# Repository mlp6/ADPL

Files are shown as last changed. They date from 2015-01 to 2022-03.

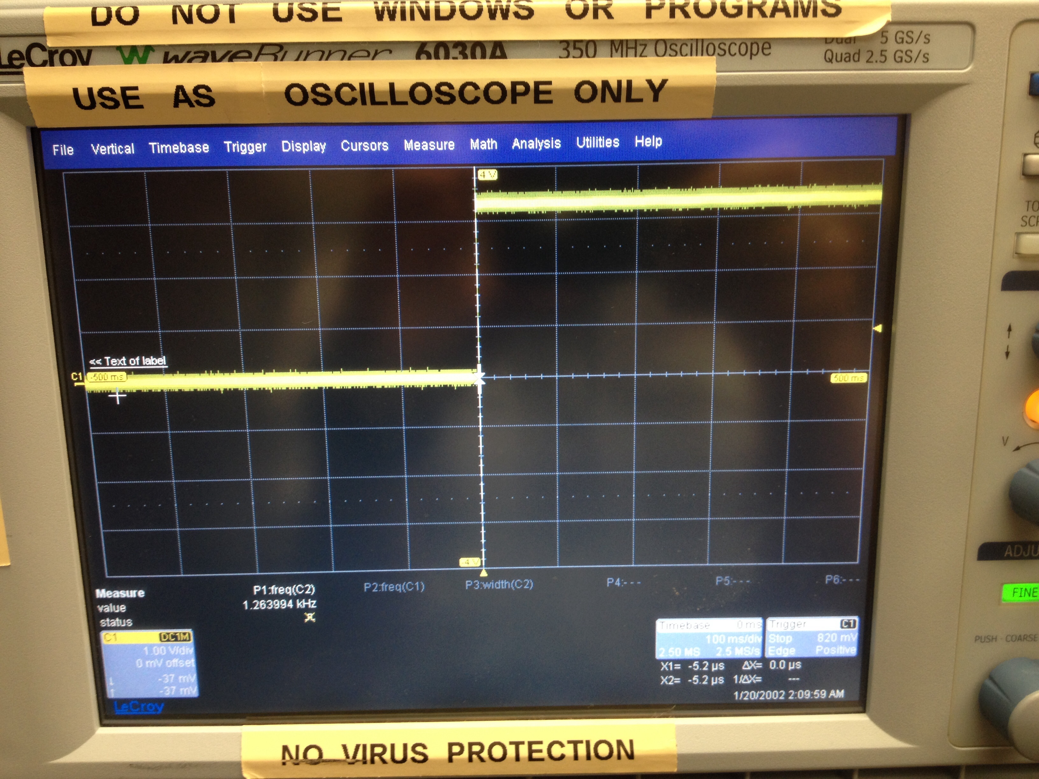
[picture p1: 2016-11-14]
hardware/picture_aids/one-shot-test/oscopeoutput1.jpeg

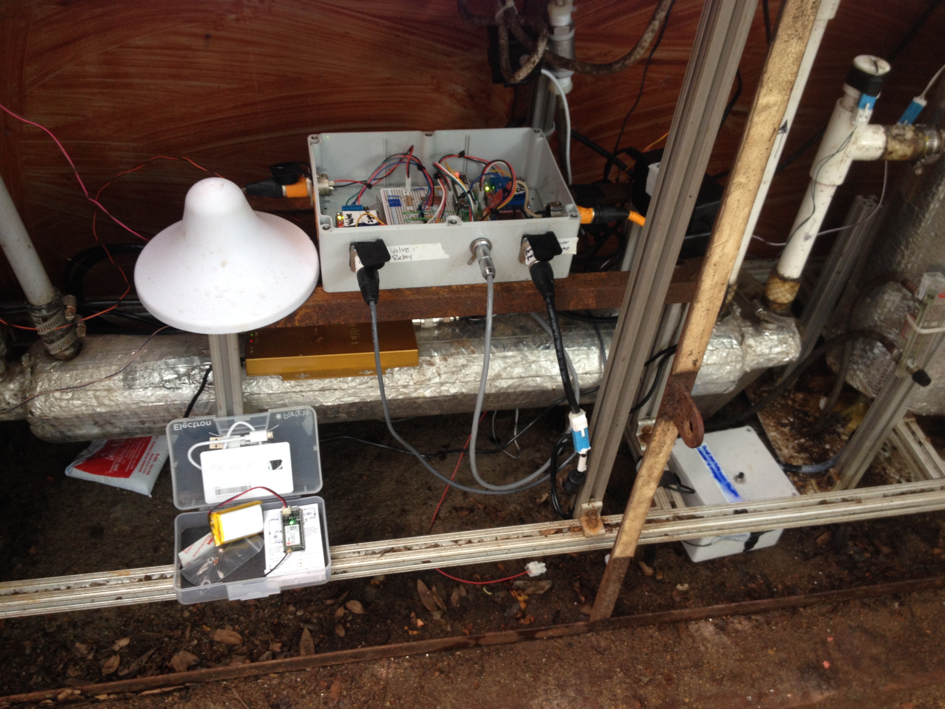
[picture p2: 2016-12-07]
hardware/picture_aids/FieldPics/IMG_8696.JPG

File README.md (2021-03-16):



# Anaerobic Digestion and Pasteurization Latrine (ADPL) 

Project Overview: http://sanitation.pratt.duke.edu/onsite-treatment

**This project is dormant, and the web server has been taken offline.**

## Particle Electron (MCU)
The active MCU software is in `software/ADPL_electron` using the `v6.2.0` Electron firmware.

## Web Server
~~Live data streaming is available to view at http://adpl.palmeri.io.~~

The web application is responsible for listening to real-time streaming data from different ADPL stations, saving that data to a database, and making those data available for inspection and analysis via a RESTful API and dashboard-like front end. The web server performs several additional functions like integrating with Twilio to allow for text-based alerts and interaction (with many features yet to be implemented). 

### Backend (NodeJS) Docker Setup
The server can be run using `docker-compose` with the following steps: 
1. `cd software/cloud-dashboard/`
2. `DB_DATA=/scratch/adpl/data docker-compose up`

### Frontend (ReactJS) Configuration
The frontend is manually built, and its assets captured by the Docker backend.  After changes are made to the frontend, you need to:
1. `cd react-client/`
2. `npm install`
3. `npm run build`
4. Repeat the Docker setup above, adding the `--build` option to `docker-compose up --build` to rebuild the image.

## Data Download
As simple as: http://adpl.palmeri.io/api/data/temp/1

## Contributors
- Aaron Forbis Stokes (a.forbis.stokes@gmail.com)
- Daniel Hull
- Suyash Kumar (suyash.kumar@duke.edu)
- Graham Miller
- Cal Nightingale
- Jawad Hoballah
- Mark Palmeri (mlp6@duke.edu)

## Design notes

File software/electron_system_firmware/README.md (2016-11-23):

How to Flash Electron Firmware OTA
==================================

* Download parts of desired firmware release from: https://github.com/spark/firmware/releases  There are usually 2-3 parts of ``*.bin`` firmware that need to be downloaded.

* With a functional and logged-in particle CLI client, you can then flash the device over the air with the syntax: ``particle flash $DEVICE_ID $FIREMWARE_PART#.bin``, where ``$DEVICE_ID`` is the electron (by name or numeric ID).  You need to execute this command sequentially for each "part" of the binary firmware.

* The device should automatically reboot after each incremental flash.

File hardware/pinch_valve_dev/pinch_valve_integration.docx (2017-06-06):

Designed and Implemented by Graham Miller, Aaron Stokes, and Daniel Hull

Guided by Dr. Palmeri

Pinch Valve Integration

This document has been written to produce a written documentation of the integration of the pinch valve into the anaerobic digestion pasteurization latrine. With hope, this document will help streamline the groups thoughts and ensure robust development of a motor that will produce the desired outputs.

The problem statement can be most aptly understood from a plot. Please observe the green HTR line. The temperature probe is monitoring the inside of the pasteurization system. As the current system is designed, the microcontroller works to hold temperatures between 68 and 72 degrees to effectively eliminate bacterium from the processed effluent. The sudden drop in temperature is a resultant of an influx of fluids into the pasteurization system. This occurs from a large onset of individuals using the bathroom at consistent patterns daily, notably for instance the hours of 6-10 A.M. Without controlled flow, an influx of waste fluids at room temperature can cause the pasteurization system to destabilize. Several problems occur from this, the waste has not been adequately digested, and the pasteurization does not work efficiently. A controlled valve system could solve this problem.

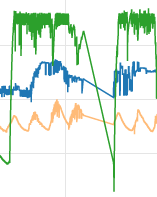
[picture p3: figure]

The controlled valve system has been designed to use a linear stepper motor. (Seen here http://www.omc-stepperonline.com/nema-23-noncaptive-linear-stepper-motor-56mm-body-150mm-lead-screw-t11-x-2-p-150.html) This bipolar stepper has the following specs (2.0 A rated, a recommended voltage of 24-36 V) An adjustment of the stepper motor step wise can move up and down a screw that pushes down or opens flow through a master flexing tube. This tube through lab testing has the following flow properties.

There appears to be a clear exponential rate in flow rate as a function of the stepper motor from the closed position. The vision is to control of the stepper motor from an Easy Driver(ED) board. (https://learn.sparkfun.com/tutorials/easy-driver-hook-up-guide) Notable specifications of the Easy Driver include a maximum of 750mA per phase or 1.5 A for the bipolar arrangement. The ED board contains options for microstepping, which we will not use. It will have a power input of 6V to 30V. A 12V power supply should suffice. The power supply should be able to supply a spec of 2A. It can supply a maximum load voltage of 30V. The ED board responds to input digital logic of 0-5V on two pins (DIR and STEP) which set the direction and step amount respectively. The maximum step frequency is 500KHz. A microcontroller board will control the digital outputs to the ED with three pins utilized, one for each of the DIR, STEP, and SLEEP pins.

The system should be responsive to these sudden changes in the amount of liquid waste as to adequately allow for flow to enter throughout the day. The system will feedback from a number of bucket tips per a unit time. The length of time will determine the sensitivity by which the step motor will adjust flow rate. As this new flow is over the course of tens of minutes to hours, the time will need to be over the course of minutes. Responsive code will be implemented in a C++ class and implemented in the .ino file.

Key system failures introduced by this valve would be a full closure as to prevent backup in the digester. Monitoring where the current position is in software or a lack of bucket tips are potential software approaches to ensure failure of this nature doesn’t happen. It’s important to note control boards and stepper motors of the ED nature must be isolated from dust. One important consideration is that the ED generates a lot of heat if used constantly. This will need some circulation as to prevent the operating conditions to exceed its designed standard. Sleep functionality implemented in the prototype also seemed to reduce the heating of the ED board. The board did not get even close to warm when this functionality was implemented. The pins of the linear step motor from the ED board must be in precise orientation. Any variation results in improper control of the linear step motor. If the linear step controller were to get off, and move all to the top I have gotten the pin stuck in that position before. Resetting the position and monitoring the position will be important.

A link to a pdf that I found issue for common stepper motor failures is the following. (http://www.anaheimautomation.com/manuals/forms/Common%20Causes%20for%20Step%20Motor-Driver%20Problems.pdf)

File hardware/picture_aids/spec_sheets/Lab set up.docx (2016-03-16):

Arduino Lab Setup

Arduino Board Pins

- Pin 2 – Valve
- Pin 4 – Pump
- Pin 7 – Ignitor
- Pin 8 – Level sensor low
- Pin 10 – SD card
- Pin 13 – Level sensor high
- Analog 0-4 – Thermistors 1-5
- Analog 5 – Level sensor 4-20 mA
- 3.3V – Red line goes to power line on breadboard
- Ground – Black line goes to ground line on breadboard
- AREF – Red to positive line on breadboard (analog positive line)

Breadboard Connections

Thermistors

- One end of each goes to ground line (here connected to black wire)
- Other end goes in series of red wire – resistor – analog input wire
- Other end of resistor goes to power line
- Thermistor 1: Red C5, Resistor B5-Power 2, Analog A5-A0
- Thermistor 2: Red E8, Resistor C8-Power 7, Analog A8-A1
- Thermistor 3: Red C11, Resistor B11-Power 10, Analog A11-A2
- Thermistor 4: Red E14, Resistor C14-Power 12, Analog A14-A3
- Thermistor 5: Red C17, Resistor B17-Power 15, Analog A17-A4

Pump

- Pump relay signal – Pin 4
- Pump relay ground – Ground 6
- Pump relay power – Power 1

Level Sensor – Sends signal when below low and above high/analog 4-20 mA output

- Depth positive (red) – To power supply
- Depth negative (black) – To power supply
- Depth relay common (brown) – 0+13
- Depth relay high (purple) – Pin 8
- Depth relay low (yellow) – Pin 13
  - Or
- Negative line from sensor to B23, 100 Ω resistor C23 to D21, Negative power E21
  - Analog wire A21-A5

Ignitor/Value

- Ignitor Signal – Pin 7
  - Facing issue with small current flowing through Pin 7, temporary set up
  - Pin 7 to A26 – Resistor C26 to C29 – Signal E26 to Board – Wire E29 to Ground 30
- Valve Signal – Pin 2
- Positive – Power 25
- Ground – Ground 23

Arduino commands

- Valve – output
- Ignitor – output
- Pump – output
- MinDepth & MaxDepth – input

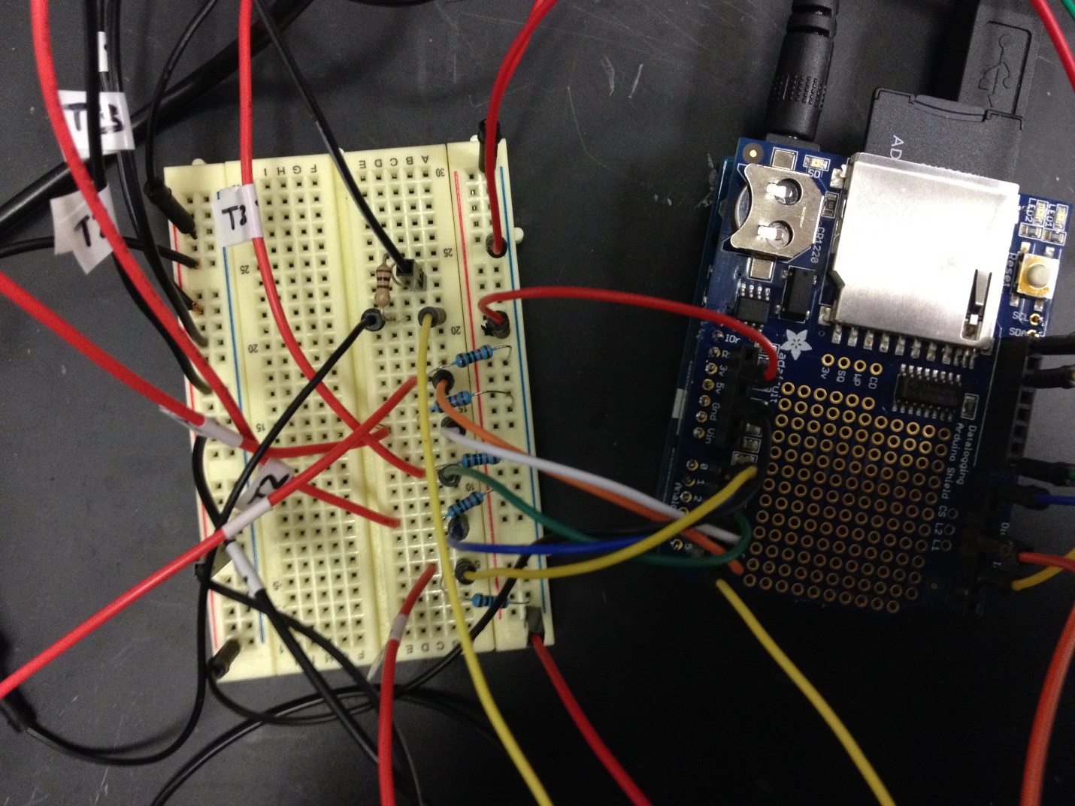
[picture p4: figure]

5 thermistors, Red to 10K resistor

5 thermistors, Black to ground

Ground

AREF

Level power

Level sensor

3.3V

Material Specs

Arduino Uno

- Input: 7-12VDC
- Operating voltage: 5VDC
- DC Current per I/O Pin: 40mA
- DC Current for 3.3V Pin: 50mA

Relay

- 2 Channel 5V Relay Shield (http://www.amazon.com/SunFounder-Channel-Shield-Arduino-Raspberry/dp/B00E0NTPP4) module for Arduino

Gas valve – CWX-15Q, CR-02

- (Size?) NPT threads, Max pressure 1 MPa, Max temp 100 °C
- Input: DC 12V, Max 167 mA (Max 2W)
- Available from: Alibaba (http://www.alibaba.com/product-detail/CWX-15Q-series-3-4-SS304_1809778717.html)
- $15
- Three wire: Red-power, Blue-ground, Yellow-signal

Ignitor – Grill Pro Universal Electronic Ignitor Kit (20620), Model SD-E5

- Input: DC 1.5V, 280-320 mA (0.42-0.48 W)
- Output: 10 kV
- Available from: Grillpro.com or Amazon (http://www.amazon.com/GrillPro-20620-Electric-Button-Igniter/dp/B000FJVKNM)
- $25

Level Sensor

- Input: DC 24V (or 12V), 2 mA (0.5 W consumption); 400Ω max loop resistance
- The 4-20 mA output can be used to provide the proportional level of liquid in any tank or vessel. The 4 relays can be used to control multiple combinations of pumps, valves and/or alarms. The signal can be connected to any device that accepts a loop powered 4-20 mA signal or relay output, such as a PLC, SCADA, DCS, display, controller, etc
- Output: 4-20 mA (when loop powered)
- Range: 5-125 cm (2-49”)
- Accuracy: 3 mm
- Temp range -7-60 °C (31-140 °F), Max pressure 30 psi
- 1” NPT thread
- The red and black wires can be extended up to 1,000 feet using a 22 gauge or larger wire, however do not extend the green and white wires
- Available from:
- $$

Pump – SeaLand TW-Series (T12) Macerator Pump

- Input: DC 12V, 6 A (48 W)
- Flow: 1136 L/hr
- Lift: 3 m (10 ft)
- Fittings: 1 – 1 ½”, not threaded, use rubber reducing bush to adapt to PVC
- Available from: Amazon (http://www.amazon.com/SeaLand-Sanipump-Discharge-Macerator-Whisper/dp/B000XBH2D4)
- $300

Valve wiring diagram:

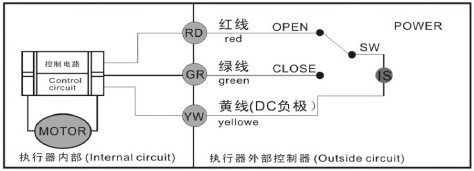
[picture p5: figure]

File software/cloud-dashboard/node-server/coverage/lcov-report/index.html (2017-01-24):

# All files

34.44% Statements 31/90

0% Branches 0/14

9.09% Functions 2/22

36.9% Lines 31/84

File | | Statements | | Branches | | Functions | | Lines
node-server | | 50% | 10/20 | 100% | 0/0 | 33.33% | 2/6 | 50% | 10/20
node-server/api | | 10% | 2/20 | 0% | 0/8 | 0% | 0/8 | 12.5% | 2/16
node-server/config | | 16.67% | 1/6 | 0% | 0/2 | 0% | 0/1 | 16.67% | 1/6
node-server/handle-device | | 18.75% | 6/32 | 0% | 0/4 | 0% | 0/7 | 20% | 6/30
node-server/models | | 100% | 8/8 | 100% | 0/0 | 100% | 0/0 | 100% | 8/8
node-server/tests/handle-device | | 100% | 4/4 | 100% | 0/0 | 100% | 0/0 | 100% | 4/4

Code coverage generated by istanbul (http://istanbul-js.org/) at Wed Jan 18 2017 23:22:50 GMT-0800 (PST)

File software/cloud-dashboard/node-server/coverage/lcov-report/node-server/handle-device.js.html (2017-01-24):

# All files / node-server handle-device.js

50% Statements 10/20

100% Branches 0/0

33.33% Functions 2/6

50% Lines 10/20

1
2
3
4
5
6
7
8
9
10
11
12
13
14
15
16
17
18
19
20
21
22
23
24
25
26
27
28
29
30
31
32
33
34
35
36
37
38
39
40
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

1x
1x
1x

1x
1x
1x

1x
1x
1x

1x

/*
* handle-device.js
* This module handles listening to the particle device stream and saving received data
* in real time to the database (LogEvent models). It also has capability to send push
* notifications to clients using socketio when new packages arrive.
* @author: Suyash Kumar <suyashkumar2003@gmail.com>
*/
var EventSource = require('eventsource'); // Pull in event source
var TempUtil = require('./handle-device/temp-util');
var BucketUtil = require('./handle-device/bucket-util');

function handleTemperatureMessage(message, io) {
try {
const parsedData = TempUtil.parseMessage(message);
TempUtil.addRecord(parsedData, io);
} catch (err) {
console.log("ERROR: Parsing Temps Message", message, err);
}
}

function handleBucketMessage(message, io) {
try {
const parsedData = BucketUtil.parseMessage(message);
BucketUtil.addRecord(parsedData, io);
} catch (err) {
console.log("ERROR: Parsing BUCKET Message", message, err);
}

}

function handleStream(deviceUrl, io){
var es = new EventSource(deviceUrl); // Listen to the stream

// Add temperature event listener
es.addEventListener("TEMPS", (message) => {
handleTemperatureMessage(message, io);
});

// Add bucket tip listener
es.addEventListener("BUCKET", (message) => {
handleBucketMessage(message, io);
});

es.onerror = function (err) {
console.log("ERROR (Likely Event Source)");
console.log(err);
};
}

module.exports = {
handleStream, // Export handleDevice function
handleTemperatureMessage,
handleBucketMessage
}

Code coverage generated by istanbul (http://istanbul-js.org/) at Wed Jan 18 2017 23:22:50 GMT-0800 (PST)

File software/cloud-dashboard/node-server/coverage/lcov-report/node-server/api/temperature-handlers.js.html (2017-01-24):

# All files / node-server/api temperature-handlers.js

10% Statements 2/20

0% Branches 0/8

0% Functions 0/8

12.5% Lines 2/16

1
2
3
4
5
6
7
8
9
10
11
12
13
14
15
16
17
18
19
20
21
22
23
24
25
26
27
28
29
30
31
32
33
34
35
36
37
38
39
40
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

1x

1x

/*
* temperature-handlers.js
* Module to hold all API functions dealing with temperature
* events
* @author: Suyash Kumar <suyashkumar2003@gmail.com>
*/
var TemperatureEvent = require('../models/temperature-event');

module.exports = {

list: function(req, res){
TemperatureEvent.find({}, function(err, records){
if(err) res.send(err);
res.json(records);
});
},
listLocAll: function(req, res){
TemperatureEvent.find({loc: req.params.loc}, function(err, records){
if(err) res.send(err);
res.json(records);
});
},
listLoc: function(req, res){
TemperatureEvent.find({loc: req.params.loc})
.sort({time:-1})
.limit(9000)
.exec(function(err, records){
if(err) res.send(err);
res.json(records);
});
},
listLastNDays: function(req, res) {
const currentDate = new Date();
//TODO: add validation on req.params.days
currentDate.setDate(currentDate.getDate() - parseInt(req.params.days));
TemperatureEvent.find({loc: req.params.loc, time: {'$gte': currentDate}})
.sort({time: -1})
.exec((err, records) => {
if(err) res.send(err);
res.json(records);
});
}

}

Code coverage generated by istanbul (http://istanbul-js.org/) at Wed Jan 18 2017 23:22:50 GMT-0800 (PST)

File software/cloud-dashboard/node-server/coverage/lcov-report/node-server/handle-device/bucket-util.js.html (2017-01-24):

# All files / node-server/handle-device bucket-util.js

23.08% Statements 3/13

0% Branches 0/2

0% Functions 0/3

25% Lines 3/12

1
2
3
4
5
6
7
8
9
10
11
12
13
14
15
16
17
18
19
20
21
22
23
24
25
26
27
28
29
30
31
32
33
34
35
36
37
38
39
40
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

1x
1x

1x

/*
* handle-device/bucket-util.js
* A set of utility functions used to parse and save
* bucket events published from ADPL systems.
* @author: Suyash Kumar <suyashkumar2003@gmail.com>
*/

var BucketEvent = require('../models/bucket-event');
var locMap = require('../config/device-map.js').locMap;

/*
* addRecord
* Responsible for adding a bucket-event record
* to the database
*
* @param {object} parsedData: Output from parseMessage below
* @param {object} io: socketio object
*/
function addRecord(parsedData, io) {
var newBucketEvent = {
coreid: parsedData.coreid,
time: new Date(parsedData.published_at),
loc: locMap[parsedData.coreid],
data: parsedData.data,
}

console.log(newBucketEvent);
var newRecord = new BucketEvent(newBucketEvent);
newRecord.save(function(err, event) {
if (err) console.log("error saving bucket event to database", err);
});
io.emit("BUCKET", newRecord);

}

/*
* parseMessage
* Parses bucket event published data from
* ADPL devices.
*
* @param {object} Particle publish message
* @return {object} Parsed data
*/
function parseMessage(message) {
deviceData = JSON.parse(message.data);
deviceData.data = parseInt(deviceData.data);
return deviceData;
}

module.exports = {
parseMessage,
addRecord,
}

Code coverage generated by istanbul (http://istanbul-js.org/) at Wed Jan 18 2017 23:22:50 GMT-0800 (PST)

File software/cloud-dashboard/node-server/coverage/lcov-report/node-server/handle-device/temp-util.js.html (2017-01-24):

# All files / node-server/handle-device temp-util.js

15.79% Statements 3/19

0% Branches 0/2

0% Functions 0/4

16.67% Lines 3/18

1
2
3
4
5
6
7
8
9
10
11
12
13
14
15
16
17
18
19
20
21
22
23
24
25
26
27
28
29
30
31
32
33
34
35
36
37
38
39
40
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

1x
1x

1x

/*
* handle-device/temp-util.js
* A set of utility functions used to parse and save
* temperature events published from ADPL systems.
* @author: Suyash Kumar <suyashkumar2003@gmail.com>
*/
var TemperatureEvent = require('../models/temperature-event');
var locMap = require('../config/device-map.js').locMap;

/*
* addRecord
* Responsible for adding a temperature-event record to
* the database.
*
* @param {object} parsedData: See output from parseMessage function below
* @param {oject} io: socketio object
*/
function addRecord(parsedData, io){
var newTemperatureEvent= {
coreid: parsedData.coreid,
time: new Date(parsedData.published_at),
loc: locMap[parsedData.coreid],
temps: {
HXCI: parsedData.HXCI,
HXCO: parsedData.HXCO,
HTR: parsedData.HTR,
HXHI: parsedData.HXHI,
HXHO: parsedData.HXHO
},
valveStatus: parsedData.V // Null if doesn't exist
}

console.log(newTemperatureEvent);
var newRecord = new TemperatureEvent(newTemperatureEvent);
newRecord.save(function(err, event){
if(err) console.log("error in saving to database"+err);
})
io.emit(newTemperatureEvent.probeid, newRecord);
}

/**
* parseMessage
* Responsible for parsing a Particle Temperature Publish
* message from the ADPL platform. A sample message
* looks like:
* {
* "data": {
* "data":"HXCI:18.9,HXCO:21.8,HTR:80.6,HXHI:22.7,HXHO:19.0",
* ""ttl":"60",
* "published_at":"2016-12-02T06:18:25.026Z",
* "coreid":"4b0031000d51353432393339"
* }
* }
* This function returns a map of all the transducer fields to
* corresponding values along with published_at and coreid
* (e.g. {HXHO: 100, ... , coreid: "", published_at: ""})
* @param {object} message
* @return {object} a map of data fields to their values (including transducers)
*/
function parseMessage(message) {
deviceData = JSON.parse(message.data);
const splitData = deviceData.data.split(",");

// Parse Transducer data
const parsedData = splitData.reduce((result, current) => {
const currentSplit = current.split(":");
result[currentSplit[0]] = currentSplit[1];
return result;
}, {});

// Add metadata
parsedData['published_at'] = deviceData['published_at'];
parsedData['coreid'] = deviceData['coreid'];

return parsedData;
}

module.exports = {
parseMessage,
addRecord
}

Code coverage generated by istanbul (http://istanbul-js.org/) at Wed Jan 18 2017 23:22:50 GMT-0800 (PST)

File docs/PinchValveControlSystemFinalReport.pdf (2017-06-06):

PinchValve Control System Final Report By Daniel Hull
With Notes for Graham, Dr. Forbis-Stokes, Suyash and Dr. Palmeri and additional relevant personnel

Final Deliverables
- Robust pinch valve software control system
- Attach Interrupt Structure for resetting system, moving up, and moving down using push-buttons
- PinchValve class with adjustable motor speed, resolution (amount in mm up or down), position monitoring and logical bounds, and cloud monitoring of the position variable, and easy to adjust parameters for further optimization
- Clog clearing control development to monitor when that may occur, adjusting net position as well if system is not clearing clog effectively.
- Bucket tip response based on differential in the previous two bucket times with four different cases
- Intense flow much greater than 10-15 L/hr, happens during clog clearing scenario, causes rapid closing adjustment
- Flow is within bounds, nothing happens
- Flow in L/hr is less than bounds, small adjustment open
- Flow in L/hr is greater than bounds but not extreme case, small adjustment closed
- Verbose naming performed throughout and hopefully good C++ practice
- Hardware Development and progress toward a completed PCB
- Investigation into whether the EasyDriver is the right board for us, notes made for optimal usage
- Schematic best practices observed and fixed for a readable professional job
- Selection of new voltage regulator in accordance with Greg Mimack’s recommendation
- Protection of the relay system with diodes also in accordance with Greg Mimmack’s recommendation w/ additional thoughts
- Beginning’s of selection of desirable PCB components both as SMTs and Through Holes
- Presentation for the Gates Foundation
- Initial Testing
- Educational Resources, notably this report as to provide an opportunity for everyone to understand the MCU and the system
- Further Development

I. Robust pinch valve software control system
A. Attach Interrupt Structure for resetting system, moving up, and moving down using push-buttons

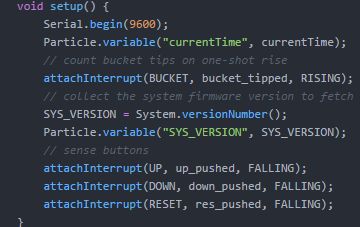
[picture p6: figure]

Setup Loop All on pinchValve_enhancement

Everything begins with the setup loop in the microcontroller code. It runs this first once the cellular connection has been enabled. Notable for us are the two bottom attach interrupt functions. Essentially it will always listen for these pins to fall while in the ‘loop’ section of the code (MCUs are always in either the setup at the beginning and then otherwise always in the loop function)

Particle Syntax for attachInterrupt

This is their syntax (the way to use them). UP and DOWN are constants set in pinmapping.h, they will execute up_pushed function and down_pushed function when their pin, usually held to 3.3V, falls to 0V. Reset’s attach interrupt will work similarly. These are the pins hooked up to push buttons. They only will happen when the push buttons are pressed. It’s how it’s all setup in the hardware.

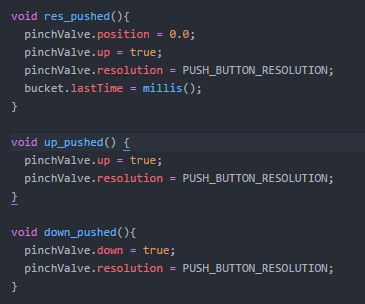
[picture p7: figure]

attachInterrupt function implementation

Here are those corresponding functions. There’s this ‘object’ known as pinchValve that you can think of like a box in the microcontroller code. There are functions (also known as methods) and variables you can access inside the box using the dot notation here. If up is pushed it sets to true and the resolution variable is set to push button resolution which is a constant. This is relevant in the loop as we will see in just a second. These functions (down_pushed, etc.) should never be activated long (a general rule of thumb), so I set the variables to do something that will cause a change when the MCU goes back into the ‘loop’. One last note, when reset is pushed the bucket.lastTime resets so the next tip time adjustment will be based around the when the reset was pushed.

The idea for the technician in the field is he/she could move the motor to the fully closed state and press the reset and it’d move to a state that will allow flow and allow the tip time control system to do its work. Given the lack of experience of many of the technicians in the field of these low-income nations, this should be a pretty simple reset.

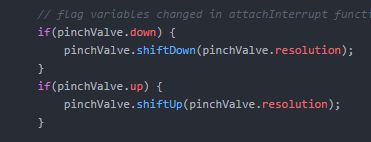
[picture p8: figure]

So here it is. We are back in the loop and if ever the pinchValve.down is true or the pinchValve.up is true (up and down are the variables inside this ‘object’ (we are calling a box)) the function inside the box will happen at the resolution that was set in the previous function! This is very dynamic because a whole range of responses could cause this such as a bucket tip or a push button pressed and it will cause the valve to move up and down by whatever is set as the resolution (mm).

B. PinchValve class with adjustable motor speed, resolution (amount in mm up or down), position monitoring and logical bounds, and cloud monitoring of the position variable, and easy to adjust parameters for further optimization

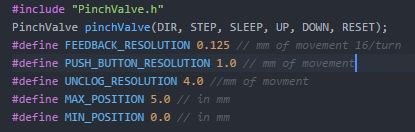
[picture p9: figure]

Here is the creation of the object (box analogy) pinchValve and the constants that were discussed earlier. In C++ #define is one way to set a variable. Right now we have mm of movement being our constants. I’m keeping it as mm of movement vs. other possible metrics because that will be constant between motors, the number of steps for the stepper motor will be variable depending on microstepping, so that is not a good metric to tell the motor to move by.

Feedback resolution, push button resolution, and unclog resolution were all variables set in correspondence with Graham who did a lot of initial testing of how flow varies as a function of of these movements about where the system is reset. The methods will translate these mm of movement into the number of turns it needs to do to get there.

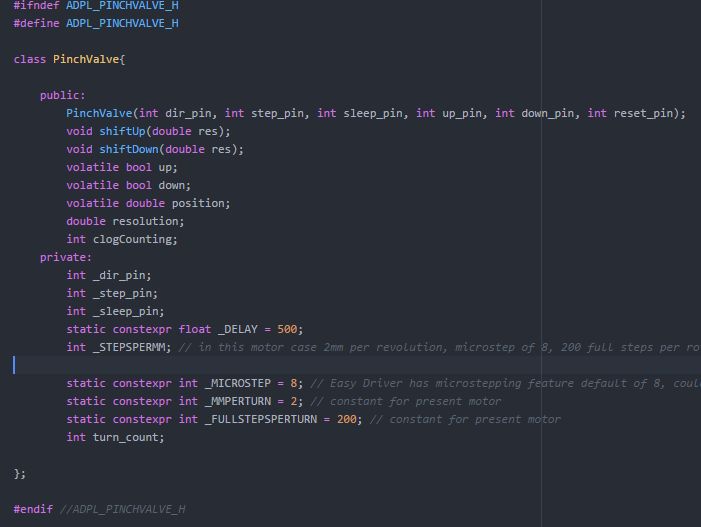
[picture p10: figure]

The header in C++ helps us define the variables for the class and the functions that can be used. The object can be accessed where the object is created. So in our case this is in the ADPL_electron.ino file for the MCU (this was defined in the figure above this). There are two public functions these are shiftUp and shiftDown. The position, up, and down are necessary in the if statements to ensure the motor works when it’s called. A true variable activates it, a false closes it. The position variable monitors the position. The resolution is set externally in the .ino file to be passed into the function which tells the motor how far to turn. The clog counter will be explained more in a minute.

Several private variables are created. The pins are only accessed in the class so they don’t need to be public. ‘_’ leads all private variables. A few are static. _Delay is in microseconds, changing this will speed up the motor. _Microstep, _MMPERTURN, and _FULLSTEPPERTURN are all used to calculate the private variable _STEPSPERMM. This all is structured to understand where the number of steps per mm comes from for whoever comes after me. This could be adjusted to a new structure if we want to change the system’s microstepping (not sure why this would be useful) or if we choose a new driver, or a new motor. It’s important to remember the three are constants under the current motor choice and driver selection and they would need to be changed if the selections changed.

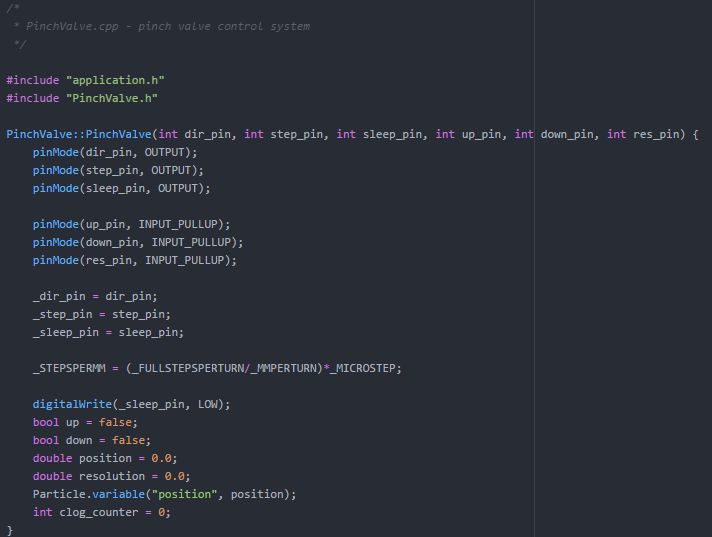
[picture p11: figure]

Constructor

PinchValve has a .cpp file in pair with its header to specify the functionality of the class more clearly. Verbose naming is used throughout. The pins are initiated at the beginning as outputs. This means digital pulses will be sent from these pins. For anyone who is unfamiliar the beginning function is the constructor. This initiated when the object is created. The pins are defined as output pins and the other three which are all the attach interrupt pins, (up, down, and reset) are set as input_pullup in agreement with Particle documentation. Up and down, components of this object, are set to false initially to make sure the motor doesn’t start trying to move up and down constantly. Again, false means resting, true means move. The steps per mm calculation is made here to show where this variable comes from. The other three pins, dir, step, and sleep are set private to this class and initialized here. The position starts at 0 when the system totally resets. This should be fixed in future iterations when the watchdog becomes available. Monitoring of this position should be available over the particle cloud. For one not familiar with the hardware, the following pins do the following

_dir_pin - sets the direction (set in pinmapping.h) (HIGH means move a direction, LOW the other) _step_pin - tells the chip to initiate steps if a cycle of LOW-HIGH-LOW happens that is at least a few microseconds (see the Easy Driver Chip Selection Datasheet)
_sleep_pin - ESSENTIAL, this turns on and off the driver to only work when a step pattern needs to be initiated.

Motors and drivers can really overheat. It’s essential these are plugged in correctly and the firmware is coded properly. Pin outputs must stay constant whether in Kenya or the Phillipines to make sure we do not have accidents.

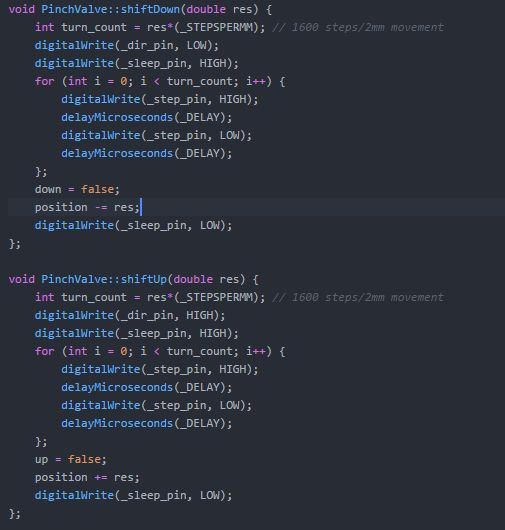
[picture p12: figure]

As seen earlier shiftDown and Up will occur when the up/down variables are set to true. The chip on the stepper driver (the EasyDriver board) responds to a series of digital pulses on its step pin. A for loop causes these pulses to be sent in a series length corresponding to how far the valve needs to move. For this instance, we should see an 800 steps per MM calculation so if the resolution is 1 MM we will see 800 cycles of the for loop telling the motor to move.

Sleep functionality makes sure the driver doesn’t overwork itself and only works when it needs to. It’s usually set low and only set high when it needs to be turned on.

Up and Down are set to false to turn off the movement once a cycle of the method is complete.

C. Clog clearing control development to monitor when that may occur, adjusting net position as well if system is not clearing clog ef ectively.

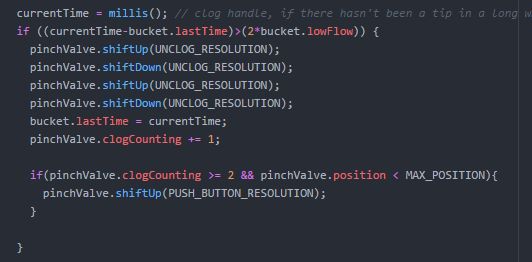
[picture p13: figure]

If a large amount of time has passed, maybe twice the lowest flow bound there is likely a clog in the system. The motor should fully open and fully close two times. This was an idea from Graham to help try to clear the clog. It will make sure to only do this once using the bucket.lastTime variable.

It will also count up one every time this process is repeated without a tip. If two have passed without a tip occurring, we will see a movement of 1 MM. Right now this is a sizeable movement. It will not move too high.

D. Bucket tip response based on dif erential in the previous two bucket times with four dif erent cases

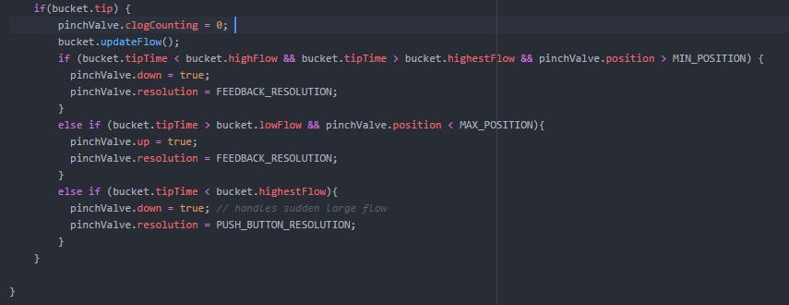
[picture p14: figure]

pinchValve isn’t the only box. An old structure of prior development is the tip variable. Like the reset, up, down pushed functions there is an Attach Interrupt for bucket. If you take a look up top in the setup function you’ll see it. It’s set to true to initiate the following action. Bucket has an updateFlow function that is then activated this calculates the differential of time between the current tip and the last tip. This is compared to desired values. More on this later.

Basically, if the tip time differential is really low i.e. high flow and the valve can still go lower (position is constantly monitoring) The down variable will be set to true and the resolution set to our 1/16th of a turn idea. (for Graham) This will close it down a little bit. If the opposite extreme happens it will open up. If the tip time is super high, potentially caused by a clog being released the resolution is set to the push button resolution and it will move down half a turn so it is very responsive to these sudden high flow events. Bounds you can see are set to make sure the system doesn’t move too high (reducing sensitivity to sudden declog events) also preventing the motor from having to work to hard by continuously trying to close a system when it’s already fully closed (all done with the position variable and the bounds, easily adjustable)

This completely summarizes the control system:
- Intense flow much greater than 10-15 L/hr, happens during clog clearing scenario, causes rapid closing adjustment
- Flow is within bounds, nothing happens
- Flow in L/hr is less than bounds, small adjustment open
- Flow in L/hr is greater than bounds but not extreme case, small adjustment closed

The development here of course depends on the updateFlow function that was created in the bucket class. Let’s cover that here.

This is the creation of the bucket object in the ADPL_electron.ino code. It depends on two constants to calculate all the desired control bounds, volume of the bucket and optimal flow. Consistent bucket size would help all of us. However, this has not been consistent to date. Front end software development could be made from the web address to have this information be pulled down every time the system is reset. This would allow customization as optimal_flow will vary area to area as a function of the number of users.

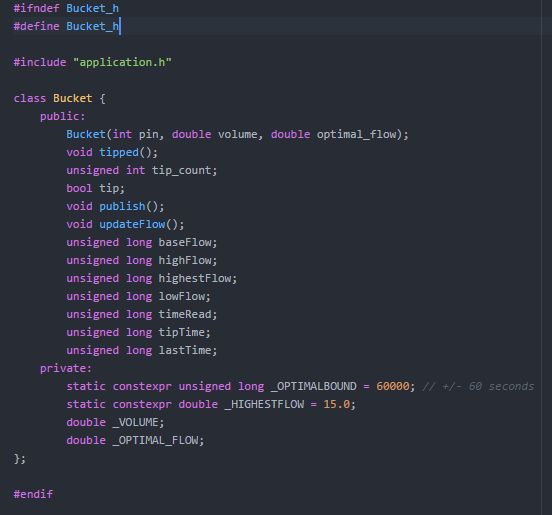
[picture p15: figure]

Here is the bucket header. There are three functions, tipped, publish, and updateFlow. updateFlow is the only new method. The rest of the variables will become obvious here in a second.

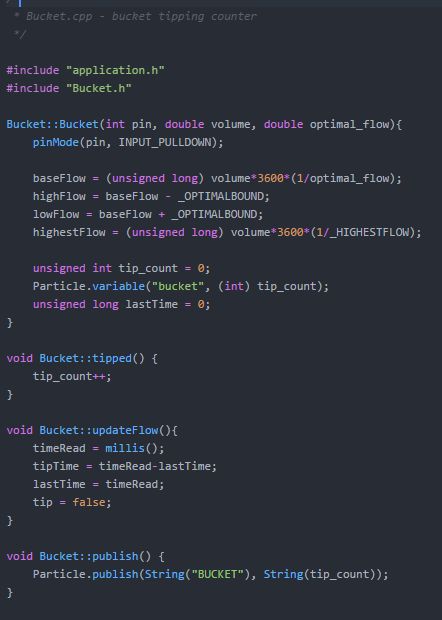
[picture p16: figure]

This is the bucket class. It’d take some dimensional analysis, but you’ll have to trust me that the calculation above will calculate a number of milliseconds that is the optimal base flow. The high and low flow are bounds set by a private variable that will have to be optimized in testing. Highest flow is the same calculation but with a different flow variable. It will be a much lower value in ms.

updateFlow is activated whenever a tip has occurred. This calculates a differential from the last tip which is then compared to the flow rates seen in the control logic here again.

clogCounting is set back to zero every time a tip has occurred.

II. Hardware Development and progress toward a completed PCB
A. Investigation into whether the EasyDriver is the right board for us, notes made for optimal usage
| The Easy Driver Board has significant advantages. It provides our desired torque at low current output. It only requires one chip, few resistors, and a single voltage regulator for the board. It does not contain any additional unnecessary components. Furthermore it provides sleep functionality and microstepping if needed but does not require those lines to be connected. This means a minimum of four lines from the microcontroller need to be made. As many boards require SPI this would require a lot more lines and coding overhead to implement. (although I do have experience should we need to)
| A simple potentiometer will need to be adjusted to provide our desired current before shipping off to any site. This seems to work without any adjustment though as the team did not know of its existence until recently.
B. Schematic best practices observed and fixed for a readable professional job

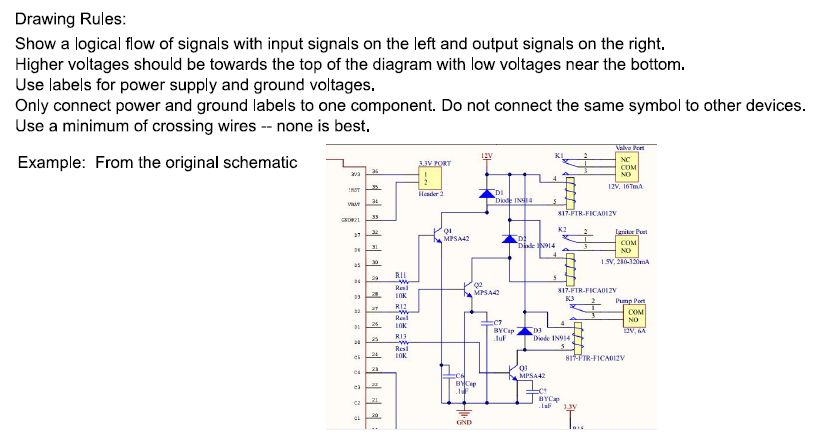
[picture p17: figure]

Greg Mimmack’s suggestions

The present schematic now obeys these drawing rules.

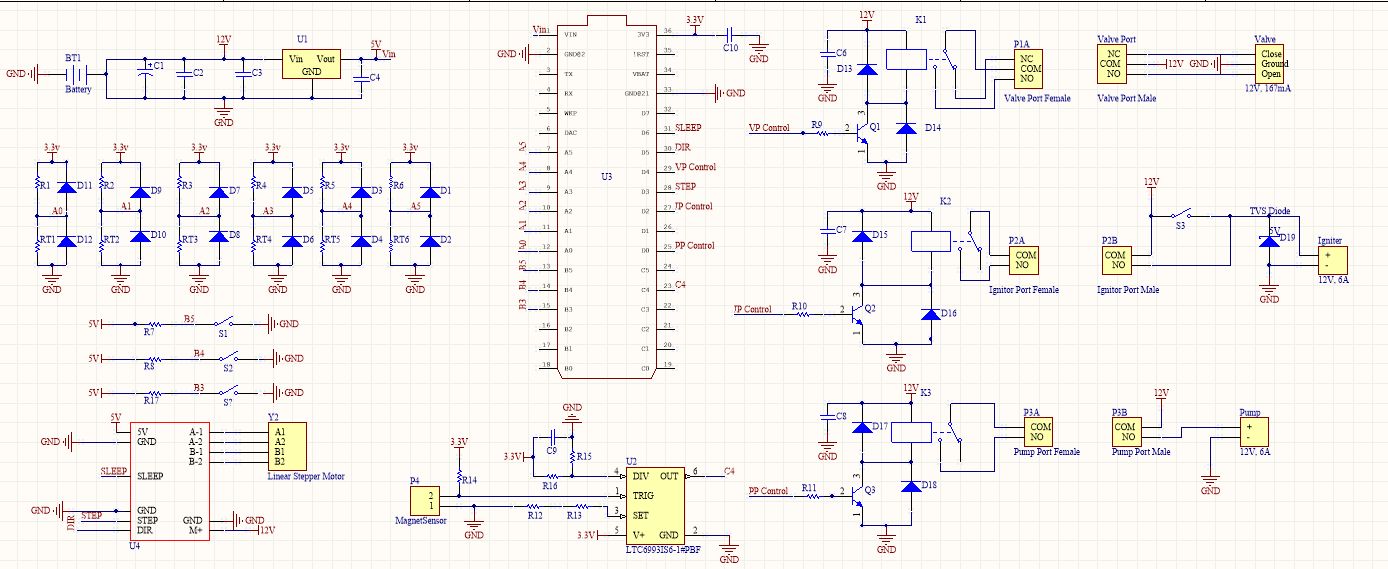
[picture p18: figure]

The use of Altium’s nets feature prevents the cross-wiring and also allows isolation of components from the microcontroller while providing a clean representation of where the microcontroller plugs into the various lines.

Of note, all new hardware components, the stepper motor, the push button switches and the driver have been added to the schematic.

All compile errors of which there were many are now fixed.

C. Selection of new voltage regulator in accordance with Greg Mimmack’s recommendation

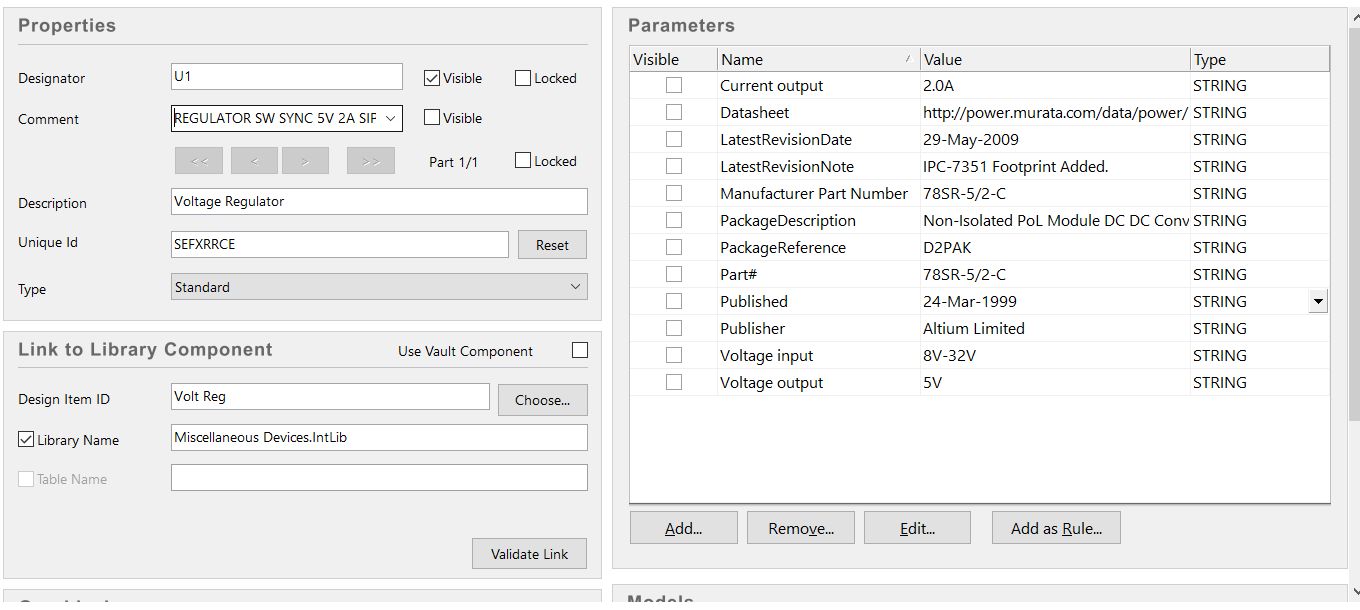
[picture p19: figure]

A View of the new selected Murata system with all useful fields populated (Datasheet, etc.)

According to Mr. Mimmack, our system regulator raised two problems, both confirmed. Our regulator was not supplying the recommended amount of current necessary for 2G operation of the particle system. The input voltage for the regulator does not match its lower limit as well.

Both of these issues are fixed under the new L78S09.

D. Protection of the relay system with diodes also in accordance with Greg Mimmack’s recommendation w/ additional thoughts

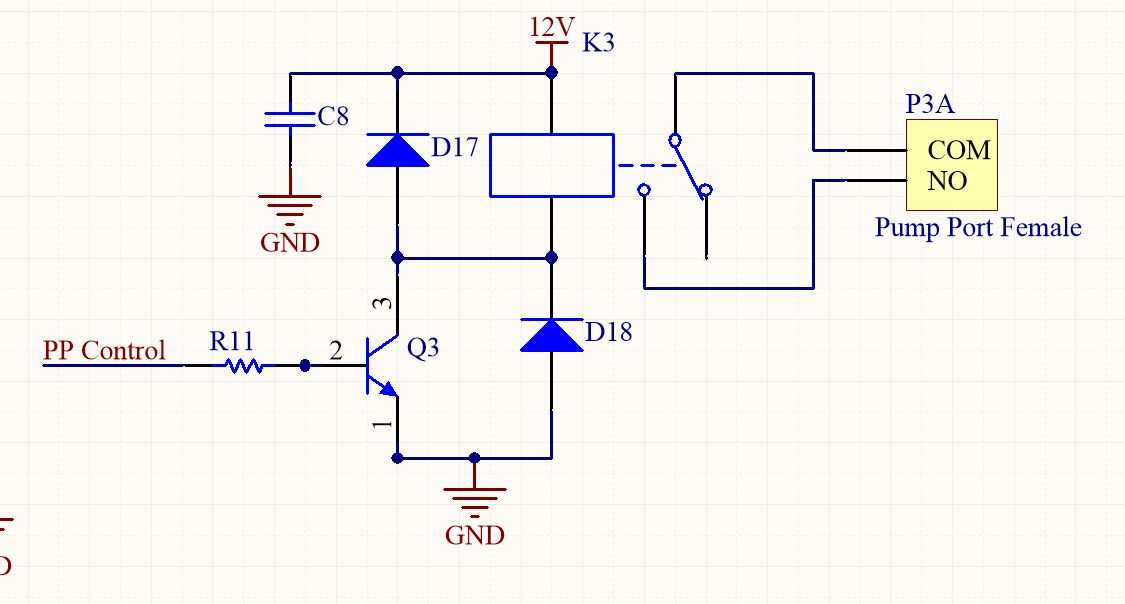
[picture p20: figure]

As inductors resist changes in current, they can often cause voltage spikes when the current is dropped when the transistor closes. Mr. Mimmack recommended that diodes be placed such that any voltage spike be shorted to the 12V/GND. Initially, he only put a diode represented here by D17. I have added D18 to prevent a negative voltage spike, resulting in a shortage to ground. This was also recommended by the reference Practical Electronics.

E. Beginning’s of selection of desirable PCB components both as SMTs and Through Holes

Potentially among the most valuable contributions, all components have their initial schematic information so that a PCB can begin. This will require building libraries of the components with their matching footprints. The PCB can then be constructed. I have experience with this and have built several functioning boards including one for an industry application.

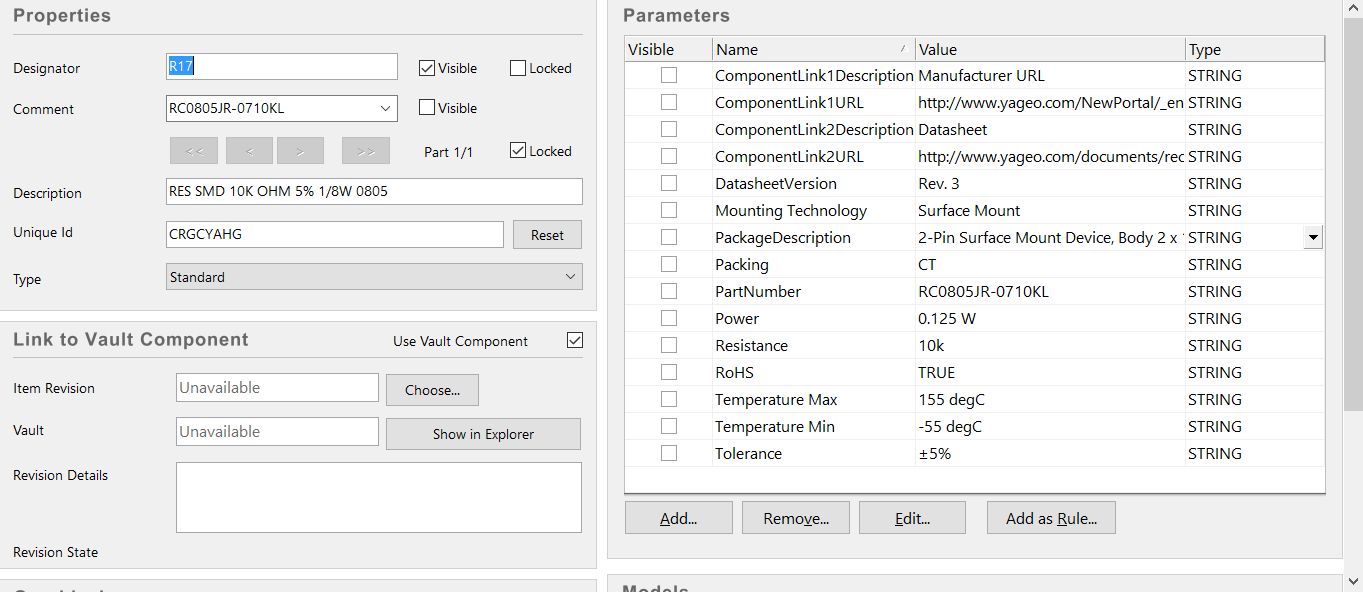
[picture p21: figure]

All fields populated, footprint model matched as well according to IPC standards

III. | Presentation for the Gates Foundation See Dropbox GatesPresentation (for Graham to send off to Lab to edit and compile what I’d done)
IV. | Initial Testing Compiling this week
V. Educational Resources, notably this report as to provide an opportunity for everyone to understand
| the MCU and the system This report!

VI. Further Development
A. Driver Combination w/ Motor
| More research should go into the following to build an ideal stepper motor driver combination. I have found these recommendations from a number of engineering sources. I Supply is >> I Load Driver I Rat. is > 1.4X maximal I Rat. of the motor* P Rat. is > 2*V Rat. * I Rat V Rat. of Motor < V of Power Supply
| A diagram should go into this to make sure our driver and motor combination is good. Unfortunately at present our motor has vague electrical specifications from the source we acquired it from. In the future, all motors should be bought from manufacturers with DigiKey, Mouser, or a big motor supplier. These have undergone more thorough review and must be categorized according to our desired parameters in a design process.
| Additionally, a PID controller could take the place of this motor system. It was not introduced until the final weeks as a potential concept.
B. PCB Design and Manufacturing
| As stated above, this should be the next direction in the hardware.

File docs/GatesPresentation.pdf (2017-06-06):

# Pinch Valve Update

# Update Summary

Hardware Features

- Inserted buttons
- manually adjusts valve position (i.e. opens/closes)
- Motor components
- chopper driver and stepper motor
- Control system
- responds to button tips

Software Features

- Control System
- Flow rate estimate: time differential from last tip
- Moves toward optimal position
- Responds with regularity
- Initial testing confirms it works well
- Target tip times from two constants
- optimal flow rate (L/hr) and bucket volume
- Reset feature
- Position will not move below fully closed and fully open (0-5 mm)

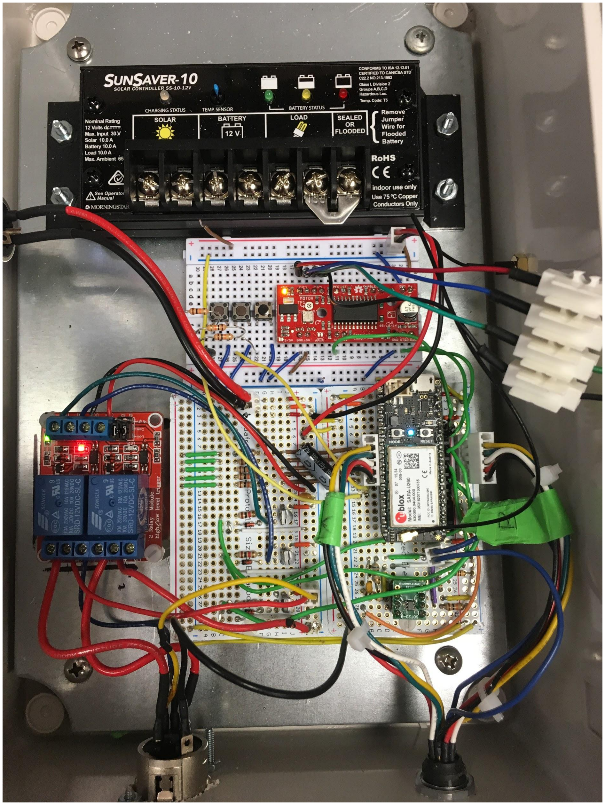
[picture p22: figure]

# Hardware

Components

- Easy Driver Stepper Board
- Linear Step Motor
- Three push buttons

Sleep function enabled a significant reduction of heat

Confirms it meets the following for proper safety of motors

- I Supply is >> I Load
- Driver I Rat. is > 1.4X maximal I Rat. of the motor*
- V Rat. of Motor < V of Power Supply

# PCB Development

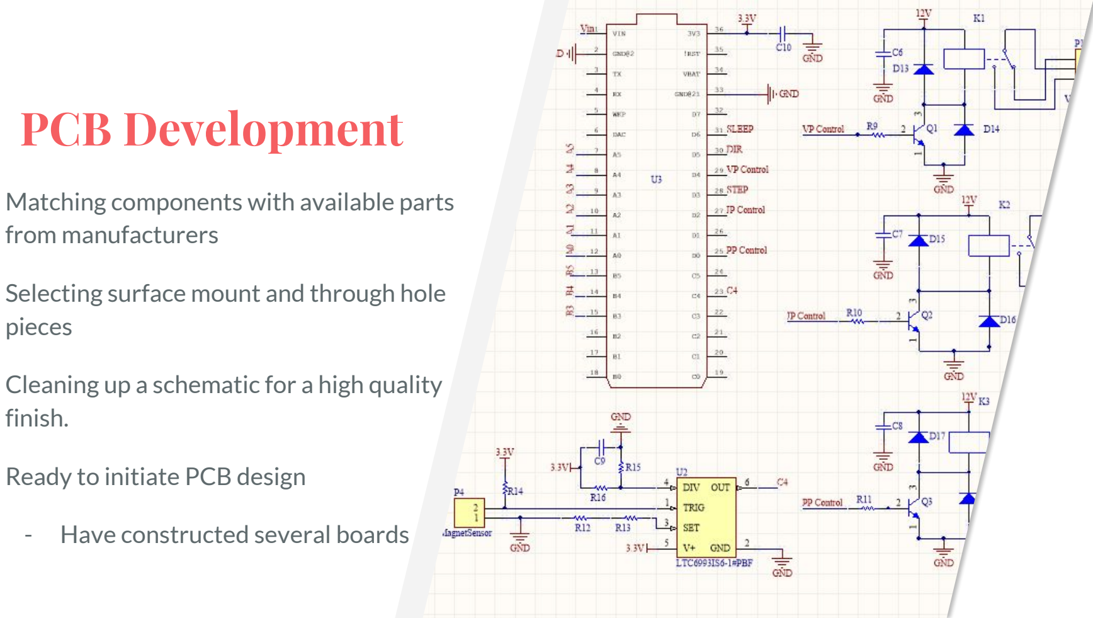
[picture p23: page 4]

Matching components with available parts from manufacturers

Selecting surface mount and through hole pieces

Cleaning up a schematic for a high quality finish.

Ready to initiate PCB design

- Have constructed several boards

# Software

Pinch Valve Class and Bucket Class Development

- Several methods, shift up, shift down, update Flow
- Constructor with pins (direction, step, sleep, up, down, reset)
- Attach interrupt scheme to sense buttons, bucket tips
- Position variable to monitor where the position is, ensures the motor doesn’t go too high in case of a clog.
- Programmable to do different size turns (e.g. ½ turn, etc.)

Envision adding prevention of clog functionality, adjustment for extremely high rates of flow that happen suddenly (~10 sec)

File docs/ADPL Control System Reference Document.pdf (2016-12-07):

Prepared by: Aaron Forbis-Stokes | December 1, 2016

ADPL Control System Overview Document

Project Overview
The Anaerobic Digestion Pasteurization Latrine (ADPL) is a concept developed by the Professor Marc Deshusses research group in the Department of Civil & Environmental Engineering. The ADPL provides sanitation by treating human waste in an anaerobic digester, followed by pasteurization of the treated effluent in a heater/heat recovery system powered by biogas produced by the anaerobic digester. The system operates by capturing the energy inherent to fecal sludge and using that energy to power its own sterilization. A schematic of the process is shown below. This project has been implemented with local partners in Eldoret, Kenya; Chennai, India; and Toledo, Philippines (pictured below in order left to right).

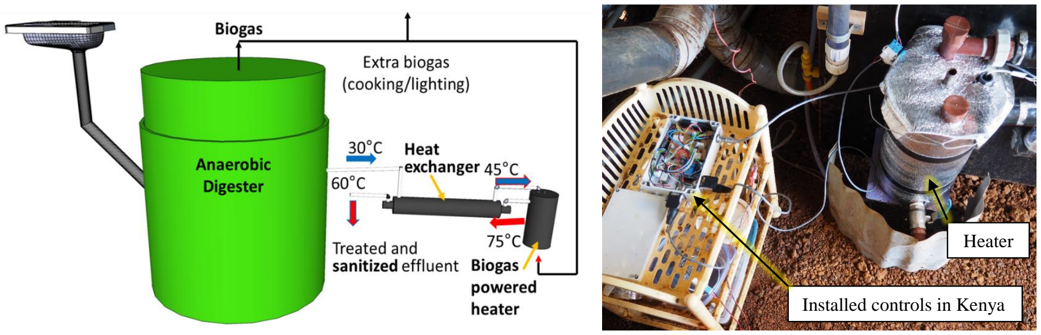
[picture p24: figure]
Installed controls in Kenya; Heater
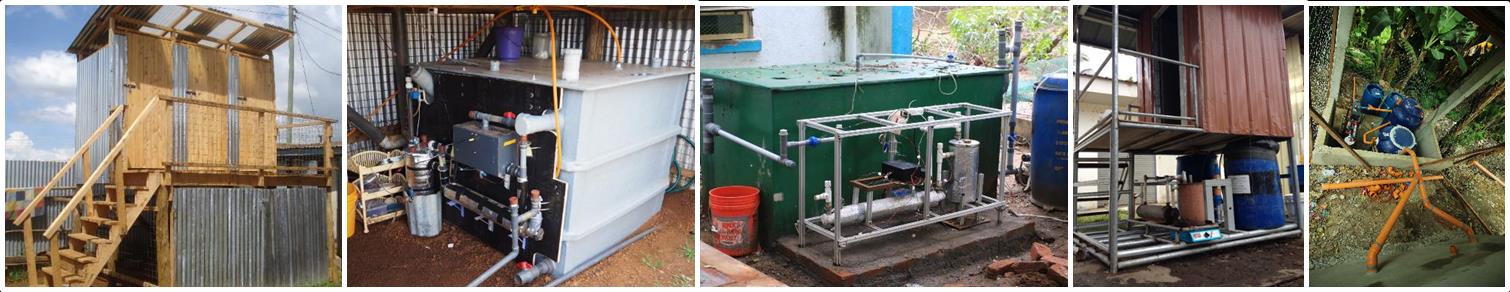
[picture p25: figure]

Controls Overview
The motivation of the controls system is to provide continuous, remote data collection and to improve the efficiency of heater operation. The Particle Electron (https://docs.particle.io/datasheets/electron-datasheet/) is used to record temperatures in the heating system and liquid flow leaving the anaerobic digester. This data is transmitted to an online server (http://dash.dukeadpl.com/). The temperature probe inside the heater is used to control the operation of a gas valve and igniter to ensure the liquid in the heater remains in the target range of 65-75 °C. The system is powered by a 20W solar panel which charges a motorcycle battery (~30Ah). Preliminary tests show that average power consumption is 1.42W throughout the day.

Hardware
Temperatures are measured using liquid immersion NTC thermistors (10kΩ resistance at 25 °C). Thermistors are placed at the inlet of cold chamber of heat exchanger (HXCI), outlet of cold chamber of heat exchanger (HXCO), inside heater (HTR), inlet of hot chamber of heat exchanger (HXHI), and outlet of hot chamber of heat exchanger (HXHO). The Dwyer I2-1B062 is used in HTR. The remaining locations use Vishay NTCAIMME3C90373 thermistors.

Liquid flow is measured using a tipping bucket flow meter where each tip of the bucket corresponds to ~300-350 mL of digester effluent. A magnet is place on the upper arm of the cantilever, and each tip is measured using a magneto-sensor. The sensor has a variable resistance that is ≥500kΩ in the resting state and ≤10kΩ when the magnet passes the sensor. The maximum count frequency is 20 Hz. A one-shot monostable pulse generator (Linear Technology TimerBlox, LTC6993-1) is used to lengthen the pulse width. The pulse duration leaving the TimerBlox is 2 seconds.

The Particle reads temperature in the heater every 2.5 minutes. If heating temperature is <68 °C, the motorized ball valve (CWX-15Q, CR-02, 3-wire; 12VDC, 167mA) is opened and igniter is turned on for 1 second. If temperature is >72 °C, the valve is closed, and the igniter timer sequence is stopped. If the temperature is 68-72 °C, the valve remains in its current state. If the valve is opened, the igniter runs on the 15 minute timer.

The igniter is an off-the-shelf electronic igniter replacement kit (Brinkman). An igniter module is powered by a 1.5VDC (AA) battery (280-320mA) and sends out 10kVDC to three igniter leads using a high voltage transformer.

The system in India is an atypical implementation that uses a 12V, 6A pump to transport fecal sludge into the digester. The pump is included in the wiring diagram and software, but it will not be replicated in future implementations.

The microcontroller, circuit board, and relays are all housed in a Hammond watertight ABS enclosure (1554HGY) and mounted on a galvanized steel panel. External hardware is connected to the enclosure using Neutrik XLR connectors, and Molex connectors are used to connect wires.

The wiring schematic is prepared in a separate document. See “ADPL Controls System Wiring Schematic.”

Constraints & Priorities
This control system is part of an onsite fecal sludge treatment system targeting low-income communities. The final treatment system must be completely off-grid and available at a cost of less than $0.05 per user per day (including capital and operational expenses). Thus, the control system must be inexpensive, use minimal power, and have a robust design that can be reliably implemented in rugged outdoor environments with no local electrical expertise.

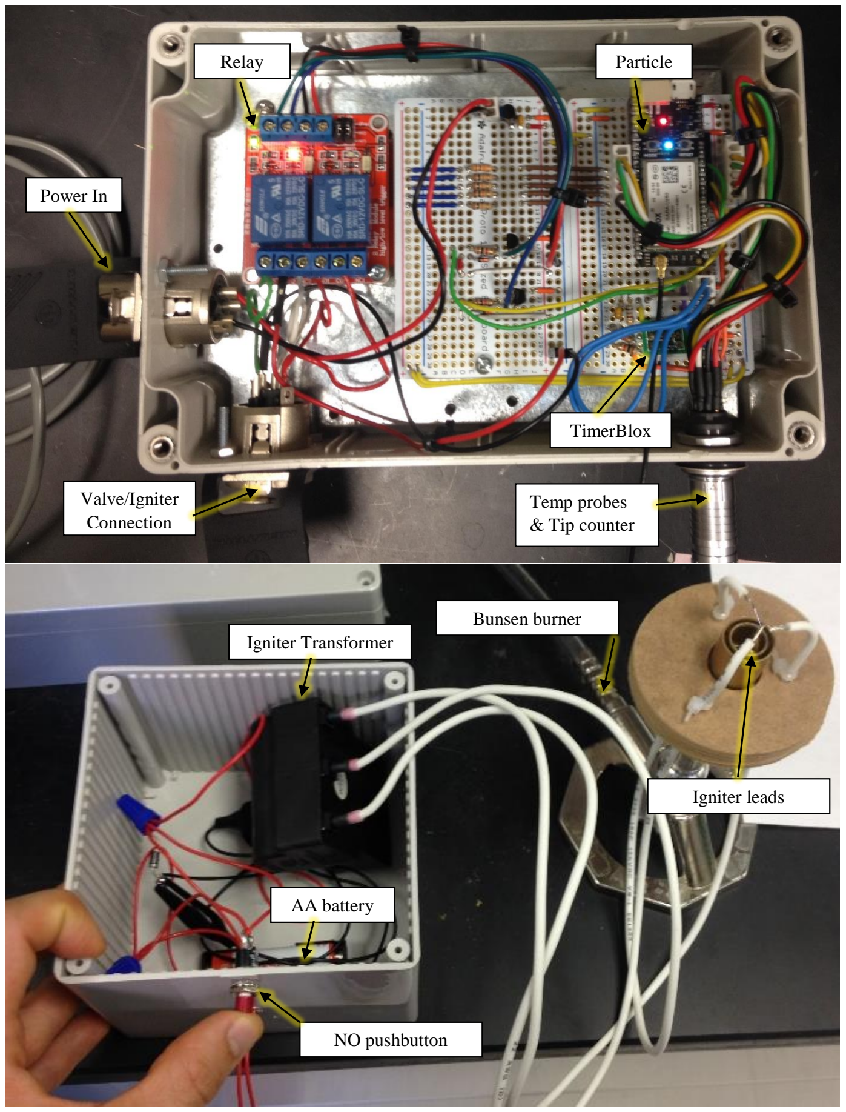
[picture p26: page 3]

Relay | Particle

TimerBlox

Power In

Valve/Igniter
Connection

Temp probes
& Tip counter

Igniter Transformer

AA battery

NO pushbutton

Igniter leads

Bunsen burner

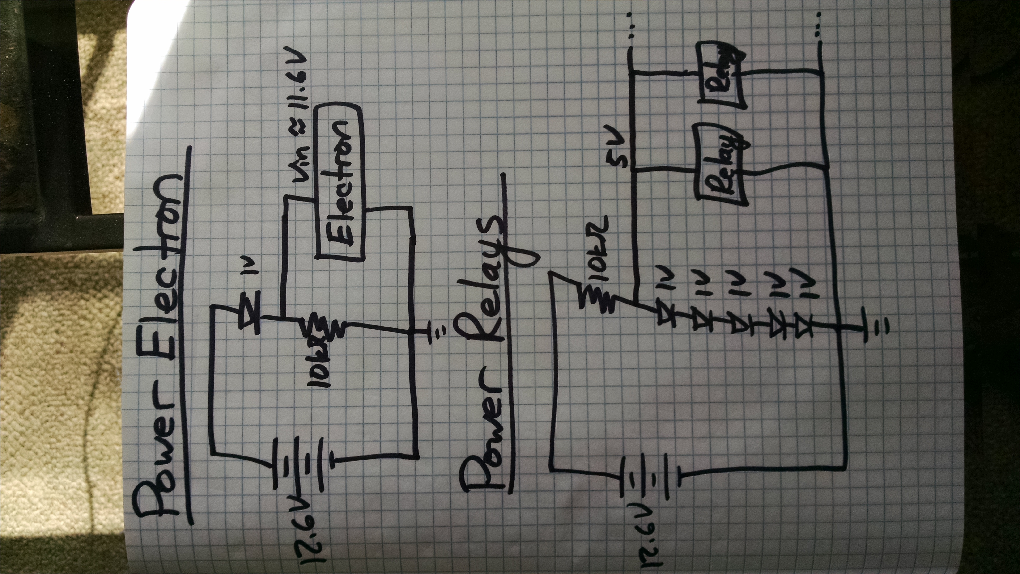
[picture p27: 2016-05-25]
hardware/picture_aids/PowerElectronRelay12p6V.jpg

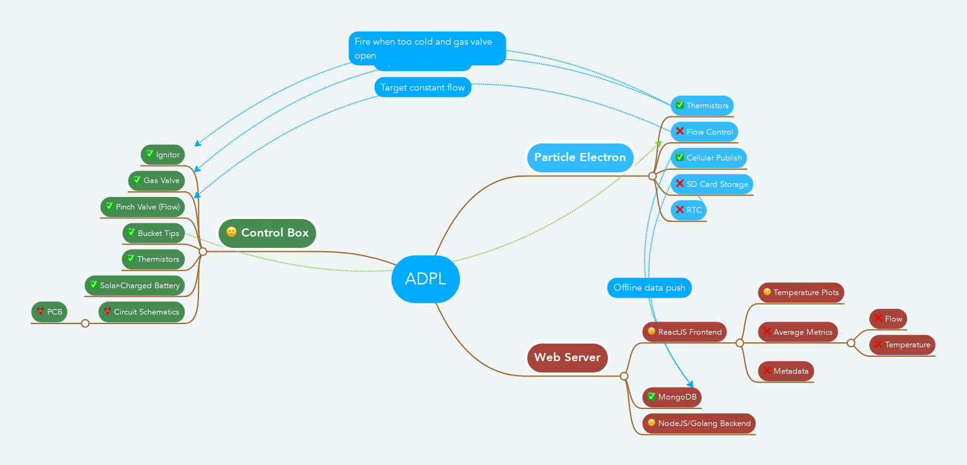
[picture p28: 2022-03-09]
docs/ADPL_Block_Diagram.png

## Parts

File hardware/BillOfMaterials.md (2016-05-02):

Bill of Materials
=================

Power Supply
------------
* India: Monitor power supply, Input: AC 100-240V; Output: DC 12V, 6A
* Kenya & Philippines: 20 W solar panel, Max Output: DC 17.5V, 0.28A with 12V charge controller; connected to 12V rechargeable battery

External Hardware
-----------------
* Valve (all locations) - Powered by same power source as micro-controller; Input: DC 12V, Max 167 mA (Max 2W) http://www.alibaba.com/product-detail/CWX-15Q-series-3-4-SS304_1809778717.html
* Pump (India only) - Powered by same power source as micro-controller; Input: DC 12V, 6 A (48 W) http://www.amazon.com/SeaLand-Sanipump-Discharge-Macerator-Whisper/dp/B000XBH2D4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
* Igniter (all locations) - Powered by AA battery; DC 1.5V, 280-320 mA, Output: 10 kV; http://www.amazon.com/GrillPro-20620-Electric-Button-Igniter/dp/B000FJVKNM

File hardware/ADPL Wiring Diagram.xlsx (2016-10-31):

Comment | Description | Designator | Footprint | LibRef | Quantity
Particle Electron footprint |  |  | ELECTRON | ELECTRON_WITH_HEADERS | 1
Battery | Multicell Battery | 1.5V | BAT-2 | Battery | 1
Header 2 | Header, 2-Pin | 3.3V PORT, 3.3V PORT, 12V PORT, 12V PORT | HDR1X2 | Header 2 | 4
Cap | Capacitor | C1, C1, C2 | RAD-0.3 | Cap | 3
Diode 1N914 | High Conductance Fast Diode | D1, D2, D3 | DO-35 | Diode 1N914 | 3
1.5V, 280-320mA | Header, 2-Pin | Ignitor Port | HDR1X2 | Header 2 | 1
 | Header, 2-Pin | IGNITOR, Ignitor Port, Pump Port | HDR1X2 | Header 2 | 3
Relay | SPDT Relay | K1, K2, K3 | MODULE5B | Relay | 3
Volt Reg | Voltage Regulator | L78S12CV | D2PAK_N | Volt Reg | 1
SW-SPST | Single-Pole, Single-Throw Switch | NO Pushbutton Switch | SPST-2 | SW-SPST | 1
MagnetSensor | Header, 2-Pin | P3 | HDR1X2 | Header 2 | 1
12V, 6A | Header, 2-Pin | Pump, Pump Port | HDR1X2 | Header 2 | 2
2N3904 | NPN General Purpose Amplifier | Q1, Q2, Q? | TO-92A | 2N3904 | 3
Res1 | Resistor | R1, R2, R3, R4, R5, R11, R12, R13, R13, R14, R15, Thermistor1, Thermistor2, Thermistor3, Thermistor4, Thermistor5, TimeSet, TimeSet2 | AXIAL-0.3 | Res1 | 18
LTC6993 | Header, 6-Pin | TIMER PORT | HDR1X6 | Header 6 | 1
12V, 167mA | Header, 3-Pin | Valve, Valve Port, Valve Port | HDR1X3 | Header 3 | 3

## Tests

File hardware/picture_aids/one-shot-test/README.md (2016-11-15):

Test the output of the one-shot to help figure out why we might be missing
bucket tip events.

O-scope screen captures of the one-shot output after a simulated bucket tip
event are shown in the images in this directory.

Note that:
* The output pulse is ~2 s in duration.
* The voltage during the rect output is relatively stable.

It turns out that the issues w/ the missed events were due to the slow exection
of ``loop()`` b/c of the 5 temp probe reads.  This was addressed in spefcific
software modifications.

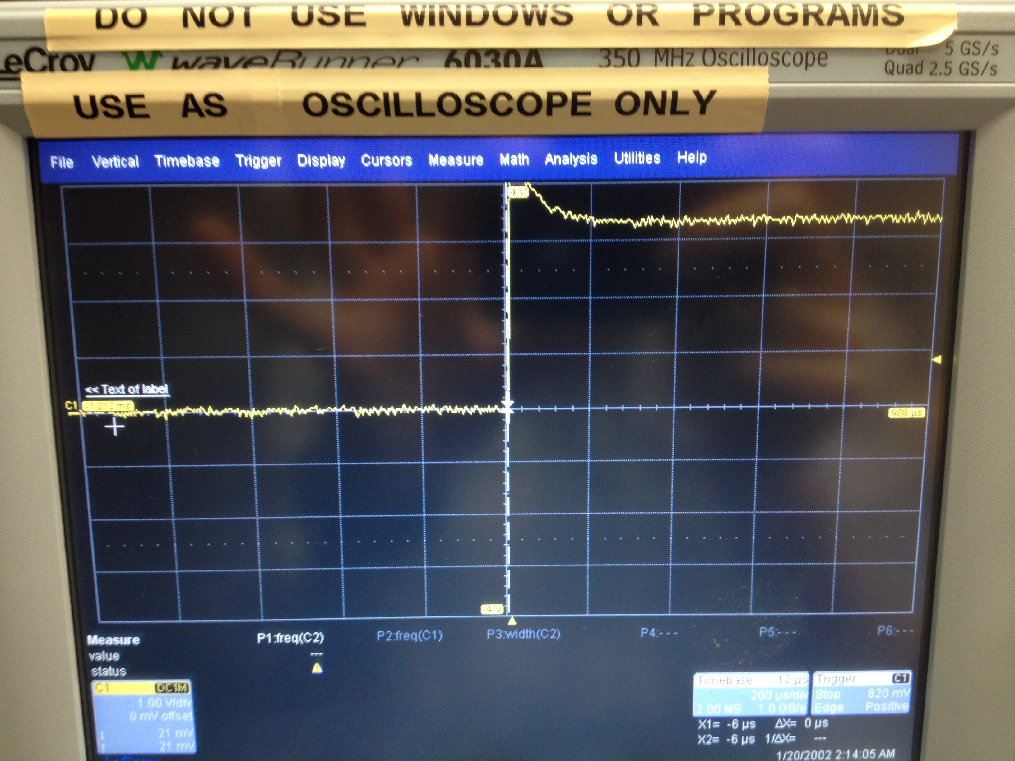
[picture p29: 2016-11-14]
hardware/picture_aids/one-shot-test/oscopeoutput.jpeg

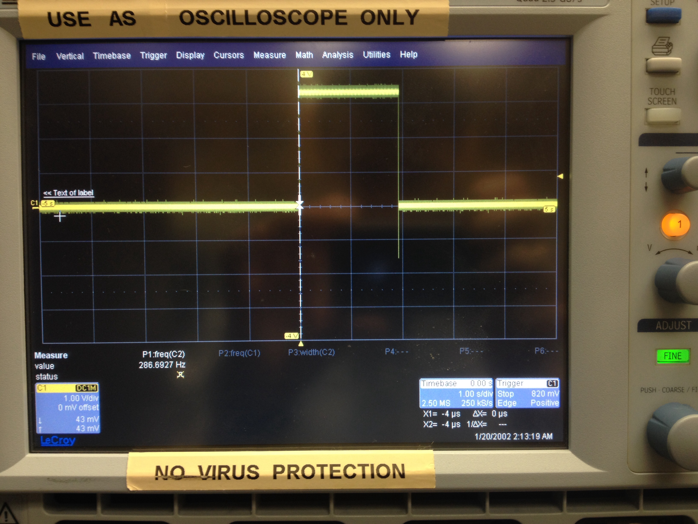
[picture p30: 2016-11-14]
hardware/picture_aids/one-shot-test/oscopeoutput2.jpeg

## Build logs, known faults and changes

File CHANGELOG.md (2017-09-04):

CHANGELOG
=========

* Will need to review the git history for tags <= electron_v2.1.0

electron_v2.2.0
---------------
* Unify pin mappings across all devices
* Rework the web data publish (DATA JSON string)
* Update delays for the ignitor and pump
* Rename the field devices based on location / update device IDs

v2.5.0
------
* Ignitor thermistor reignition control
* SD card writing (data and error log)
* Handle damaged thermistors that report negative temperatures
* Implement control over attempting cellular connection

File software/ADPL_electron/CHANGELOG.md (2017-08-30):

CHANGELOG
=========

pre-electron-v2.1.0
-------------------
* See the git commit history / tagged comments for notes.

electron_v2.2.0
---------------
* Drop the 'electron' prefix since everything is electron-based now.
* Remove level-sensing.

electron_v2.4.0a
----------------
* Daniel's pinch valve functionality

v2.5.0RC1
----------
* Change pinch valve functionality to binary mode for unclogs
* SD card functionality using SdFat
* Exhaust thermocouple for ignitor control

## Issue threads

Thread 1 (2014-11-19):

3 thermistors work instead of 5 on analog inputs

mlp6, 2014-11-19:

mlp6, 2015-01-29:
Power output issues on the Arduino might be causing lots of spurious behavior... need to made the hardware (and software) a lot more modular.

mlp6, 2015-03-10:
A4 and A5 of Aaron's UNO were reading 5V when in analog input mode.  Swapped out UNO for one of mine and works now.  No issues with voltage division, etc.  Using the 3.3 V supply to reduce PS noise instead of using Wheatstone bridges for each thermistor.

Closed 2015-03-10.

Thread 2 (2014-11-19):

Analog level sensor will not read

mlp6, 2014-11-19:
The analog reading of the level sensor (output is variable current that I run through a resistor for voltage reading) is not being read by the Arduino, though it can be read by a multimeter.

mlp6, 2015-01-29:
Analog current from the water meter is not being properly fed into the Arduino analog input as a voltage.  Need to investigate whether this could be done digitally while still preserving the dynamic range of the measured level.

mlp6, 2015-03-10:
Fixed by connecting GND of thermistor sub-circuit to GND for the level sensor.

Closed 2015-03-10.

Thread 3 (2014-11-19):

Pump / Ignitor Timer Conflicts

mlp6, 2014-11-19:
Running the pump and ignitor on separate timers that will not conflict has been challenging.

mlp6, 2015-01-29:
This problem should be resolved by the independent power circuits with digital out pin control for each.

mlp6, 2015-03-10:
@aforbis-stokes do you have any details on the errors that you are getting when you try to get both of these timers working?

aforbis-stokes, 2015-03-10:
This is probably just a weakness of mine in coding, but when I try to have the pump run for a certain amount of time, everything else waits for that to complete. Same with the ignitor turning on, everything else waits for that to complete.

mlp6, 2015-03-10:
Okay - we should be able to deal with that.  Is ```ADPL_complete.ino``` your latest working version (i.e., I shouldn't look at ```ADPL_labsetup.ino```)?

aforbis-stokes, 2015-03-10:
Correct, ADPL_complete is the latest.

mlp6, 2015-03-10:
I will take a look at it now... keep an out out for some commits, etc.  I do _not_ have an Arduino with me right now, so I won't be able to test for bugs that I might introduce in syntax, etc.

mlp6, 2015-03-10:
I found a few areas of the code that we can really streamline, which I will tackle right now.  Question - line 85 of ```ADPL_complete.ino``` has a ```delay()``` call in the loop, but none of the other loops do; is that for a reason, or do you just need a general delay between readings?

My first optimization will be to consolidate your temp probe readings a lot to be more readable and modular, but I want to check about that ```delay()``` quickly.

aforbis-stokes, 2015-03-10:
That comes from the example code in the Thermistor guide document. It had a delay between the readings that I assumed did not need to happen between reading each probe but needed to happen somewhere in the loop.

mlp6, 2015-03-10:
~60% done; have a meeting now, but will get back to this ~1 PM.

mlp6, 2015-03-10:
The issue w/ the conflicts in the activation of the ignitor or pump delaying subsequent execution is related to the use of serial ```delay()``` commands that will pause ```loop()``` until the specified delay has elapsed, which is *not* the desired function.  Instead, we need to activate these components and continue to loop and check when to turn them off, rather than delay things.  I will implement this on the ```ignitor``` branch, and will then do the same for the pump.

mlp6, 2015-03-10:
@aforbis-stokes Is it true that everytime you use the ignitor that the following steps occur:

1. Turn on the ignitor
2. Hold it on for 5 sec
3. Turn off the ignitor

Do you ever not activate the ignitor that way?

aforbis-stokes, 2015-03-10:
Correct. Off for 15 min before turning on again.

It should also only be on when the valve is open (T<72)

mlp6, 2015-03-10:
Okay - doing lots of code consolidation then, and hopefully making all of it more modular and readable for long-term maintenance.  I'm on a conference call now, but concurrently coding.  Hoping to get you something to test soon.

mlp6, 2015-03-10:
@aforbis-stokes Can you inspect lines 98-123 for the code in the ```ignitor``` branch to see if my logic for the valve / ignitor make sense?  You can choose what branch you are on from the GitHub repository webpage if you don't have it on your local computer.  I don't want to break the ```master``` branch with non-functioning code (yet).   I replaced some of the loop code with functions that "do" what you want (at the end of the file).

aforbis-stokes, 2015-03-10:
Yes, I follow the logic. Seems a little more simple than what I was trying to do.

mlp6, 2015-03-10:
Great... now onto the pump.  Then you'll be on the hook the test everything.  :)

mlp6, 2015-03-10:
@aforbis-stokes For the water level, if you are at an intermediate level, and you have turned on the pump for 5 min, do you want to impose the 55 min off time even if the level goes above your max threshold or only impose the 55 min off time if the level remains in the intermediate state?

Would it be bad to just keep the pump on until at the min level and give it some hysteresis so it doesn't keep turning on and off right around that threshold?

aforbis-stokes, 2015-03-10:
For the first, I was assuming the level would not change that quickly, so I was ok with the pump being off 55 minutes, but if it's a simple change to come on if it does reach that threshhold, then that would be a good fix.

Second, are you saying pump on until min instead of a timer? I don't think that would work so well, but some hysteresis around the thresshold would be good.

What I am hoping is to get the pump to operate so that the flow into the system is the same throughout the day (5 min every hour) while the level would rise during high use periods and drop over night, but trying to stay between the min and max.

Closed 2015-03-10.

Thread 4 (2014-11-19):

Digital LOW -> Relay Throw

mlp6, 2014-11-19:
Enough current flowing through some of the digital pins to switch my relay even when the setting is LOW.

mlp6, 2015-01-29:
Going to change all of the digital outputs to BJT -> relay cascade for power isolation.

Closed 2015-03-10.

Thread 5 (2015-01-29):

get BJTs and relays from Matt; breadboard too

mlp6, 2015-01-29:

mlp6, 2015-03-10:
These are working.  Need to replenish Matt's supply.

mlp6, 2015-03-10:
@aforbis-stokes We need to replenish Matt's components... do you have a source where we can order these for your replication needs, etc.?

aforbis-stokes, 2015-03-10:
I have only used Radioshack and Amazon to buy components. I have a PO code for our grant so can order more on my own or provide that code.

aforbis-stokes, 2015-03-16:
I have done more hardware checks. I found 3 relays that go up to 14 VDC at Radioshack to replace the other relays. While checking these, I found that 2 of the 3 BJTs no longer work. Are there more of these available that I can continue tests with? I figure once I have everything completely running for a longer test, I will buy duplicates and replenish Matt's supply.
Also, what do we need to do to fabricate a board?

sphaerobolus, 2015-03-16:
I could provide some more BJTs. I'm in the Teer basement, the '0' level. I'll be here today until about 4:00.

aforbis-stokes, 2015-03-17:
@sphaerobolus I picked up some 12VDC relays that are similar to the 5VDC ones you supplied. They do not have the 87a prong (Normally closed), and one of my components needs to switch between normally open/normally closed. Do you have any relays around that can operate under 12VDC have both connections?

sphaerobolus, 2015-03-17:
@aforbis-stokes I think I can supply that. Stop by when you get a chance. Also, bring one of your relays--I'd like to confirm the missing NC pin. That a relay is missing said pin surprises me.

Closed 2016-01-12.

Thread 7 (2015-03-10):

refactor probe temperature reading code

mlp6, 2015-03-10:
Right now, in ```loop()```, to following steps are performed serially:

1. Sample data on each probe
2. Average data on each probe
3. Convert each average to temperature (C)

The same exact operation is being performed for each probe, so will write a new ```probeTempRead()``` function that will do all of the "action" and then just loop for each probe in ```loop()```.

mlp6, 2015-03-10:
@aforbis-stokes Can you check that the code that I just pushed up to GitHub works for reading all of the temperature sensors still?  I refactored it a bunch, but wanted to make sure I didn't break any function.  I did verify that it will compile.  I will keep working on the other function in the mean time.

aforbis-stokes, 2015-03-10:
Still works!

mlp6, 2015-03-10:
That is amazing and almost never works when you blindly code!  I'm cleaning up more... need to run to another meeting in a few min, but will be back at it in a bit.

Did you see how the code got condensed?  Is it still readable from your perspective?

aforbis-stokes, 2015-03-10:
I see what you did, and there are some commands I am unfamiliar with, but I think I get it.

Closed 2015-03-10.

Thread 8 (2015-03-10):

functional testing

mlp6, 2015-03-10:
Latest code in the master branch is ready for testing.  As before, I wrote all of this blindly, but did verify compilation of the code.

Once the code is in a fully-functional form, we can explore the final phase of making it truly modular, but if we don't get to that milestone, you will still have a fully-functional version of code before your trip in a few weeks.

You can create Issues for any bugs that you encounter and aren't sure how to fix; otherwise please edit away and let me know when the code is "ready".

mlp6, 2015-03-11:
I am actively working on this a bit more, so hold off on testing this evening if you can and try in the morning.

aforbis-stokes, 2015-03-11:
I've been trying to get the code to compile, but referencing the libraries is not working for me.

This error repeats for each library:
In file included from ADPL_mp.ino:4:
C:\Users\Aaron\Documents\Arduino\libraries\Pump/Pump.h:12: error: ISO C++ forbids initialization of member 'offTime'
C:\Users\Aaron\Documents\Arduino\libraries\Pump/Pump.h:12: error: making 'offTime' static
C:\Users\Aaron\Documents\Arduino\libraries\Pump/Pump.h:12: error: ISO C++ forbids in-class initialization of non-const static member 'offTime'

mlp6, 2015-03-11:
Working on it... very strange since this will compile on my system just fine.

mlp6, 2015-03-11:
Give it a try now with the latest version on the ```master``` branch.

aforbis-stokes, 2015-03-11:
Have the program compiling/uploading/running on the Arduino.
The temp probes are working a little crazy. Here is the serial monitor output:

88.91, 43.48, nan, nan, 45.72, 0, 0
406.00
nan, 58.10, 54.07, 44.30, 62.26, 0, 0
410.00
nan, 82.67, 74.16, 58.76, 94.64, 0, 0
410.00
nan, nan, 129.28, 83.34, nan, 0, 0
409.00
47.69, nan, nan, -273.15, nan, 0, 0
410.00

mlp6, 2015-03-11:
Were those temp numbers more stable yesterday?

aforbis-stokes, 2015-03-11:
Yes, they were pretty constant. No "nan" outputs, all values staying around 22 or 23.

mlp6, 2015-03-11:
Give it a try now...

aforbis-stokes, 2015-03-11:
New output below. Previously 1 second between readings, now 5 seconds between.

nan, nan, nan, nan, nan, 0, 0
403.00
44.61, nan, nan, nan, 44.38, 0, 0
404.00
60.77, 56.99, 55.13, 55.74, 60.31, 0, 0
405.00
90.90, 80.54, 76.14, 77.55, 89.50, 0, 0
405.00
nan, 222.36, 143.30, 157.28, nan, 0, 0
404.00
nan, nan, nan, nan, nan, 0, 0
403.00

mlp6, 2015-03-11:
I love making things worse.  :)  Okay... I'll look at this a bit more.  What would be your preferred time b/c readings?

mlp6, 2015-03-11:
Give it a try now... I realize that I never set the samples and average private members to 0 for each new ```read()``` call, which was probably causing all sorts of issues.

aforbis-stokes, 2015-03-11:
I'm ok with 5 second between readings. I'm storing readings on a 4GB SD card for a week, which I believe has capacity to store these readings every second, but that amount of data is not necessary.

Timing back to 1 second between readings, but output not giving any real numbers:
nan, nan, nan, nan, nan, 0, 0
415.00
nan, nan, nan, nan, nan, 0, 0
416.00
nan, nan, nan, nan, nan, 0, 0
419.00

mlp6, 2015-03-11:
Can you test w/ the latest version... I have put some additional serial print statements in there to help me first out what is not happy.

aforbis-stokes, 2015-03-11:
Getting a compiling error. Did you only edit TempProbe.CPP ? The new folder does not come up with the .h file, but I have left the most recent in the library.

C:\Users\Aaron\Documents\Arduino\libraries\ADPLmaster\TempProbe.cpp: In member function 'void TempProbe::read()':
C:\Users\Aaron\Documents\Arduino\libraries\ADPLmaster\TempProbe.cpp:27:5: error: expected ';' before 'timeRead'
     timeRead = millis();
     ^
C:\Users\Aaron\Documents\Arduino\libraries\ADPLmaster\TempProbe.cpp:32:5: error: expected ';' before '_sampleMean'
     _sampleMean = 1023. / _sampleMean - 1.;
     ^
C:\Users\Aaron\Documents\Arduino\libraries\ADPLmaster\TempProbe.cpp:34:5: error: expected ';' before '_sampleMean'
     _sampleMean = _SERIESRESISTOR / _sampleMean;
     ^
C:\Users\Aaron\Documents\Arduino\libraries\ADPLmaster\TempProbe.cpp:38:5: error: expected ';' before 'temp'
     temp = _sampleMean / _THERMISTORNOMINAL;        // (R/Ro)
     ^
Error compiling.

mlp6, 2015-03-11:
Whoops, there was a syntax error that I introduced.  Give it a try now.

aforbis-stokes, 2015-03-11:
New output (repeats each reading):
-11425-114.25-9.95-1004.62-10889-108.89-10.39-962.02-10636-106.36-10.62-941.77-10636-106.36-10.62-941.77-11436-114.36-9.95-1005.49nan, nan, nan, nan, nan, 0, 0
418.00

mlp6, 2015-03-11:
I have reverted some of the logic I consolidated... give it a try now.  (fingers crossed)

aforbis-stokes, 2015-03-11:
New output:
0.00, 0.00, 0.00, 0.00, 0.00, 1, 0
404.00
0.00, 0.00, 0.00, 0.00, 0.00, 1, 0
404.00
0.00, 0.00, 0.00, 0.00, 0.00, 1, 0
440.00
0.00, 0.00, 0.00, 0.00, 0.00, 1, 0
451.00
0.00, 0.00, 0.00, 0.00, 0.00, 1, 0
444.00

mlp6, 2015-03-11:
Okay - another debugging copy in master - can you send me that serial terminal output?

aforbis-stokes, 2015-03-11:
Error in compiling:
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
mlp6, 2015-03-13:
WOOHOO!!  That was a typo error I had buried in the code that I found... see if the valves will work now.  And lets make a list of what ever else is wacko.

aforbis-stokes, 2015-03-13:
The Arduino output (actual signal & serial monitor) to the the valve is perfect. No signal when above 28C, once it drops below 25 there is a signal until back about 28.
The ignitor signal is a little off. It only operates when the valve is open, but the timer is more like on for 5 seconds, off 1 second, repeat.
I might need to move the set up to my lab to test the level sensor better. Without a good amount of water, it's hard to tell, and I'm nervous to do that in this electronics lab.

mlp6, 2015-03-13:
Let me check the ignitor now... if we have that working, then I think you can relocate to your lab.

mlp6, 2015-03-13:
Try now... check for more correct ignitor function, and some new serial output you can send me if we need to debug more.

aforbis-stokes, 2015-03-13:
Still the same on ignitor
1, 0
330.00
Thermistor Temperature (deg C):21.13
Thermistor Temp in loop: 21.13
Thermistor Temperature (deg C):21.81
Thermistor Temperature (deg C):21.74
Thermistor Temperature (deg C):21.57
Thermistor Temperature (deg C):22.16
1, 0
333.00
Thermistor Temperature (deg C):21.13
Thermistor Temp in loop: 21.13
Thermistor Temperature (deg C):21.81
Thermistor Temperature (deg C):21.70
Thermistor Temperature (deg C):21.56
Thermistor Temperature (deg C):22.16

mlp6, 2015-03-13:
That doesn't look like the latest code is running.  I just pushed up even more verbose code to try.

aforbis-stokes, 2015-03-13:
You're right, forgot to re-open the .ino

Ignitor last fired: 6164
Ignitor last fired: 12328
Ignitor last fired: 18493
Ignitor last fired: 24658
Ignitor last fired: 30823
Ignitor last fired: 36988

mlp6, 2015-03-13:
That still looks like an old version...

aforbis-stokes, 2015-03-13:
in class time: 6164
TOO LOW - Ignitor last fired: 6164
in class time: 12329
TOO LOW - Ignitor last fired: 12329
in class time: 18495
TOO LOW - Ignitor last fired: 18495

mlp6, 2015-03-13:
Right now it is firing all of the time b/c it is falling below the incineration low temp threshold (25 deg C), as specified on line 82.  I didn't have a test if the valve was open or closed there, so it was just refiring each time through.  I have added a test for valve status now.  See if that makes a difference.

aforbis-stokes, 2015-03-13:
Ok, I think it's good now. On for 5 seconds, been at least a couple minutes off.

mlp6, 2015-03-13:
Great... I would move the setup so you can test water level, and then maybe be able to modulate temperature to test that too.  Keep me posted... I'll be online this weekend at times.

aforbis-stokes, 2015-03-13:
Ok, I should probably head home for now and will do that in the morning. Will update you then.

aforbis-stokes, 2015-03-14:
I think this is all good! Pump and ignitor timers both working correctly, not conflicting. Signals coming from the Arduino at the right times and under the correct situations.
Removing the comment out on the serial print gives the correct display for all readings.

mlp6, 2015-03-14:
Great!  Do you need any additional functionality now that we have it in a good place?  I didn't touch the SD card parts, but those can also be significantly consolidated.  Thoughts?

aforbis-stokes, 2015-03-14:
I now have a hardware issue, though. I accidentally ran the relays with 12V instead of 5V. 2 of 3 three I think are fried. Looking at the setup and specs, I think I should replace all of them with 12VDC relays. 12VDC is an acceptable input for all components (including Arduino) except for the ignitor (1.5V, using a AA battery). I'm going to swing by Radioshack on my way home to see if they have some.

aforbis-stokes, 2015-03-14:
I need to convert the level analog reading into a height. I'm trying to follow the example of the thermistor conversion, but I think the level sensor operates a little differently.

mlp6, 2015-03-14:
Is the spec sheet in ```docs/```?  If so, then I'll take a peek at that.  I'll start a new issue for this.

aforbis-stokes, 2015-03-14:
I still don't have GitHub totally figured out. Attached is an updated
document. P3 has a consolidated spec sheet.

On Sat, Mar 14, 2015 at 12:40 PM, Mark Palmeri <notifications@github.com>
wrote:

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

Closed 2015-03-14.

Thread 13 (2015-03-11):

water levels need to be converted to inches

mlp6, 2015-03-11:
changes should be made to ```Pump.h``` and ```Pump.cpp```

mlp6, 2015-03-11:
should be done in ```LevelSensor.cpp```

mlp6, 2015-03-14:
I think the correct manual is ```docs/Mebcal6 Manual.pdf```.  Can you confirm?

aforbis-stokes, 2015-03-14:
Mebcal16 is for programming the EchoPod. The EchoPod specs are in the EchoPod manual. P. 5 says the power can be 12-28 VDC. p 19-20 describes the analog output reading

mlp6, 2015-03-14:
Okay - I'll take a look at your DipTrace schematic to see what resistor you have that current going through.  What range should the level meter be able to read (i.e., at the min and max current values)?

aforbis-stokes, 2015-03-14:
It is going through a 237Ohm resistor. I believe the current setting on the
sensor is 2" is bottom, everything below that should be 4 mA reading, 12"
is top and 20 mA is the reading at that point. I can change what levels the
4 & 20 mA outputs correspond to via the Mebcal software.

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

mlp6, 2015-03-14:
Given that, we can add a simple conversion.  I'll take care of that and push it up, and then I'll let you test, etc.

mlp6, 2015-03-14:
I have a working version on the ```level_inch``` branch that you can test.  It converts the levelCurrentmA variable to the output current from the sensor, which I'm guessing you can then convert to inches.

```LEVEL_MIN_MA``` and ```LEVEL_MAX_MA``` are the thresholds, in mA, that you can set for the level thresholds.

Let me know if this works as you would like.

aforbis-stokes, 2015-03-16:
This looks perfect.

Closed 2015-03-16.

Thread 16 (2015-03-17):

Hardware Board Design

mlp6, 2015-03-17:
@aforbis-stokes What is your timeline / when do you leave for your trip to have a board done?  (I will be gone Fri - Wed.)

We have a few options for board design to consider:
* Use perf board to mount all hardware, with wire / solder connections.
* Layout a printed circuit board with DipTrace that we could either etch in-house or send out to be etched.

Perf board might be totally fine for this since you don't have any surface-mount components.  PCBs would be great if you had to replicate a lot, but you only need 1 for the near future, correct?

aforbis-stokes, 2015-03-17:
I leave on Sunday morning.

Perfboard is probably good. This is something that I will want to replicate at a later time, but I just need one to take with me (and remaining lab setup) for now.

mlp6, 2015-03-17:
@sphaerobolus might have some scraps of perfboard looking for a new home that could be donated to this project (and then replaced at some point)... if not, then we should have some in the lab that I can dig up.  Going this route, then you won't need to use DipTrace to route anything.  I would just create a logical layout on the perf board, similar to what you've done on the Breadboard.  We have soldering irons in the lab that you can use to wire it up / test.  We might also have some extra enclosures sitting around; how large of a box might you need to hold all of this?

The last thing is what connectors you want to use to connect the thermistors, etc. to the circuit.  Do you have some terminals in mind?

aforbis-stokes, 2015-03-17:
I was thinking something like 6"x6" for the box, and for connecting the thermistors to the circuit I thought I would solder them.

However, I think this is something where someone more experienced could probably give a quick look at my set up and recommend something much better than what I have thought of or am aware of.

sphaerobolus, 2015-03-17:
I do have some perfboard scraps.

Closed 2016-01-12.

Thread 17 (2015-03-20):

compiled memory

mlp6, 2015-03-20:
As it was, compiled code took ~110% of available memory.  Aaron reduced to ~99%, but we need more breathing room for variable space.

aforbis-stokes, 2015-03-27:
Update on the Arduino/SD card. When I call the setup code for the SD card back in, the rest of the program does not run. I first saw I was not getting information on the serial monitor and thought it was just the print command conflicting, but the output pins no longer work either.

Looking at the most recent code on GitHub, lines 59-60 (below) are what bring up this issue. Lines 49-55 were other parts that I called back in, but I can have them in without affecting operation.

    pinMode(10, OUTPUT); //SD card pin
    dataFile = SD.open("datalog.txt", FILE_WRITE);

aforbis-stokes, 2015-03-28:
New update on SD card. I have changed some of the coding, and I have a working version. However, if I try to run too much, the serial monitor stops working, and if I include everything, the code gets stuck in the initial loop. I am sending 2 .ino files via email.

"ADPL_tempSD": This file only considers 3 temperature probes (no other hardware/functions). It works exactly how it should.
"ADPL_tempSD": If I increase to 5 temperature probes, the serial monitor no longer works, but the SD card stores data correctly.
"ADPL_complete": Our total working code. Once I bring in the same SD commands as the other file, nothing works correctly. The initial loops begin (ignitor, valve) but stop and restart.

I have tried a couple different Arduinos/SD card shields and external power supply (12VDC) to not rely on the USB cable.

I am at 98% memory with the complete code. Could that be the issue? The ADPL_tempSD is at 75% for 3 probes, 96% for 5 probes.

aforbis-stokes, 2015-03-28:
Attached files referenced in last Github comment.

On Fri, Mar 20, 2015 at 12:34 PM, Mark Palmeri <notifications@github.com>
wrote:

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

mlp6, 2015-03-28:
I think this could easily be related to how much memory your code is using on the UNO.  Part of the issue is just how much memory that SD card library is consuming.  We could pick it apart to just have the pieces that you need, but not while you are there!  Could you test the unit w/o the serial monitor running (which is using memory) for a while, see that the SD card was written to, and test the function of all of the sensors / pumps / etc.?

aforbis-stokes, 2015-03-29:
Yes, tried it out this morning with all of the serial commands commented
out. Everything will work with that. Now using 94%.

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

mlp6, 2015-03-29:
Great!  Moving forward, we could transition to a different microcontroller w/ a bit more memory to work with if you plan to continue to iterate on this setup.

Are you happy w/ how it is performing?  Did you ever figure out what was going on with the 5th thermistor?

aforbis-stokes, 2015-03-29:
That might be a good idea to transition. Marc and I talked with someone
else on the same sanitation grant that uses the raspberry and uploads to a
nice interface they made. We talked about everyone syncing with that for
the Foundation to have easy access.

Happy with this. Way better than my last round as this actually works.

Still haven't figured out that last thermistor. Must be a connection issue,
though I've looked all over and tried redoing them. The breadboard set up I
have works.

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

mlp6, 2015-03-29:
Great.  You can easily add a WiFi or similar interface for upload if you have connectivity, unless SD card upload is the envisioned procedure.  We can touch base when you get back (when is that?).

aforbis-stokes, 2015-03-29:
Yes, I think wifi will be a necessary replacement as we hope to increase
the number of units we have. The SD is good for the few we have for now.

I get back this coming Friday. Will touch back in then.

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

mlp6, 2016-03-28:
Moot point since the SD card is no longer being used with the Particle platform.

Closed 2016-03-28.

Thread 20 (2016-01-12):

update part list

mlp6, 2016-01-12:
include power supplies and other misc. electronics hardware

aforbis-stokes, 2016-01-24:
Power supply:
India - Monitor power supply, Input: AC 100-240V; Output: DC 12V, 6A
Kenya & Philippines - 20W solar panel, Max Output: DC 17.5V, 0.28A with 12V charge controller; connected to 12V rechargeable battery

External hardware:
Valve (all locations) - Powered by same power source as micro-controller; Input: DC 12V, Max 167 mA (Max 2W) http://www.alibaba.com/product-detail/CWX-15Q-series-3-4-SS304_1809778717.html
Pump (India only) -  Powered by same power source as micro-controller; Input: DC 12V, 6 A (48 W) http://www.amazon.com/SeaLand-Sanipump-Discharge-Macerator-Whisper/dp/B000XBH2D4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
Igniter (all locations) - Powered by AA battery; DC 1.5V, 280-320 mA, Output: 10 kV; http://www.amazon.com/GrillPro-20620-Electric-Button-Igniter/dp/B000FJVKNM

mlp6, 2016-05-02:
@aforbis-stokes I'm going to close this, but I've started a file based on the above that needs to be more thoroughly completed.  We can/should probably make one of these for each location.

Closed 2016-05-02.

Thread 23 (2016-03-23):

cell text warning alert

mlp6, 2016-03-23:
when temperature > 65 C for > 30 min

aforbis-stokes, 2016-03-23:
Just noticed, should be <65C for >30 min

mlp6, 2016-03-28:
https://community.particle.io/t/webhooks-sending-a-text-message/10560

mlp6, 2016-03-28:
It looks like Twilio is one of the recommended services to achieve programmable SMS.  @aforbis-stokes do you want to sign up for an account to do this?  It appears to be free.  Another option would be to kick off an email to someone instead of a text message, which would not need this service.  Let me know.

aforbis-stokes, 2016-03-28:
@mlp6 I will setup a Twilio account. Let's go with SMS. Some of our field operators that will receive the alerts will not have smart phones.

aforbis-stokes, 2016-03-28:
Account created. Login is a.forbis.stokes@gmail.com; ADPL2016! (same as for Particle)

mlp6, 2016-04-17:
@suyashkumar is going to integrate this into his web server that will also be doing data collection

mlp6, 2016-04-17:
Condition for text msg alert: Probe 3, < 65 deg C for >30 min

mlp6, 2016-11-02:
@aforbis-stokes is this working correctly?

aforbis-stokes, 2016-11-08:
I am not getting these texts or emails currently. Each time Suyash does an update I will get the email warnings for a few days, but then they drop off. I'm not sure if it is related our problems of running the Particle properly, so I have not worried about it while we fix the igniter issues.

mlp6, 2016-11-09:
@suyashkumar any insight from your perspective?

aforbis-stokes, 2016-11-09:
@suyashkumar I have gotten the lab Particle rolling again. I've damaged a few while testing. The operational Particle is now ADPLDuke6191. You can clear all other "ADPLDuke...." from the web database. I'll keep this one going for you to have something to work with.

I do know that ADPLIndia2723 is operational, and I see the data on the Particle Console (though not at this moment), but the last data point I have on the website is October 18.

suyashkumar, 2016-11-29:
@mlp6 @aforbis-stokes sorry just saw this thread -- right now we have texting to get temp data on demand -- texting "temp <DEVICE_NAME>" to the phone number (which I'll put in our private message) will return the following:

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

suyashkumar, 2016-11-29:
I think proactive alerting is a good idea via email/sms. Some points of inquiry to determine how this alerting feature will shape up:

- Should we expect to have different sets of alert contacts by device or by region (or both)?
- Will we need a front-end component to add/remove phone numbers for alerting in different regions?
- Do we necessarily need local numbers in all these regions? Twilio doesn't provide local support for many regions at this time :/. Supported [texting regions (send and receive) ](https://support.twilio.com/hc/en-us/articles/223183068-Twilio-international-phone-number-availability-and-their-capabilities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)
- When we say "Condition for text msg alert: Probe 3, < 65 deg C for >30 min" which probe (HTR? HXHI?) is probe 3?
- What functionality should be added to silence noisy alerts and in what conditions do we anticipate noisy alerts (e.g. if a device is offline or reporting erratic data)

suyashkumar, 2016-12-02:
@aforbis-stokes Thoughts on the above?

aforbis-stokes, 2016-12-02:
@suyashkumar my bad...missed these.

1. There will be different sets of alert contact by region (not by both for now). I should be an email alert for all. I would set up the primary field operator for text alerts in each region, but we can hold off on putting that person in until we get some more consistency/reliability in the systems.
2. I'm not sure what you mean by "front-end" (sorry, new to this terminology). If all of the add/remove could be done by me, that would be sufficient. I'm regularly involved in communication with everyone working in the field.
3. Unfortunately, yes. I think we will need local numbers. Some of the local operators don't have reliable email/internet. And they won't be willing to take on international texting fees.
4. Probe 3 is HTR. (fyi old term:new term = Probe 1=HXCI, 2=HXCO, 3=HTR, 4=HXHI, 5=HXHO)
5. Device offline would be a condition with noisy alerts. Another condition would be similar to what we have in India right now. We have some operational problems that are unrelated to the controls, so the heater is not running and HTR <65 always. In that case, if I had a manual option for temporarily disabling alerts, that would be an easy solution.

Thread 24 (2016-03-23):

cloud data collection: temperature

mlp6, 2016-03-23:
record temperature on all of the thermistors and save to the cloud

mlp6, 2016-03-23:
good example: https://www.openhomeautomation.net/cloud-data-logger-particle-photon/

Closed 2016-04-01.

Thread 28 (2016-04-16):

voltage regulator powering Electon inadequate

mlp6, 2016-04-16:
provides max 0.15 A output; needs 2 A @ 5V

mlp6, 2016-04-17:
This is going to be fixed in the field with a diode-based regulator directly off the 12.6V battery to provide 11.6 V to the Electron.

Closed 2016-04-17.

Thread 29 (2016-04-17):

reduce cellular data usage

mlp6, 2016-04-17:
@aforbis-stokes estimated current data usage for 2.5 min publish events for 5 temperature probes to be ~13.2 MB/month, which will not be cheap.  Some ideas to reduce this data usage are to reduce the precision of data being published, maybe report stats over larger time intervals.

mlp6, 2016-04-17:
@aforbis-stokes looked into the data overhead associated with every publish event, which appears to be non-trivial, so we will accumulate data for every 1-2 hours and publish then.

suyashkumar, 2016-04-18:
This makes sense! Can I suggest we build the following JSON publish string:
"[
    {10:<temp>, 11:<temp>, ...,time:<UTC time>},
    {10:<temp>, 11:<temp>, ..., time:<UTC time>}
]"
Note that we can save 300 bytes off the bat by still publishing every 2.5 minutes (which is a nice "heartbeat" to have) by incorporating the 4 thermistors' data into one publish string like
"{10:<temp>, 11:<temp>, ...}" . We can leave out the outer braces to save 2 bytes a message too (I can deal with that on server-side).

mlp6, 2016-04-18:
Sounds like a great plan to me.

mlp6, 2016-04-18:
https://docs.particle.io/guide/getting-started/data/electron/

suyashkumar, 2016-04-19:
Note the additional 318 bytes an hour that are being spent keeping the cell connection alive. I don't think we should be opening and closing the cell connection anymore though, cause we lose on demand access and control ability, but figured this would be good to note

suyashkumar, 2016-05-18:
@mlp6, @aforbis-stokes:
Just bumping this thread over here. To save data and prevent us from worrying about publish rate limits, are we still interested in publishing all temps at once with, say a TEMP event with the following payload:
"
{
    "HTR":  [Number],
    "HXCI": [Number],
    ...
}
"
I think that makes sense since doing separate publishes for each temp causes us an extra 300 bytes a publish every time and (if I understand correctly) there's no reason we'd only want to publish one temp and not others?
Would be happy to impl this on both the firmware and the server side if people are busy.

mlp6, 2016-05-22:
There are still some sub-par syntax in play for parsing the TEMPS event... the JSON is malformed, so I cannot just use ``JSON.parse()`` to build a dictionary from these data that I can just loop over.  I need to fix that.

mlp6, 2016-05-22:
Actually, in thinking about it a tad more, publishing a true JSON string is going to require even more characters to transmit, so I will leave it as is (for now).

Closed 2016-05-22.

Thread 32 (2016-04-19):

Ignore Negative Probe Values

suyashkumar, 2016-04-19:
Ignore negative values when plotting (in front end). @aforbis-stokes

mlp6, 2016-04-19:
Maybe instead of ignoring them, they can (should?) be indicated on the plot (like a red X on the x-axis at that time point) in case that would be useful for @aforbis-stokes would like to know when it has been disconnected / damaged.

aforbis-stokes, 2016-04-19:
@mlp6 I like that idea.

suyashkumar, 2016-04-19:
Agreed--if this is where we want to see that sort of outage data that makes a lot of sense!

On Apr 19, 2016, at 10:00 AM, aforbis-stokes <notifications@github.com<mailto:notifications@github.com>> wrote:

@mlp6<https://github.com/mlp6> I like that idea.

-
You are receiving this because you authored the thread.
Reply to this email directly or view it on GitHub<https://github.com/mlp6/ADPL/issues/32#issuecomment-211932856>

suyashkumar, 2016-04-23:
Sup y'all--I think let's talk in person about how to handle these (disconnects vs. bad values). Would something like an error log make sense?

Closed 2016-04-27.

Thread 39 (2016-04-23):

Other Dashboard Data

suyashkumar, 2016-04-23:
What other "at-a-glance" type of data would be good to show in the dashboard? Maybe the avg temps over the last hour for each probe?

@aforbis-stokes
@mlp6

aforbis-stokes, 2016-04-24:
The average temp is a good idea. Another is if the Valve is on

suyashkumar, 2016-04-24:
Sweet, should we publish valve status along with our other temp data packages? We can likely also expose this using spark.Variable()

mlp6, 2016-05-19:
Need to add some sort of plot for the bucket tip (count and timestamps of tip); maybe in a separate plot next to the temp plot.

aforbis-stokes, 2016-05-19:
How about a second y-axis for bucket tip? Could be on the right, and would not require much labeling so shouldn't make things look too cluttered.
We have 3 buckets, and each has a slightly different volume/tip, so I don't think incorporating that into the code works very well. But, if we converted for the web display, it would be more relevant for whoever is looking. Each tip =325 mL of waste, so the y-axis could be 0 to 325 mL.
Flow affects the temperature, so having the tips matched up on the same time axis as temperature would be interesting to see.

mlp6, 2018-05-21:
This has been integrated into current functionality, so going to close for now.

Closed 2018-05-21.

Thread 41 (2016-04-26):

Get Valve Status on Demand

suyashkumar, 2016-04-26:
Get valve status on demand. Should we also publish this along with the other data periodically? @aforbis-stokes

mlp6, 2016-05-02:
@aforbis-stokes can you comment on if this is desired?

aforbis-stokes, 2016-05-02:
Sorry I missed this one. Yes, being able to check if the valve is open would be a good feature.

mlp6, 2016-05-02:
and just to confirm, do you want this to be regularly reported back to the web server, or just make it accessible for on-demand query?

aforbis-stokes, 2016-05-02:
I don't think it would look good on the graph, but I think if it were in the dashboard, it would be valuable information.

mlp6, 2016-05-19:
We can/should add a "status light" on the dashboard; maybe a green circle for open, and red circle for closed?

suyashkumar, 2016-05-19:
Indeed, this is easy enough! do we have a Spark.variable() registered for valve status? Can someone point me to that declaration?

mlp6, 2016-05-19:
The Valve class has a public ``gasOn`` boolean variable that could be easily published.

suyashkumar, 2016-05-19:
Perfect. I'll get this on demand, as that's what we want right? Or do we want to keep track of this information longitudinally (in which case can publish and make it avail on demand).

mlp6, 2016-05-19:
I think it would just be an instantaneous check...

suyashkumar, 2016-05-19:
Closed by 27107a1

mlp6, 2016-05-19:
Looks like the web server might be crashing on a timeout error:

```
GET /api/gasOn/ADPLdukelab4601 304 1838.981 ms - -
GET /api/list/kenya-1 304 1283.297 ms - -
GET /api/gasOn/kenya-1 - - ms - -
{
  "error": "Timed out."
}
_http_outgoing.js:344
    throw new Error('Can\'t set headers after they are sent.');
    ^

Error: Can't set headers after they are sent.
    at ServerResponse.OutgoingMessage.setHeader (_http_outgoing.js:344:11)
    at ServerResponse.header (/home/bitnami/ADPL/software/logging/node_modules/express/lib/response.js:718:10)
    at ServerResponse.json (/home/bitnami/ADPL/software/logging/node_modules/express/lib/response.js:246:10)
    at Request._callback (/home/bitnami/ADPL/software/logging/api/ondemand.js:14:8)
    at Request.self.callback (/home/bitnami/ADPL/software/logging/node_modules/request/request.js:200:22)
    at emitTwo (events.js:87:13)
    at Request.emit (events.js:172:7)
    at Request.<anonymous> (/home/bitnami/ADPL/software/logging/node_modules/request/request.js:1067:10)
    at emitOne (events.js:82:20)
    at Request.emit (events.js:169:7)
    at IncomingMessage.<anonymous> (/home/bitnami/ADPL/software/logging/node_modules/request/request.js:988:12)
    at emitNone (events.js:72:20)
    at IncomingMessage.emit (events.js:166:7)
    at endReadableNT (_stream_readable.js:913:12)
    at nextTickCallbackWith2Args (node.js:442:9)
    at process._tickCallback (node.js:356:17)
```

suyashkumar, 2016-05-19:
Be should be good now, will push a new update

Closed 2016-05-19.

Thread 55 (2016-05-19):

Push Updates for Front End

suyashkumar, 2016-05-19:
Push updates using socketio of the data displayed in the front end as updates to data arrive (e.g. other bucket tips and new temp data)

mlp6, 2016-05-20:
I was just thinking about this being a great feature... right now I'm reverting to reloading the entire page and selecting the correct device, etc.  FYI, 3 devices are online now (2 in Kenya for testing)

suyashkumar, 2016-05-21:
Just implemented this. However, this will be the most stable when we receive all data on the server at once. Right now it triggers an auto refresh once the server and frontend see that an `HXHO` packet is recieved (which is usually at the end of the series).

Closed 2016-05-21.

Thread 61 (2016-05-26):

time loop()

mlp6, 2016-05-26:
need to determine how fast loop() is executing (when not publishing)

mlp6, 2016-11-09:
@oo22 do you think you could benchmark ``loop()`` execution time?

mlp6, 2016-11-14:
On first benchmark, it is taking ~5.25 s to complete each loop, which is **way** longer than I expected.

There are two courses of action:
1. Identify the bottleneck and reduce that.
2. Make the bucket tip come in via an interrupt event.

I am leaning towards option 2.

mlp6, 2016-11-15:
The bottleneck is the thermistor reads, which take 1 s each, and there are 5 of them serially, which take 5 s of each loop.

I am leaning toward implementing solution that get at both options 1 and 2 above:
1. Rotate between each of the 5 thermocouples with each loop, so that the loop execution time is closer to 1.25 s, but each thermocouple updates only once every ~5 s (not really an issue)
2. Associate the bucket tip with an interrupt event.

@aforbis-stokes is there any problem with changing the input pin for the bucket tip counting?  Not all pins support interrupts.

aforbis-stokes, 2016-11-15:
@mlp6 I see no problem with these steps; I will try out the bucket this morning. Changing the input pin is no problem.

Closed 2016-11-15.

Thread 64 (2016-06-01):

Push Notifications Broken

suyashkumar, 2016-06-01:
Push update isn't working

suyashkumar, 2016-06-01:
It's because socketio is pointing to localhost:9000 even on the server. I'll change this to pull from an environment variable

suyashkumar, 2016-06-01:
Server side error, because data.name is undefined

suyashkumar, 2016-06-01:
Closed by changing data.name --> data.coreid (there was a change at some point)

suyashkumar, 2016-06-01:
Whoops it's data.probeid

mlp6, 2016-06-01:
I think this broken when I switched to a single temp publish event (which appears to be working!).  Javascript and I are still not on the friendliest of terms, but we're making it work.

Closed 2016-06-01.

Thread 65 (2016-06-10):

Bucket Tip Infrastructure

suyashkumar, 2016-06-10:
With the addition of bucket tip publishes, new API routes need to built along with the bucket tip dashboard item (number of bucket tips in the last 24hrs).
@aforbis-stokes: What sort of information about the bucket tips is usually needed? The number in the last 24 hours, the last global count to date, and perhaps a historical record of when all bucket tips have happened? Just curious!

aforbis-stokes, 2016-06-13:
@suyashkumar sorry for delay, was home visiting family. The number in last 24 hours would be good for dashboard. A record of tips with time of tip is important for us to evaluate operation. Plotting tips with time would be a nice feature and could possibly be overlayed with temperature.

suyashkumar, 2016-11-30:
@a.forbis.stokes

aforbis-stokes, 2016-11-30:
On Particle Console: Each 2.5 data reporting I receive a cumulative number of tips from the start of the Particle turning on. @mlp6 have talked a bit on how to handle as that number will max out at some point.
The way that I worked the tipping bucket & counter separate from the Particle was to report a total number of tips for one day (~100 tips/day). Knowing the time of tips is very helpful because from that I can get a flow profile for the day.
Moving forward: Resetting tip count at midnight each day would help data handling. The current method of reporting cumulative tips is probably ok. I can at least track tips w/in a 2.5 min window over the 24 hr period, which is pretty good. On the web page meta-data, number of tips that day is a good indicator. And that count just be an updated value directly from the Particle data reporting. Putting tips on the graph would be great but a little trickier. I'll see if I can think of simple way that gets the idea across well.

aforbis-stokes, 2016-11-30:
Thoughts on working with tipping bucket on web server displays. I used the Kenya csv to get the temp data and made up tip data.
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

suyashkumar, 2016-12-02:
@aforbis-stokes sweet thanks! Couple thoughts:

Storing bucket tip events along with a time stamp will be very easy to do (and I can do cumulative counts on my own given the timestamps, in addition to holding onto the actual count the device sends).

Would the cumulative tip count reset every day in the graph you propose?

It seems to me it __might__ make sense to create a separate view (perhaps tabbed?) to display more in depth bucket tip data. What features are important to you in a flow profile (particularly in an at-a-glance profile)? Does a histogram (hour bins?) of bucket counts in a given day (maybe togglable to over multiple days) make sense? Are we perhaps interested in seeing how a given day's profile might deviate from the typical average or expected profile? Are we trying to draw comparisons between profiles sites/units?

Not sure how much of this type of analysis should be done in post processing vs what would be helpful in an at-a-glance live view.

@mlp6: as we start to grow the complexity and feature set here I'm drawn back to the idea of overhauling at least the front end to react to enable scalable growth using what I think is a more understandable and modular paradigm compared to angular...

aforbis-stokes, 2016-12-02:
@suyashkumar that sounds good to me!

Yes, I would have the cumulative tip count reset each day (in meta-data and raw data on csv).
@mlp6 would that be done on the Particle's software?

Re: the figure, what I was meaning to put across was cumulative tip count is great for the meta-data, and I assume that cumulative tips with time on the figure would be the easiest to implement. That figure (top in my example) would have value, but the more valuable figure is the second in the example that shows individual tips w/ time stamps to give a view of what the flow pattern looks like. I figured it would take a couple extra steps to generate. If that is simple, then that is what I would recommend.

At a glance, what I would find most useful is a flow pattern. The details of the flow pattern are less important the image of seeing how intensity of flow impacts temperature. I can get all of the details in post-processing.

This picture below is our anticipated flow pattern. An output figure similar to this is what I want in the end, which is ok if it's through post-processing.

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

suyashkumar, 2016-12-28:
@aforbis-stokes
We now have bucket tips being recorded in the database (since #125) but the initial results show that the number being reported is not changing over the course of at least this past day ( check out http://adpl.suyash.io/api/bucket/list/ADPLKenyaN3763 ). You mentioned that time of tip is very important -- we shall get that within 2.5 mins as it seems the current firmware setup is to publish a `BUCKET` event __every time__ we publish a `TEMP` event.

@mlp6, @aforbis-stokes I think it might only make sense to do the BUCKET publish if the value has actually changed since the last publish (assuming that we know the publish happened successfully, which it seems is the case). This will save us data in the database and more importantly will save us cellular data (no need to send redundant data) :)

aforbis-stokes, 2016-12-29:
No tips are coming through right now because I have taken the timerblox one-shot out while we test the valve/igniter in the field (that piece is the first to get damaged if something goes wrong).

For the most part the gas valve will open when there is flow (bucket tip), but that may not always be the case.

suyashkumar, 2017-01-01:
@aforbis-stokes ah, that makes a lot of sense--those timer chips can be pretty sensitive.

What're your thoughts on doing the bucket-tip publish when the event happens as opposed to every 2.5 mins?

aforbis-stokes, 2017-01-03:
@suyashkumar I think the publish on the event is more useful for data analysis; however, I don't know how that affects the current software logic approach to collecting the bucket tip information. @mlp6 thoughts?

Also, I'm not sure of what the +/- is on data transmission. For example, I expect 200-400 tips / day. If we publish only events, that's 200-400 transmissions / day. When we publish tips every 2.5 mins, that is 576 transmissions / day. Seems like another benefit, but I may be missing something there/have flawed logic.

mlp6, 2017-01-04:
What about if we publish a summary of the past 2.5 min only if there have been tips during that period.  We can store that information locally and then transmit something like the elapsed time since the last tip for each one.  That would limit the cell data, and put more of the heavy lifting on the packaging and parsing of data (which is totally fine).

mlp6, 2017-01-04:
@aforbis-stokes what sort of precision do you need on the recorded time for each tip event?

aforbis-stokes, 2017-01-04:
The current precision of tips / 2.5 min is acceptable...so I'm not totally pushing to make a change. If we do make a change, down to the minute is good. Any further is not necessary.

mlp6, 2017-01-04:
Oh, that would make life easier - so just a number of tips since the last publish event would work?

aforbis-stokes, 2017-01-04:
Correct

suyashkumar, 2017-01-08:
@mlp6, @aforbis-stokes do we expect there to be multiple bucket tip events within a 2.5 minute window? If not, then your suggested approach would be similar to just publishing bucket tips events as soon as they happen--which gives us better time resolution for the same amount of data spent--unless I'm missing something? (though, I do realize we don't really need the better resolution, just curious)

Either approach is fine by me as it significantly cuts down on the number of repeat bucket tip transmissions that we currently have, but am slightly partial to just publishing the current bucket tip count when the increment occurs (if we don't have multiple tip events in a 2.5 min window).

mlp6, 2017-01-08:
I think there can be...

suyashkumar, 2017-01-08:
Cool! I can go ahead and get the relevant changes started, then. It may then also make sense to roll the bucket tips into the single `TEMPS` publish then to avoid the overhead of two publishes at the 2.5 minute mark...however, that'll require some significant changes to the server and also probably merits a refactor of the event naming so that's an optimization I'll create an issue for to be addressed in the future if we actually feel like shaving off even more data!

mlp6, 2017-01-08:
Sounds good!

suyashkumar, 2017-01-08:
Fantastic, will likely get to that this evening! :)

aforbis-stokes, 2017-01-09:
I'm a little late to this discussion, but it seems you are already moving in the right direction. Yes, I do expect there will be occasions where there are multiple tips in the 2.5 minute window.

suyashkumar, 2017-01-16:
@aforbis-stokes @mlp6 Another thing I remembered--if we are not sending bucket tip publishes when they occur and wish to maintain a global count on the device, it may prove burdensome to develop an efficient way to get the data you need on the server. Particularly if resets can occur in between. Have we considered storing bucket tip count in EEPROM if we really want to maintain a global count?

Or, instead of keeping a global count on the device, it'll be more useful on the server end (and save complications on the electron) for the electron to simply send the change in number of bucket since the last publish. I'll store this as a time series on the server in which form it'll be easy to query and ask the questions that Aaron alluded to before in this thread.

mlp6, 2017-01-16:
I was hoping to have the server store all "global" count-type information for those reasons.  The one things to deal w/ is when the Particle goes offline for a while b/c of poor cell connectivity, and dealing w/ data that way... and if that is an extended time, then write data to EEPROM to survive a power blip.  These are on the radar for @DanielHull to address once he gets some of the hardware updates made.

suyashkumar, 2017-01-16:
@mlp6 Awesome. Ultimately the best format for the server to hold data would be in a time series which serves well for plotting across various time bins. Calculating and storing such a time series would be easiest if the device does the following (from least burdensome to most):

1. Send a publish when a bucket tip occurs, for each bucket tip (200-400 transmissions/day)
2. Send the number of bucket tips since the last time reported at 2.5 min intervals (less transmissions if we have multiple bucket tips per 2.5 min interval, doesn't require any sort of global count on the device)
3.  The current solution of sending a global bucket tip count every 2.5 mins. It's hard to maintain resiliency on the device and it's not elegant to extract the data needed on the server.

I think 2 is likely the best option, so that we we don't have to worry about EEPROM and are resilient to bucket tip data within a 2.5 min window...

suyashkumar, 2017-01-16:
Ah, I missed the part about the poor cell connectivity. In that case I still think number 2 is the way to go, we'd just publish the change in bucket tip count since the last _successful_ published. :)

mlp6, 2018-05-21:
@suyashkumar is this still "open"?

mlp6, 2018-05-21:
I think this is "done" for now, so going to close.

Closed 2018-05-21.

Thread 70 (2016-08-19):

reduce dependence on cell connection during device boot

mlp6, 2016-08-19:
cell connectivity appears to be an issue at some/all sites... might need to consider using `SYSTEM_THREAD(ENABLED)` (https://docs.particle.io/reference/firmware/electron/#system-thread) to create parallel application and system threads.  a larger concern is what happens to publish events in this setup, both in terms of:
1. offline (temporary) data storage
2. `loop()` execution

mlp6, 2016-08-19:
@aforbis-stokes do you know how long a unit might remain on but offline?  asking from the perspective of how much data might need to be stored temporarily offline before it would get pushed when it does connect and how the data may persist if the unit loses power before it pushes the data.

aforbis-stokes, 2016-08-20:
Hard to tell how long is it on/off. I have it plugged in while working all day, and it seems to off more than on when I periodically check. I would say off for at least 1-2 hours at a time.

I did find a cell signal booster in town today. I will try to install tomorrow to see what that does. I feel pretty optimistic.

mlp6, 2016-08-20:
Okay... that isn't horrible.  And by "off", you mean lost cell connectivity, not turning off, correct?  I have software changes made, but I am a bit hesitant to push this change w/o testing a bit more.  I also want to see if there is newer system firmware that we can push to make it more cell robust.

aforbis-stokes, 2016-08-20:
Yes, I meant "off" for cell connectivity.

All of that sounds good. I am trying to go through a few troubleshooting steps from Particle tech support, but having issues getting Particle CLI to connect to the device over USB...

Closed 2016-11-08.

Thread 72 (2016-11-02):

add bypass capacitors

mlp6, 2016-11-02:
@aforbis-stokes and I discussed some improvements to make to the design, and adding bypass caps would be a good idea at all of the voltage points that need to be stable, especially into any ICs

mlp6, 2018-01-15:
This is a legacy hardware issue that no longer appears to be a problem with what has been implemented and deployed.  Going to close this out.

Closed 2018-01-15.

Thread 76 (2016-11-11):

``millis()`` time rollover

mlp6, 2016-11-11:
@aforbis-stokes do your devices in the field ever stay on for more than 49 days straight?  If so, then we need to take into account that the time variable that we are storing will rollover since we'll exceed the size of the data type ``millis()`` returns.

aforbis-stokes, 2016-11-11:
@mlp6 they should stay on for more than 49 days straight if there is no failure or disconnection. If all was perfect (at least in current design), the Particle would never turn off or disconnect. We just have not been successful preventing those failures for that long.
.

mlp6, 2016-11-12:
okay, then we definitely need to actively account for a time rollover.

the issue is that a time is recorded as an ``unsigned long int``, which means that the max value it can hold is ``2**32 = 4294967296`` ms, or ~49.7 days of elapsed time before running out of bit depth.

I think the best solution would be to keep track of elapsed time using a ``float (32 bit)`` in seconds, which would give us a lot more leeway in accumulated time, and still maintain the precision that we need, all in a convenient unit.

mlp6, 2017-01-29:
I think that if we are streaming the data as diffs back to the web server, then we don't need to worry about this as much w/r to accumulated counts, etc..  Just need to check that none of our calculations will break if the reported time reset.

Closed 2018-05-23.

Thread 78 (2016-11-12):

missing bucket tip events

mlp6, 2016-11-12:
@aforbis-stokes has reported that the bucket tip count isn't working, specifically tip events are missing, but without any rhyme or reason that he has noticed.  This could be an issue on the hardware and/or software side.

I can tackle the software side, but some hardware debugging that should be done:
1. Capture the output of the one-shot on tip events with the o-scope, and save that trace in the repo.  Try to reproduce the missed events, and see if there is a correlation b/w unexpected one-shot output and the missed events.
2. From the o-scope output, characterize the actual voltage and duration of the pulse.  We currently have a 2.5 s lockout time before re-measuring the bucket pin (``C4``).  Determine if this is appropriate.

mlp6, 2016-11-14:
Aaron's mentions that 2-3 in a row can missed, sometimes including the first tip.  I am wondering if this might have to do with forced delays in the code for back-to-back event publishing, etc.  Will benchmark the loop timing to see how long the loop is delayed during publish events, etc.

Closed 2016-11-15.

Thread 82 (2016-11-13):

upgrade firmware to v0.6.0

mlp6, 2016-11-13:
necessary to:
1. implement ``Logging`` class
2. fix some bugs that could rear their head and affect us (though haven't to date)

aforbis-stokes, 2016-11-23:
How is the firmware updated remotely? The Particle docs make it sound like the device needs to be switched to DFU mode first. Is there a command window call, like "particle flash [device] firmware0.6.0" ? Or can it be changed using Particle Build (using the drop-down menu showing version)?

mlp6, 2016-11-23:
We can do it from the CLI using the example syntax you showed.  Typically we have to download two files since the firmware is too large to flash in one step.  I have flashed several of the device firmwares before, but it is a bit of a "fingers crossed" moment.

mlp6, 2016-11-23:
I usually test run on a local Duke unit first to stress test it a bit before deploying remotely.

aforbis-stokes, 2016-11-23:
Ok. The Duke version ADPLDuke0785 version is plugged in now. Kenya devices ADPL_KE_north and ADPLKenyaCentral9822 should both be powered on at Patrick's (field guy) home. He is away from home for another hour or so.

aforbis-stokes, 2016-11-23:
Patrick now home and can reset if needed. He has two fresh Electrons set up (found older Electrons were damaged). The Electrons needing the firmware upgrade and software flash are "ADPL_KE_north" and "ADPL_KE_central" (forget about ADPLKenyaCentral9822)

Closed 2017-08-25.

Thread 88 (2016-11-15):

mothball the level sensor?

mlp6, 2016-11-15:
is this true?  if so, then what modulates the pump activity?

aforbis-stokes, 2016-11-15:
Correct. We kept having hardware issues with the level sensor and redesign the collection tank to have a manual overflow so that the sensor was no longer necessary. The pump purely runs on the timer.

mlp6, 2016-11-15:
And that pump timer is independent of the MCU, correct?  i.e., can I disable all calls to running the pump in the code?

aforbis-stokes, 2016-11-15:
The timer does run off of the MCU. I forgot how (sorry, I should have logged this), but I have the program running with the code still telling the pump to turn on and off. It may be that when the sensor is not connected, the reading becomes such that the program thinks the level is in the intermediary region that causes the pump to run on the timer. I can see this in the lab unit as the pump pin is on D7, the LED pin, and it turns on and off according to the program's timer

So, this code section still applies:
currentTime = millis();
        if (!pump.pumping && (currentTime - pump.offTime) > KEEP_PUMP_OFF_TIME) {
            pump.turnOn();
        }
        else if (pump.pumping) {
            if ((currentTime - pump.onTime) > KEEP_PUMP_ON_TIME) {
                pump.turnOff();

mlp6, 2016-11-15:
Got it; I'll clean up the code to remove the level sensor hooks, but I'll preserve all of the pump timing.

mlp6, 2016-12-08:
Commit f2ecb62e23ee7d3b5b6d6d1da318f84880684cc1 removed the level pin map, but there is dependent code that still exists, so master will no longer compile.  Need to fix this ASAP.

Closed 2016-12-08.

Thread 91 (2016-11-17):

web server not reporting online data

mlp6, 2016-11-17:

mlp6, 2016-11-20:
Web server was down; inspecting the screen session had this error message:
```
New Message
/home/bitnami/ADPL/software/logging/handle-device.js:26
                        realData.temp = realData.data.split(",")[d].split(":")[1].replace(/\s+/g, '');
                                                                                 ^

TypeError: Cannot read property 'replace' of undefined
    at EventSource.<anonymous> (/home/bitnami/ADPL/software/logging/handle-device.js:26:61)
    at emitOne (events.js:77:13)
    at EventSource.emit (events.js:169:7)
    at _emit (/home/bitnami/ADPL/software/logging/node_modules/eventsource/lib/eventsource.js:181:17)
    at parseEventStreamLine (/home/bitnami/ADPL/software/logging/node_modules/eventsource/lib/eventsource.js:196:9)
    at IncomingMessage.<anonymous> (/home/bitnami/ADPL/software/logging/node_modules/eventsource/lib/eventsource.js:159:11)
    at emitOne (events.js:77:13)
    at IncomingMessage.emit (events.js:169:7)
    at readableAddChunk (_stream_readable.js:153:18)
    at IncomingMessage.Readable.push (_stream_readable.js:111:10)
    at HTTPParser.parserOnBody (_http_common.js:127:22)
    at TLSSocket.socketOnData (_http_client.js:322:20)
    at emitOne (events.js:77:13)
    at TLSSocket.emit (events.js:169:7)
    at readableAddChunk (_stream_readable.js:153:18)
    at TLSSocket.Readable.push (_stream_readable.js:111:10)
```
Manually-restarted the web server... will keep an eye on this.

suyashkumar, 2016-11-21:
hmmm it seems that `realData.data.split(",")[d].split(":")[1]` is undefined. It seems you (or perhaps me?) added a comment about how we're parsing non-traditional JSON here--we should probably only do that for messages we're sure have the formatting we expect. Other messages (like system messages) may be published on this stream. I'll add in some safety/error handling logic here to catch and describe these errors better :)

suyashkumar, 2016-11-21:
I will say, however, that this is likely unrelated to the "not reporting online data" problem, as in that case the server was still running but not receiving or acting upon new messages on the particle stream.

suyashkumar, 2016-11-21:
Also it seems that all these messages are "TEMPS" messages so we shouldn't have to gate further. I will add more safety logic in here though.

mlp6, 2016-11-22:
Another error associated with the server going offline:
```
{ [Error: socket hang up] code: 'ECONNRESET' }
undefined
undefined:1
undefined
^

SyntaxError: Unexpected token u
    at Object.parse (native)
    at Request._callback (/home/bitnami/ADPL/software/logging/api/ondemand.js:16:22)
    at self.callback (/home/bitnami/ADPL/software/logging/node_modules/request/request.js:186:22)
    at emitOne (events.js:77:13)
    at Request.emit (events.js:169:7)
    at Request.onRequestError (/home/bitnami/ADPL/software/logging/node_modules/request/request.js:845:8)
    at emitOne (events.js:77:13)
    at ClientRequest.emit (events.js:169:7)
    at TLSSocket.socketOnEnd (_http_client.js:305:9)
    at emitNone (events.js:72:20)
    at TLSSocket.emit (events.js:166:7)
    at endReadableNT (_stream_readable.js:923:12)
    at nextTickCallbackWith2Args (node.js:458:9)
    at process._tickCallback (node.js:372:17)
```

suyashkumar, 2016-11-29:
It seems that this socket reset is probably an express/routing issue (someone fired off a request and then closed it before we could write a response). I added in some express middleware error handling in 518064e44b51ba68433402645e38d0dd0de16278 to address this and prevent the server from crashing in such circumstances.

suyashkumar, 2016-11-29:
Further investigation is probably still warranted into some of the root causes of the issues we see here if they crop up again. Again i think there are several different issues here, but some of these could be one off (I've noticed that we are getting a lot of bot spam on various routes as well looking through the code).

suyashkumar, 2016-12-09:
Two errors this time. The first seems like a DNS issue that should get resolved on retry. The second one is an error in parsing JSON from a call to particle's api to get real time valve status. I'll add in logic to catch this better!
```
{ Error: getaddrinfo ENOTFOUND api.particle.io api.particle.io:443
    at errnoException (dns.js:28:10)
    at GetAddrInfoReqWrap.onlookup [as oncomplete] (dns.js:76:26)
  code: 'ENOTFOUND',
  errno: 'ENOTFOUND',
  syscall: 'getaddrinfo',
  hostname: 'api.particle.io',
  host: 'api.particle.io',
  port: 443 }
undefined
undefined:1
undefined
^

SyntaxError: Unexpected token u in JSON at position 0
    at Object.parse (native)
    at Request._callback (/home/bitnami/ADPL/software/logging/api/ondemand.js:16:22)
    at self.callback (/home/bitnami/ADPL/software/logging/node_modules/request/request.js:186:22)
    at emitOne (events.js:96:13)
    at Request.emit (events.js:188:7)
    at Request.onRequestError (/home/bitnami/ADPL/software/logging/node_modules/request/request.js:845:8)
    at emitOne (events.js:96:13)
    at ClientRequest.emit (events.js:188:7)
    at TLSSocket.socketErrorListener (_http_client.js:310:9)
    at emitOne (events.js:96:13)
    at TLSSocket.emit (events.js:188:7)
    at connectErrorNT (net.js:1020:8)
    at _combinedTickCallback (internal/process/next_tick.js:74:11)
    at process._tickCallback (internal/process/next_tick.js:98:9)
```

Closed 2018-05-21.

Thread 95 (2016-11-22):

Absolute power usage

oo22, 2016-11-22:
Quantifying absolute power usage by the device during a 24 hour period

oo22, 2016-11-22:
Did you have any ideas of how you wanted to approach this?

oo22, 2016-11-22:
http://www.ti.com/lit/wp/slay023/slay023.pdf
very helpful in calculating the system's use of power.

aforbis-stokes, 2016-11-22:
I installed a 2Ohm resistor on the anode side of power supply line. I am using a Vernier Instruments differential voltage meter and data logger to measure voltage drop across the resistor. Knowing power supply voltage and resistance, I can calculate current and then power.

oo22, 2016-11-23:
What is the data logger?
(1) I think the power usage may not be consistent the entire time because the power usage will vary based on the tasks that the MCU is doing (taking in data, resting etc) at different times. To not make it too complicated, from my understanding, we can generalize and say that there are two main events ( for example 1 event when the MCU is not turning on the ignitor and 1 event when the MCU is turning on the ignitor). Each of those events will take a certain amount of time and you can measure the voltage during those events.
(2)  I would suggest using an oscilloscope so that you can record the voltage waveform during an event. And then calculate the average value of the voltage waveform (Vrms). P = V^2/R
(3)  We may not get a perfect waveform which we can use to calculate the average voltage during an event. We just have to test and see.

These are my thoughts.

mlp6, 2016-11-23:
I think that for getting an average usage over a long period of time, then Aaron's approach should work well, especially if you trigger action events along the way that contribute to total power consumption.

If you care about transient power draw, then I would look into Siji's approach for a discrete device connected to the entire system.

Closed 2016-11-28.

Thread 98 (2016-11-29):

PCB Board Design

oo22, 2016-11-29:
@a.forbis.stokes : how big do you want the PCB board to be?  i was thinking about just getting the relays on another board just keep the grounds physically separate . Is that ok?

aforbis-stokes, 2016-11-30:
The board can be whatever size is necessary. My hope for the custom board is a more clean, organized layout. I would assume that would reduce the total footprint of my existing circuit board + relay board. As long as the new board does not increase the overall size, I am ok.

oo22, 2016-11-30:
would you like the headers that you used for the relay board on the circuit board or just regular headers?

oo22, 2016-11-30:
do you want a separate circuit board for the ignitor button circuit?

aforbis-stokes, 2016-11-30:
No, I'll continue to mount the momentary push-button on the enclosure box containing the igniter. I'll use the twist-cap connectors to connect the wires.

oo22, 2016-11-30:
ok. where is the TVS diode going to be then?

aforbis-stokes, 2016-11-30:
I will connect that with the twist-caps as well. I think a custom board just to solder a few wires & TVS together would be overkill. If it is quick and super cheap to make one for that, it wouldn't hurt, but I don't see a good reason to spend >$10 on a board for that purpose.

mlp6, 2016-11-30:
You can do those small, one-off boards just as soldered perf-board, not an etched PCB.

mlp6, 2016-11-30:
I haven't seen any commits w/ the actual control board PCB; are those coming?

oo22, 2016-11-30:
yes it is. I'm making some components PCB editor.

mlp6, 2016-11-30:
also, @oo22 you committed a new version of a file I had deleted b/c it was outdated

`ADPL.SchDoc` was deleted; `ADPL Wiring Diagram.SchDoc` was the latest one.  why was the old one ressurected?

oo22, 2016-11-30:
mhmm My latest one I have is called ADPL.SchDoc. ADPL wiring Diagram is the old one

oo22, 2016-11-30:
ADPL wiring diagram and ADPL_Board should be deleted because they are old

oo22, 2016-11-30:
going to clean that up right now cause the file that I was just working got deleted cause I was opening too many files with the same name.

oo22, 2016-11-30:
@aforbis-stokes some of the boards will have 3 headers for the relays to connect to the three different relays (ignitor, pump, valve) and some will only have 2 headers to connect to 2 different relays (ignitor and pump), correct? I just want to double check

aforbis-stokes, 2016-12-01:
Mostly correct. One board has 3 relays (ignitor, pump, valve)  and other has 2 (ignitor and Valve). For reference, though, the two relay version is for the majority of systems and likely all future systems. The project in India is the only one with the pump, and it is a special case scenario that likely will not be repeated. I would focus on the 2 relay version and then make it so that adding an additional relay would not be difficult for this (or any other) special case.

Closed 2017-01-29.

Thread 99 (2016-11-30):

Update schematic with new relays

oo22, 2016-11-30:
the schematics in the repository include the schematic representation of the old relays that we were using. Need to update the schematic with the schematic representation of the new relays that we are using.

mlp6, 2017-01-29:
@DanielHull can you check that these relays are correct, and if so, close this out?

aforbis-stokes, 2017-01-30:
The most recent commit I made "ADPL_improved" has a few changes from the last schematic other than just relay. By-pass capacitors for relays were put into a different location (on + side of relay), and protection diodes were put onto each input sensor. Also, the old igniter was replaced by the new igniter that does not spark and uses 12V and 2A (peak of 7A). @DanielHull looking over the recent diagram with the comments from the Greg Mimmack report in mind would be helpful.
But, but back the relay conversation. I checked the relay part number on the diagram, and I forgot to update it to 817-FTR-F1CL012R (specified up to 8A as needed for relay). These are the relays we wanted to switch to because of the high dielectric and surge strength that could protect against igniter shorts. However, changing the igniter resolves this problem (spark igniter = 10kV; surface igniter = 12V), and the old relays may be fine (https://www.amazon.com/gp/product/B00PFA83RW/ref=oh_aui_search_detailpage?ie=UTF8&psc=1).
I'm open to either version. If we wanted the relays on a custom board, the FTR makes sense. If we want to keep the relays on a separate board from the controller, the Amazon board may be easiest. Thoughts?

DanielHull, 2017-02-10:
@aforbis-stokes the review also mentioned the carrying capacity of the lines as a concern. Not sure if that was something before the ones on Amazon, but the ones listed above carry 10A. Do you where the data sheet for that is? Couldn't identify it on Amazon or online...

aforbis-stokes, 2017-02-10:
This is the best I've found (relay only, does not include board)
https://www.ghielectronics.com/downloads/man/20084141716341001RelayX1.pdf

DanielHull, 2017-02-10:
There are a lot of similarities (similar coil rating, voltage range, and carrying current). Of note is that one is a DPDT (FTR-F1CL012R) the other two SPDT. The Fujitsu relay is much smaller overall. The only question is control. I'd have to look in more if one signal causes both to switch, (whether we even want that...) or whether there is independent control of both poles.

Closed 2017-02-11.

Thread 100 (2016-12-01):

add control for compression valve

mlp6, 2016-12-01:
there is existing Arduino code that we can eventually roll in

mlp6, 2016-12-01:
control logic: if bucket times over period of time > threshold, then action for specified period of time (eventually achieve "continuous" flow)

Closed 2017-04-28.

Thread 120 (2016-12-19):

[React] Create Initial Temperature Averages for Metadata Section

suyashkumar, 2016-12-19:
Create a view that computes and displays temperature averages (for the last 24 hours of data) for each probe. Similar to what existed before:

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

mlp6, 2018-05-21:
Need to remove "bad" data points to avoid skewing these data too much.

Closed 2018-05-21.

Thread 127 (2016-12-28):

[Firmware] Only publish BUCKET on change

suyashkumar, 2016-12-28:
@mlp6 @aforbis-stokes as mentioned in #65, does it make sense to only publish the `BUCKET` event (with the total number of counts) on a change in the bucket count (as opposed to every time we do a `TEMP` publish). This way we'll save cellular data and space in the database by not holding on to redundant publishes.

Thoughts?

mlp6, 2017-01-27:
change since last successful publish event

suyashkumar, 2017-01-27:
whoops this hadn't been updated since the discussion in #65 -- but yes, publishing the change in bucket count since the last successful publish event would be best. This makes us a little less tolerant if we lose data (if the server is off or down--which should not really happen anymore) compared to the old solution, but we will save a ton of publish data and it'll be in a better form!

mlp6, 2017-01-27:
It appears that the return status of ``publish()`` isn't really a great indicator of actual success (if anything, just that the command was issued, but not truly successful) [https://community.particle.io/t/detecting-if-spark-publish-fails-to-communicate-with-the-cloud/11776/12]  I could try to pull data from the server back to the device to see if it was successful, but that would waste cell data.  For now I'm going to write the code assuming success, but also pass along the timestamp of when it thinks the last successful publish was.  If that timestamp doesn't agree with what the server has recorded, then we can at least know that the latest publish should assumed to be over a shorter time duration and report back no estimate of bucket tips for the missing time.  @suyashkumar @aforbis-stokes sound good?

mlp6, 2017-01-27:
scratch that... it appears that the latest firmware has better support for this, so I'll setup some condition logic and assume dropped publish events that return ``True`` are rare (for now).

mlp6, 2017-01-27:
https://docs.particle.io/reference/firmware/photon/#particle-publish-

mlp6, 2018-05-21:
Bucket tips are now at all sites, so this is an expected published metric.

Closed 2018-05-21.

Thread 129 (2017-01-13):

PinchValve class

mlp6, 2017-01-13:
Create a PinchValve class that actuates the stepper motor, and also has flexibility to take input feedback (future date).

mlp6, 2017-01-13:
You may want to directly inherit from the gas `Valve` class and change for the pinch valve case.

Closed 2017-04-28.

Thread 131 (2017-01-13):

Migrate to discrete components or stick with "stock" controller?

mlp6, 2017-01-13:
Need to figure out if we want to stick, longer-term, with the out-of-the-box controller, or just use a subset of control components integrated on the control board.  Daniel will investigate this after getting the stock controller board working.

DanielHull, 2017-02-19:
@mlp6 I have a few thought on this issue. The majority of the components on the stock controller are used (https://cdn.sparkfun.com/datasheets/Robotics/EasyDriver_v45.pdf). We could recreate the schematic w/o the voltage regulator and eliminate maybe a square cm of the board though. The following datasheet has good explanations on how we could robustly add this linear stepper to our pcb. (https://cdn.sparkfun.com/datasheets/Robotics/A3967-Datasheet.pdf) Thoughts?

mlp6, 2017-02-20:
Not sure if that is worth it... how many discrete components would we need to add, and what coding overhead would we introduce if we couldn't "talk" though simple digital write operations?

Closed 2017-04-28.

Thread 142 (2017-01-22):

Decide on pin mapping

DanielHull, 2017-01-22:
investigate if there are any desired considerations for which GPIO pins to assign specifically

aforbis-stokes, 2017-01-23:
We current use D0,2,and 4 for pump, valve and igniter. Using the other D# pins would be ok. The only concern I can think of would be crowding on the board with more outputs there, but I don't see that being much of an issue.
All C pins are open except for C4 as well. One consideration I just had, though, is if we ever wanted to use a Photon (maybe only for the lab), that does not have C pins. Don't know if that would be worth considering, but it came to mind.

mlp6, 2017-01-23:
pin_mappings.h contains all of the current pin usage.  You should be able to use any that are open if you just need digital out.  Only a subset can be used for PWM output if that is needed.

DanielHull, 2017-01-23:
Yep, I had seen that, just wanted to see if there were additional specs I had overlooked from a wiring and ease standpoint in the physical system. I'll go with the unused D pins!

mlp6, 2017-01-23:
The only other consideration is that only a subset of pins can be used for interrupts, and if possible, we should keep those free for future event detection.  The interrupt pins have some strange pairings under the hood (i.e., some pins cannot be used as independent interrupts, etc.).

Closed 2017-02-13.

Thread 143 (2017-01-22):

Develop 'reset' of the system functionality in constructor and method

DanielHull, 2017-01-22:
I wonder if I can save a flow_position variable to the EEPROM or some storage compartment so it knows how many turns to make to get back to 'home'

DanielHull, 2017-01-22:
maybe particle.variable???

suyashkumar, 2017-01-23:
@DanielHull Do we still intend to use contact switches on either extreme of the linear stepper's range of motion? I think it'd be good to have some crude physical feedback in addition to a software persistent storage solution in case the stored value is somehow corrupted or wrong (I know it's high torque, but is it possible for someone to physically move the stepper by accident?). Though it adds complexity so might not be good for now, but if we see issues also consider coupling a potentiometer to the motion of the stepper in the future.

Software-wise, the electron has [emulation EEPROM](https://docs.particle.io/reference/firmware/electron/#eeprom) that actually persists data to flash memory :). You should be able to write a step count or distance to home value here. Something to consider next is how often you wish to write this value (every N steps?). Luckily, since this isn't EEPROM, you will not suffer wear on each write to an address but "only when the page fills up"--look more into this.

DanielHull, 2017-01-26:
@suyashkumar thanks Suyash, I think we could definitely implement them.

 I think I found a way to do it without monitoring the position of the pinch valve. I create an array of the most recent 6 bucket tip updates, which at every 2.5 minutes, allows me to calculate the flow rate over the past 15 minutes (calculates # buckets/hour). Once it moves towards extremes from the target flow rate, the clamp does it's job. Haven't tried with the Duke ADPL yet though, in this way if there are no bucket tips at all, the feedback is to open it back up.

Closed 2017-03-29.

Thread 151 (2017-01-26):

[React Client] Implement Real-Time Updates

suyashkumar, 2017-01-26:
Use SocketIO to consume real time update events from the server. Things to consider:

- Might interrupt data exploration with a new fetch every 2.5 mins.
- May reset the downsampling factor to default if it has been changed

@aforbis-stokes what's the priority in your opinion on consuming real time data updates from the server and auto-refreshing? Will this interrupt any data exploration you're doing if it fetches new data every 2.5 mins? how does this compare to maybe getting an unobtrusive notification that new data is available and only refreshing if you hit the refresh button?

aforbis-stokes, 2017-01-27:
I don't think the interrupt of data exploration with new data coming in will be much of an issue. The online visual is very nice for getting a picture of how operation is currently going and how it has been for the last few days/week. Any in-depth exploration will likely happen with downloaded data. In that case the new data coming in would not be a problem

suyashkumar, 2017-01-27:
Sounds good, real time updates on the `/new` front end is slated for implementation then :)

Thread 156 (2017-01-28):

[Investigation] SSE Stream Reconnection Problems

suyashkumar, 2017-01-28:
Sometimes the SSE stream throws an error that it does not seem to recover from (because we'll stop receiving publish events.

Sample of logs below:
```
{ coreid: '3e001d000e51353432393339',
  time: 2017-01-25T15:18:33.428Z,
  loc: 'ADPLKenyaN3763',
  temps:
   { HXCI: '24.1',
     HXCO: '-63.7',
     HTR: '22.2',
     HXHI: '20.9',
     HXHO: '22.0' },
  valveStatus: undefined }
{ coreid: '3e001d000e51353432393339',
  time: 2017-01-25T15:18:33.789Z,
  loc: 'ADPLKenyaN3763',
  data: 218 }
ERROR (Likely Event Source)
Event { type: 'error' }
ERROR (Likely Event Source)
Event { type: 'error', status: 502 }
```

suyashkumar, 2017-01-28:
Looking at the eventsource library source, it binds `onConnectionClosed` to the `error` event [in `connect()`](https://github.com/EventSource/eventsource/blob/master/lib/eventsource.js#L172). `onConnectionClosed` has retry logic that is reproduced below:
```
function onConnectionClosed() {
    if (readyState === EventSource.CLOSED) return;
    readyState = EventSource.CONNECTING;
    _emit('error', new Event('error'));

    // The url may have been changed by a temporary
    // redirect. If that's the case, revert it now.
    if (reconnectUrl) {
      url = reconnectUrl;
      reconnectUrl = null;
    }
    setTimeout(function () {
      if (readyState !== EventSource.CONNECTING) {
        return;
      }
      connect();
    }, self.reconnectInterval);
  }
```
The reconnect interval default is 1000ms. The error messages we see are consistent with the additional error being emitted in `onConnectionClosed()`. We do know, however, that no more error events are emitted which either means that subsequent errors are not handled properly or there's an issue relaying event after an error reconnect

suyashkumar, 2017-02-23:
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
More errors -- to be clear, these are coming from the *particle* server (returning 502s). Seems like they've become much less reliable since we started. We seem to be retrying the stream a number of times but it continues to fail on their end. After the stream fails we don't get any more SSE messages until our server is restarted. I'm not sure why the retry logic in the library (in the comment above) does not continue indefinitely (perhaps it gets a valid connection but receives no messages on it? That would be scary and hard to detect). We may need to invest some time in building more sophisticated retry logic on top of what's already included in the library (exponential backoff, retry connection if it's been x mins since receiving a message). It's also becoming increasingly necessary for us to start firing off alert emails when things like this occur so that we maintain data integrity.

suyashkumar, 2017-03-18:
Another one
```
{ coreid: '24002d000951343334363138',
  time: 2017-03-17T18:22:39.433Z,
  loc: 'Kenya-North',
  temps:
   { HXCI: '21.5',
     HXCO: '26.9',
     HTR: '47.2',
     HXHI: '27.7',
     HXHO: '24.9' },
  valveStatus: '1' }
{ coreid: '400057000a51343334363138',
  time: 2017-03-17T18:22:48.564Z,
  loc: 'Duke',
  temps:
   { HXCI: '21.6',
     HXCO: '21.2',
     HTR: '20.9',
     HXHI: '21.2',
     HXHO: '23.3' },
  valveStatus: '1' }
{ coreid: '400057000a51343334363138',
  loc: 'Duke',
  time: 2017-03-17T18:22:48.564Z,
  data: '2' }
ERROR (Likely Event Source)
Event { type: 'error' }
ERROR (Likely Event Source)
Event { type: 'error', status: 502 }
```

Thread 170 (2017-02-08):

System-specific software pushes on web interface

aforbis-stokes, 2017-02-08:
The variables that local operations would like to have access to alter for their systems are below:
pin_mapping (e.g. move HTR to A5 if A2 becomes damaged)
Temp high/low settings (ADPL-electon.ino INCINERATE_LOW_TEMP & INCINERATE_HIGH_TEMP, line 32 & 33)
Time between ignition (ADPL-election.ino IGNITE_DELAY, line 34)
Delay between valve open and ignite (ADPL-electron.ino delay (100), line 74)
Igniter on time (ignitor.h _ignitor_on_time, line 13)

One point of discussion is that most of these variables will only be altered during initial system setup, and once operation is consistent, they will remain unchanged.

mlp6, 2017-02-10:
@aforbis-stokes for the delays, do you have bounds and increments that should be adhered to?  Something to make sure that a nonsensical value doesn't get passed onto the device.  Could be set by pulldown menu if in larger, discrete chunks, or be a number entry box with min/max limits.

aforbis-stokes, 2017-02-10:
For delay between igniter ignition: If text entry, 1 min increments should be fine; bounds at 1 and 60. If options in a pull down, something like 10, 15, 20, 30, 45, 60
Delay valve open and ignite, 100ms increments up to 5s or if pull-down menu: 100ms, 500ms, 1s, 2s, 3s, 4s, 5s

aforbis-stokes, 2017-07-25:
Additional variables to add to the list:
VOLUME - Tipping bucket volume changes per location
OPTIMAL_FLOW - Different expected flow rates per location
PUBLISH_DELAY - When performing field diagnostics, receiving publishes (e.g. temps) every 2.5 min can eat up time. Temporarily decreasing PUBLISH_DELAY will make this easier. Will have to be confirm that this will not create other problems.

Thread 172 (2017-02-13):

Decide on SMT for passive components

DanielHull, 2017-02-13:
SMT's will be easier to fix if we keep them at 0806's. I'm worried the vias will lose connection with through holes (happened to me a lot) as components are replaced. Of course many of these like the electron will have to be on headers

aforbis-stokes, 2017-02-15:
I'm ok with SMTs as long as they are components that will never need replacing. I have very little experience mounting SMTs, and I would not count on anyone in the field being able to replace/fix a damaged SMT. The only components I would see needing to replaced, though, are the LVR, timer blox pulse generator and then the external components that should connect via headers anyways (thermistors, Particle, etc)

DanielHull, 2017-02-15:
Hmmm good thoughts. I find surface mounts much easier in replacing components. @mlp6 what do you think?

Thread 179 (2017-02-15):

error in saving to databaseValidationError: Path `loc` is required.

mlp6, 2017-02-15:
Saw that on the server console when I went to restart it with the new device names...

suyashkumar, 2017-02-15:
Looking at the logs we seem to have received a message from a particle that wasn't in the map (or led to `loc` being undefined for some reason, see below). However particle `520051000351353337353037` is in the map and things seem to be working for now after the restart. Not sure why that happened. Did you perhaps pull without restarting the server? It's possible the map in memory and the map on disk didn't match up for a small window, but I still don't think that would have led to this.

```
{ coreid: '520051000351353337353037',
  time: 2017-02-15T17:49:29.922Z,
  loc: undefined,
  temps:
   { HXCI: '26.8',
     HXCO: '39.2',
     HTR: '70.9',
     HXHI: '69.8',
     HXHO: '35.4' },
  valveStatus: '1' }
error in saving to databaseValidationError: Path `loc` is required.
```

mlp6, 2017-02-15:
I think that @aforbis-stokes just changed that device overnight; so probably just a transient issue rearing its head.

suyashkumar, 2017-02-15:
Yeah, seems like a one off issue, I'll close this out for now.

Closed 2017-02-15.

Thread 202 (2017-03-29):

Get reset to work robustly

DanielHull, 2017-03-29:
Right now it glitches in resetting the position if one of the up and down interrupts are enabled

DanielHull, 2017-03-30:
Also, want to think about reset as a return to home function based on knowledge of position variable.

Closed 2017-04-28.

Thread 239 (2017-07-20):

Investigate usage of on-board RTC chip

mlp6, 2017-07-20:
write UTC time to the SD card file

mlp6, 2017-07-20:
outdated example syntax: https://github.com/bkobkobko/SparkCoreLibraries

mlp6, 2017-07-20:
It looks like the Electron has an on-board RTC... will use `Time.now()` to get UTC to write to the SD card.  Need to look into powering `VBAT` on the board to have the time persist across power cycles.  Maybe use a rechargeable that can be kept at voltage with the solar power... or a long-term coin cell.

mlp6, 2017-08-28:
@aforbis-stokes is there power going to the SD card (`VBAT` pin) board to maintain time on it?

aforbis-stokes, 2017-08-28:
Yes, SD is always powered by Electron

mlp6, 2017-08-28:
We'll need to test if the RTC maintains time after power cycles.  Something else for Graham to test once we figure out why the timestamps aren't being written (issue #253)

Closed 2017-09-04.

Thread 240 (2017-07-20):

website plot: limit max/min

mlp6, 2017-07-20:
re-map erroneous values (or NaN them?) so that the graph is not thrown off

aforbis-stokes, 2018-01-24:
Min limit <0 degC; Max limit >80 degC

mlp6, 2018-01-24:
This is something that can/should be done server-side.  We had originally tried doing this on the device so that erroneous values weren't being published, but that broke some of our legacy igniter control logic, and we we didn't want to open that can of worms and create (even more) heterogeneity across the systems.

mlp6, 2018-01-24:
@jhoballah is you comfortable having this in your wheelhouse and having @suyashkumar or I do a PR review on it?

aforbis-stokes, 2018-04-27:
Did we come to a conclusion on this one?

mlp6, 2018-05-08:
@aforbis-stokes you want these limits applied to all of the temperatures plotted, correct?

aforbis-stokes, 2018-05-08:
Correct

mlp6, 2018-05-21:
Might want to have the code default to a range of 0-80 deg, but then provide a slider, similar to the days shown slider, to allow the user to adjust on-the-fly so that the code doesn't need to be modified to adjust this range moving forward.

mlp6, 2018-05-21:
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

mlp6, 2018-05-21:
Example of what the clipped upper bound plot looks like... no data values remapped; just scaling y-axis of the plot.

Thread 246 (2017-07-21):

selectively include SD card library

mlp6, 2017-07-21:
We need to investigate the compilation error when we don't need the SD card... right now it is globally included on devices that don't have an SD card, which almost doubles our current firmware size... no bueno for OTA flashes.

CalNightingale, 2017-07-26:
To my knowledge, with `#include` statements it is impossible to selectively include the library short of commenting out the include line and recompiling (however, this will cause errors with all other SD-related functions, ex. SD publish functions)

Closed 2017-09-27.

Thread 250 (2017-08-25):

pinch valve not working

mlp6, 2017-08-25:
Latest code on `cal/fatlibmigration` not working correctly.  The pinch valve acts normally in a reset situation and actuates at the desired `WAIT_TIME`, it then however continues actuating in no discernible pattern, endlessly. It also gets stuck in a similar loop when actuated with one of the manual buttons.

mlp6, 2017-08-28:
mostly fixed, but pinch valve is not closing after bucket tip

mlp6, 2017-08-28:
appears to be related to some delay by ignitor firings, not software logic

Closed 2017-08-28.

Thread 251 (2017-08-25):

gas valve logic

mlp6, 2017-08-25:
The gas valve relay seems to be running opposite from the standard. And also is unresponsive to raising `T3` above the threshold.  This is on `cal/fatlibmigration`.

mlp6, 2017-08-25:
This appears to have been a hardware issue fixed with a new control box.

Closed 2017-08-25.

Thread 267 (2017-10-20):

Add Exhaust temp into published data string

aforbis-stokes, 2017-10-20:
Exhaust temp data will be used for data analysis. Should not be displayed on webpage (will look cluttered). Include in data publishes.

aforbis-stokes, 2018-02-23:
Bumping this issue back towards the top. We have some burner enhancements coming up and having access to the exhaust temperatures before and after the burner change will be useful.

aforbis-stokes, 2018-04-27:
Getting this Exhaust temp probe in the published data string is now a pretty critical update. When could we roll this out? @Graham-H-Miller did his own edit to some code to get the Exhaust probe read locally, but we need to be able to access it through a data pull. We can see the data stream in the Particle Console, so the hardware functionality with Graham's local software edit is working correctly.

aforbis-stokes, 2018-05-08:
I do not see any harm in always publishing the exhaust temp. I imagine there may always be something we can pull out of that. At the same time, we do use the bucket tip everywhere, all the time. Could switch the bucket tip to a variable that always publishes and the exhaust to an optional, as long as that does not conflict with how the bucket tip is written in. Either way, I'm good with whatever is easiest.

mlp6, 2018-05-08:
If the bucket tip is used everywhere now, then I think that we should simplify the code with the same publish/save string for all variables, all the time.

@suyashkumar can you confirm that your server-side string parser uses the variable name to parse the value and **not** the order of the variables being published?

mlp6, 2018-05-08:
issue #290 removed the optional `no_bucket` data string from being published/saved

need to confirm that 69 characters can still capture all of the new information being sent on the cell publish, and 79 characters is enough for the SD card save

mlp6, 2018-05-08:
@Graham-H-Miller can you confirm with the latest code, which you'll need to re-download here (https://github.com/mlp6/ADPL/archive/v2.6.0-alpha.1.zip), that the publish string for the cell isn't getting clipped?

Closed 2018-05-19.

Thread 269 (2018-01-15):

Calculate key metrics on backend

suyashkumar, 2018-01-15:
We should calculate efficiency calculations on the backend. @aforbis-stokes had the following snippet to inform the calculations to be made:

```
// Script for diagnostics
#define HXCI A0 // Heat Exchanger Cold Inlet
#define HXCO A1 // Heat Exchanger Cold Output
#define HTR A2  // Heater
#define HXHI A3 // Heat Exchanger Hot Inlet
#define HXHO A4 // Heat Exchanger Hot Outlet
#define PUMP D0
#define VALVE D1
#define IGNITOR D2
#define BUCKET C4
#define STEP D6
#define DIR D5
#define SLEEP D3
#define UP B5
#define DOWN C3
#define RESET C2
#define SD_CS_PIN B3
#define SD_CD_PIN B4
#define SD_DI_PIN B2
#define SD_DO_PIN B1
#define SD_CLK_PIN B0
//New definitions
#define DH // Dome height [cm], user input
#define CX_DH // Dome height cross-sectional area [cm2]
#define Q_WASTE // Waste (liquid) flow
#define Q_GAS // Biogas flow, [ccm], user input
#define TB_volume 0.325 // Tipping bucket volume conversion, L/tip
#define ValveStatus // Gas valve status, 1=open, 0=closed
#define C_p 4.19 // [kJ/L/degC]
#define U_gas 36.8 // Energy concent of methane [kJ/L]
#define CH4 0.60 // Fraction of biogas in methane
#define CODconc 42 // gCOD/Lwaste, based on location and flush volume
#define HTR_volume 8.7 // [L]

//Calculate the following for each day:
Q_WASTE = tips*TB_volume / last_publish_time
Biogas_used = AVG(ValveStatus)*AVG(Q_GAS) // [L]
Biogas_prod = ((DH1-DH0)*CX_DH + Q_GAS*AVG(ValveStatus)*(t1-t0)) / (t1-t0)
  //Gas production as fxn of change of storage volume and gas usage for given day
  //"1" and "0" are based manual entries for current day and previous day
Yield = Biogas_prod / (Q_WASTE/CODconc) //[Lgas/gCOD]
Heater_power = (tempHTR-tempHXCO)*Q_WASTE*C_p // measured gain, [kJ/d] convert to [W]
Gas_power = (Biogas_used*CH4*U_gas) // theo. power input, [kJ/d] convert to [W]
Heater_effic = Heater_power/Gas_power // efficiency of full heater (not burner)
HXcold_power = (HXCO-HXCI)*Q_WASTE*C_p // power gain in HX, [kJ/d] convert to [W]
HXhot_power_loss = (HXHO-HXHI)*Q_WASTE*C_p // power loss from HXhot, [kJ/d] convert to [W]
HX_effic = HXcold_power/HXhot_power_loss // How much heat goes from hot to cold
HX_recovery_effic = HXcold_power/Heater_power // How much of total heat is recovered
  if tips = 0 && ValveStatus=0 for 30 min
    then Loss = (HTR1-HTR0)*HTR_volume*C_p / (t1-t0) // decrease in temp over last 30 min
Burner_effic = (Heater_power+Loss) / Gas_power

//On-demand variables for troubleshooting
All temps & ValveStatus
Burner_effic // provide for last 6 readings
  //use AVG(Loss) of last 20 values
  //consider interrupt function for troubleshooting, read every 20s instead of 2.5 min
Heater_effic

//Error logs
if tempHTR < 62 for 15 minutes
if Heater_effic < 50
if Burner_effic < 75
if Q_WASTE < 0.5*OPTIMAL_FLOW*24 //OPTIMAL_FLOW is set in main in [L/hr]
if Q_WASTE < 2.0*OPTIMAL_FLOW*24 //OPTIMAL_FLOW is set in main in [L/hr]
```

mlp6, 2018-05-21:
@aforbis-stokes can you share what are using to currently do the calculations above?  it is a spreadsheet?

aforbis-stokes, 2018-05-21:
All of my calculations now are through a spreadsheet. I dump the data pull from the Suyash site in my spreadsheet, and copy in the field-recorded data.

Where do the Philippines (SD-based system) error logs go? I assumed these logs can go there. I am not as familiar with those as @Graham-H-Miller is. He's running the Philippines project, and I have not gone through the error logs.

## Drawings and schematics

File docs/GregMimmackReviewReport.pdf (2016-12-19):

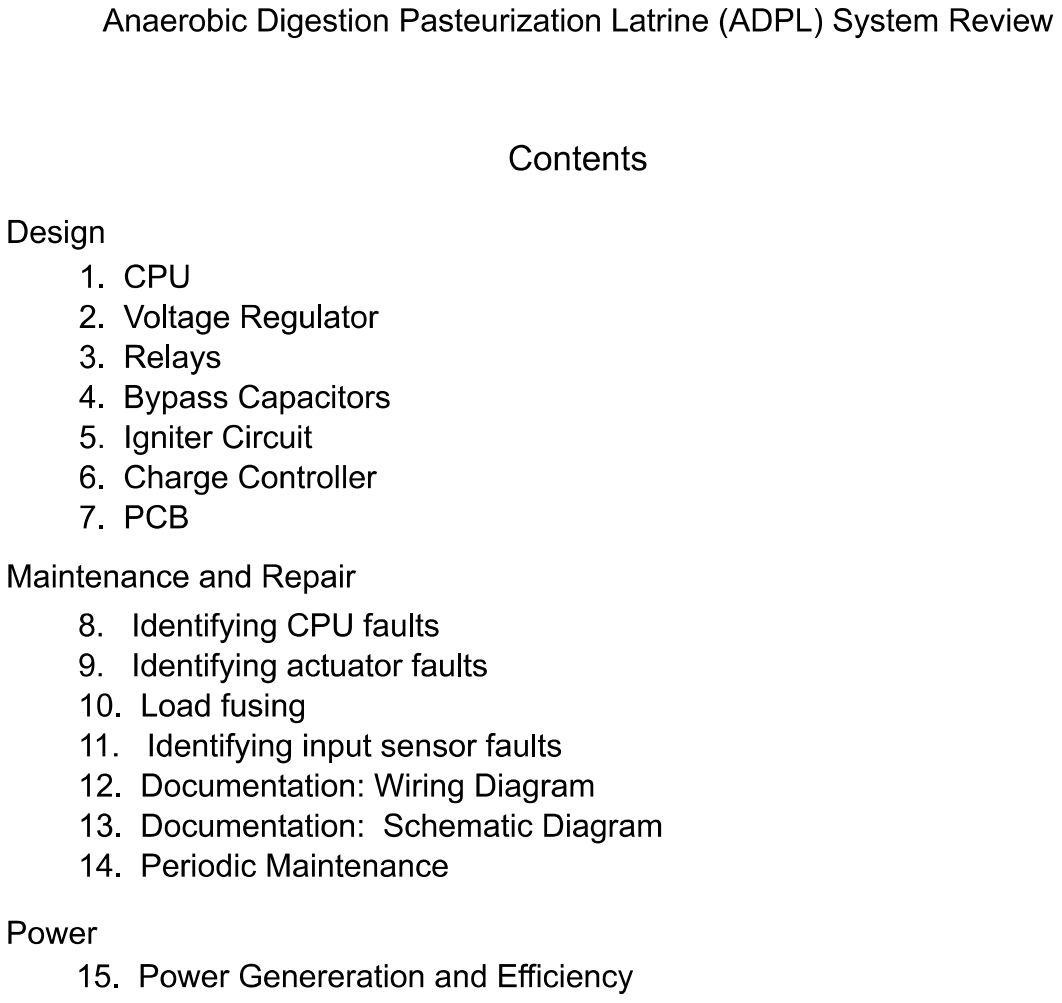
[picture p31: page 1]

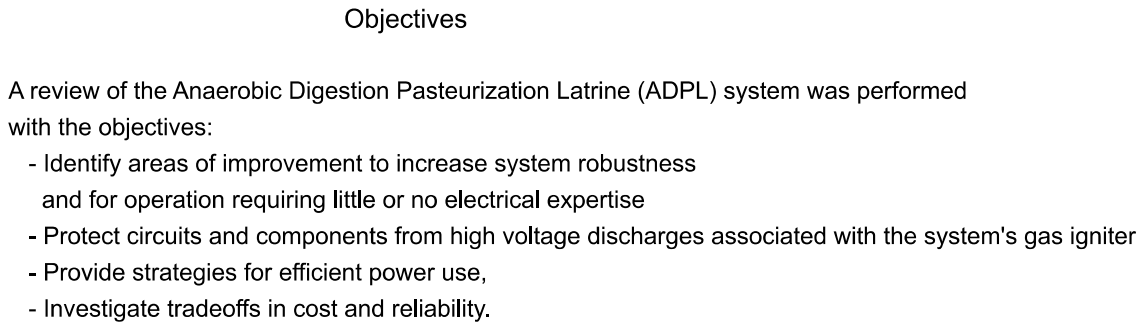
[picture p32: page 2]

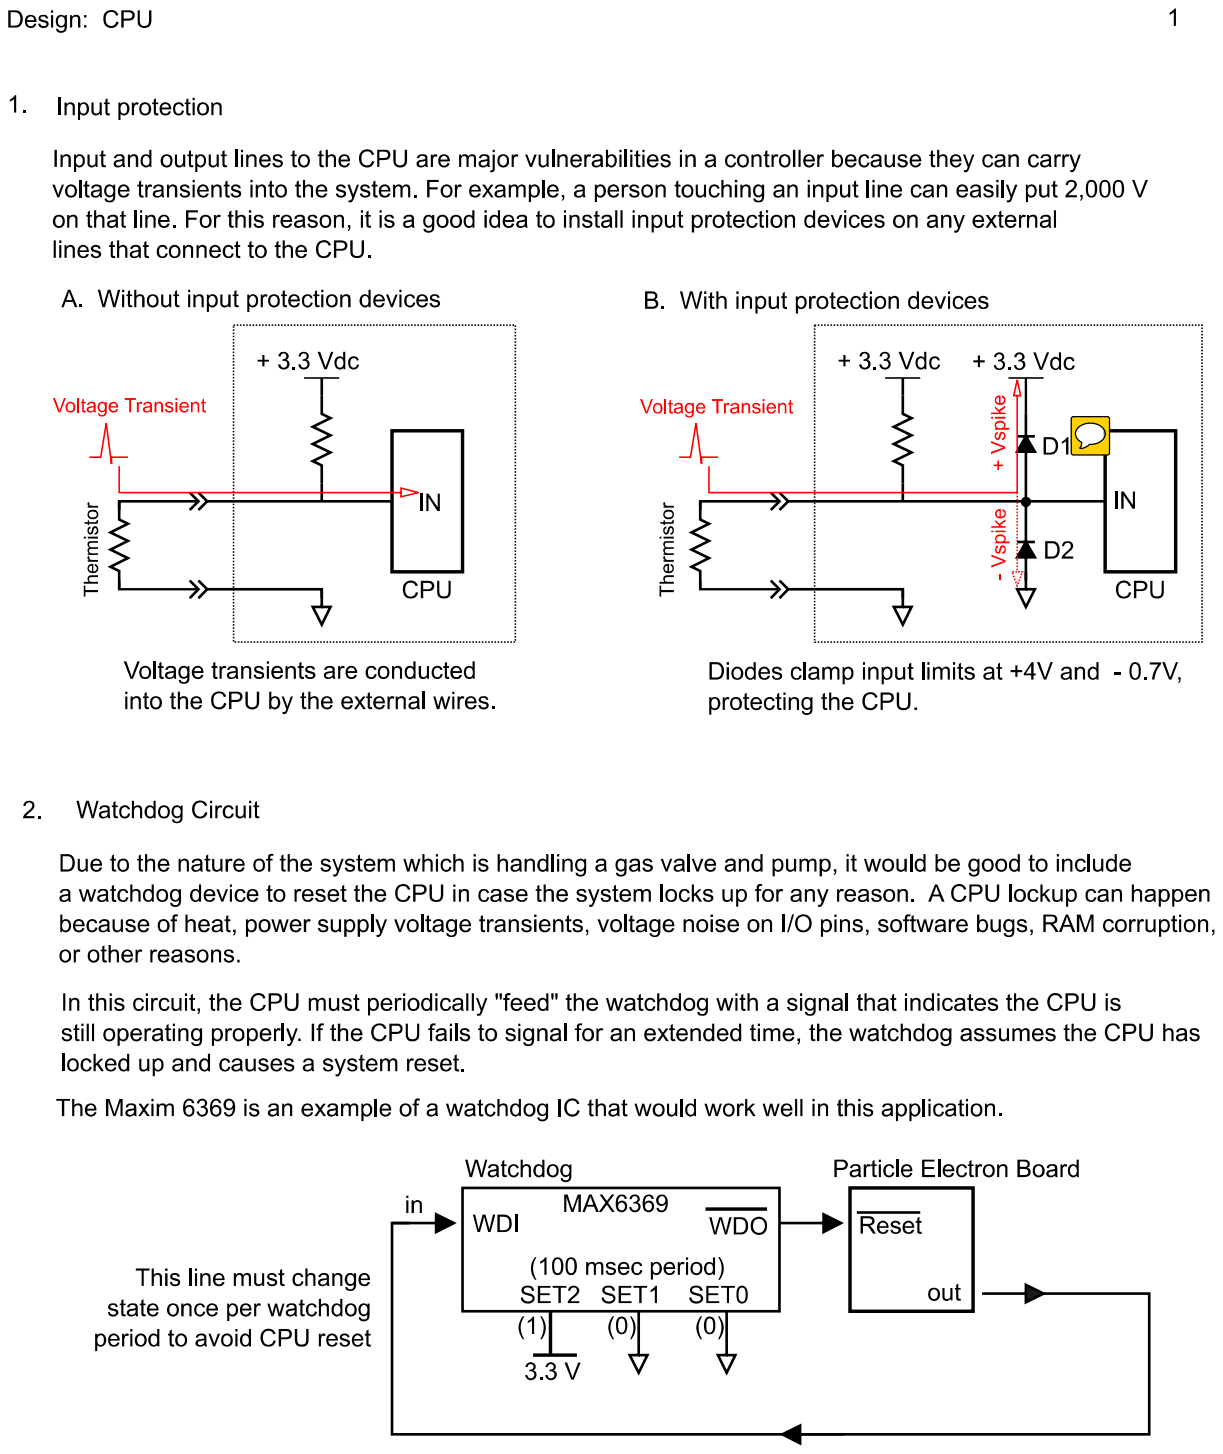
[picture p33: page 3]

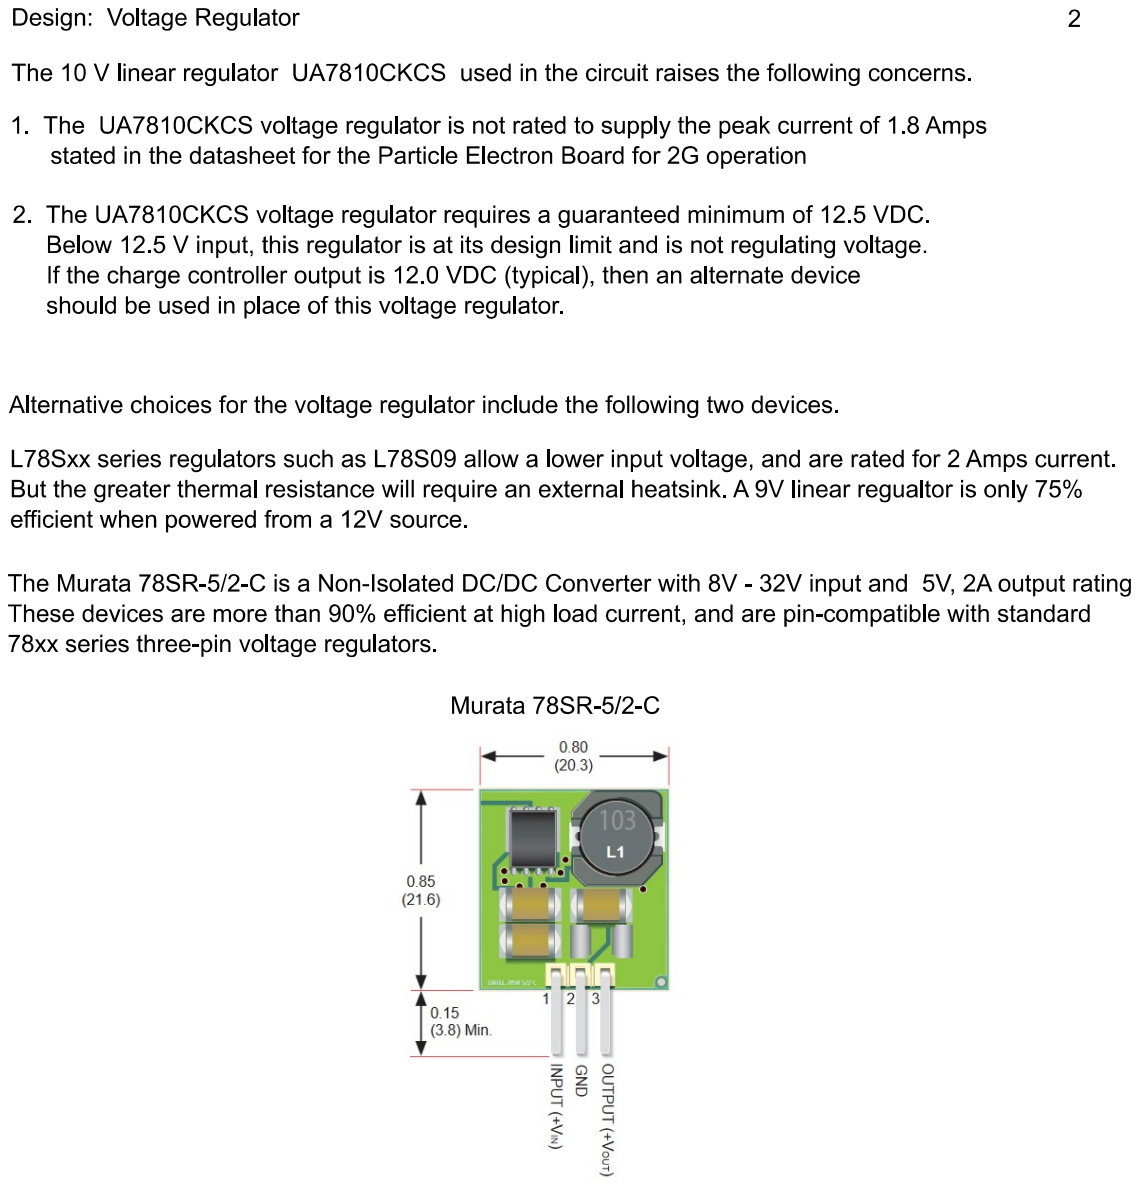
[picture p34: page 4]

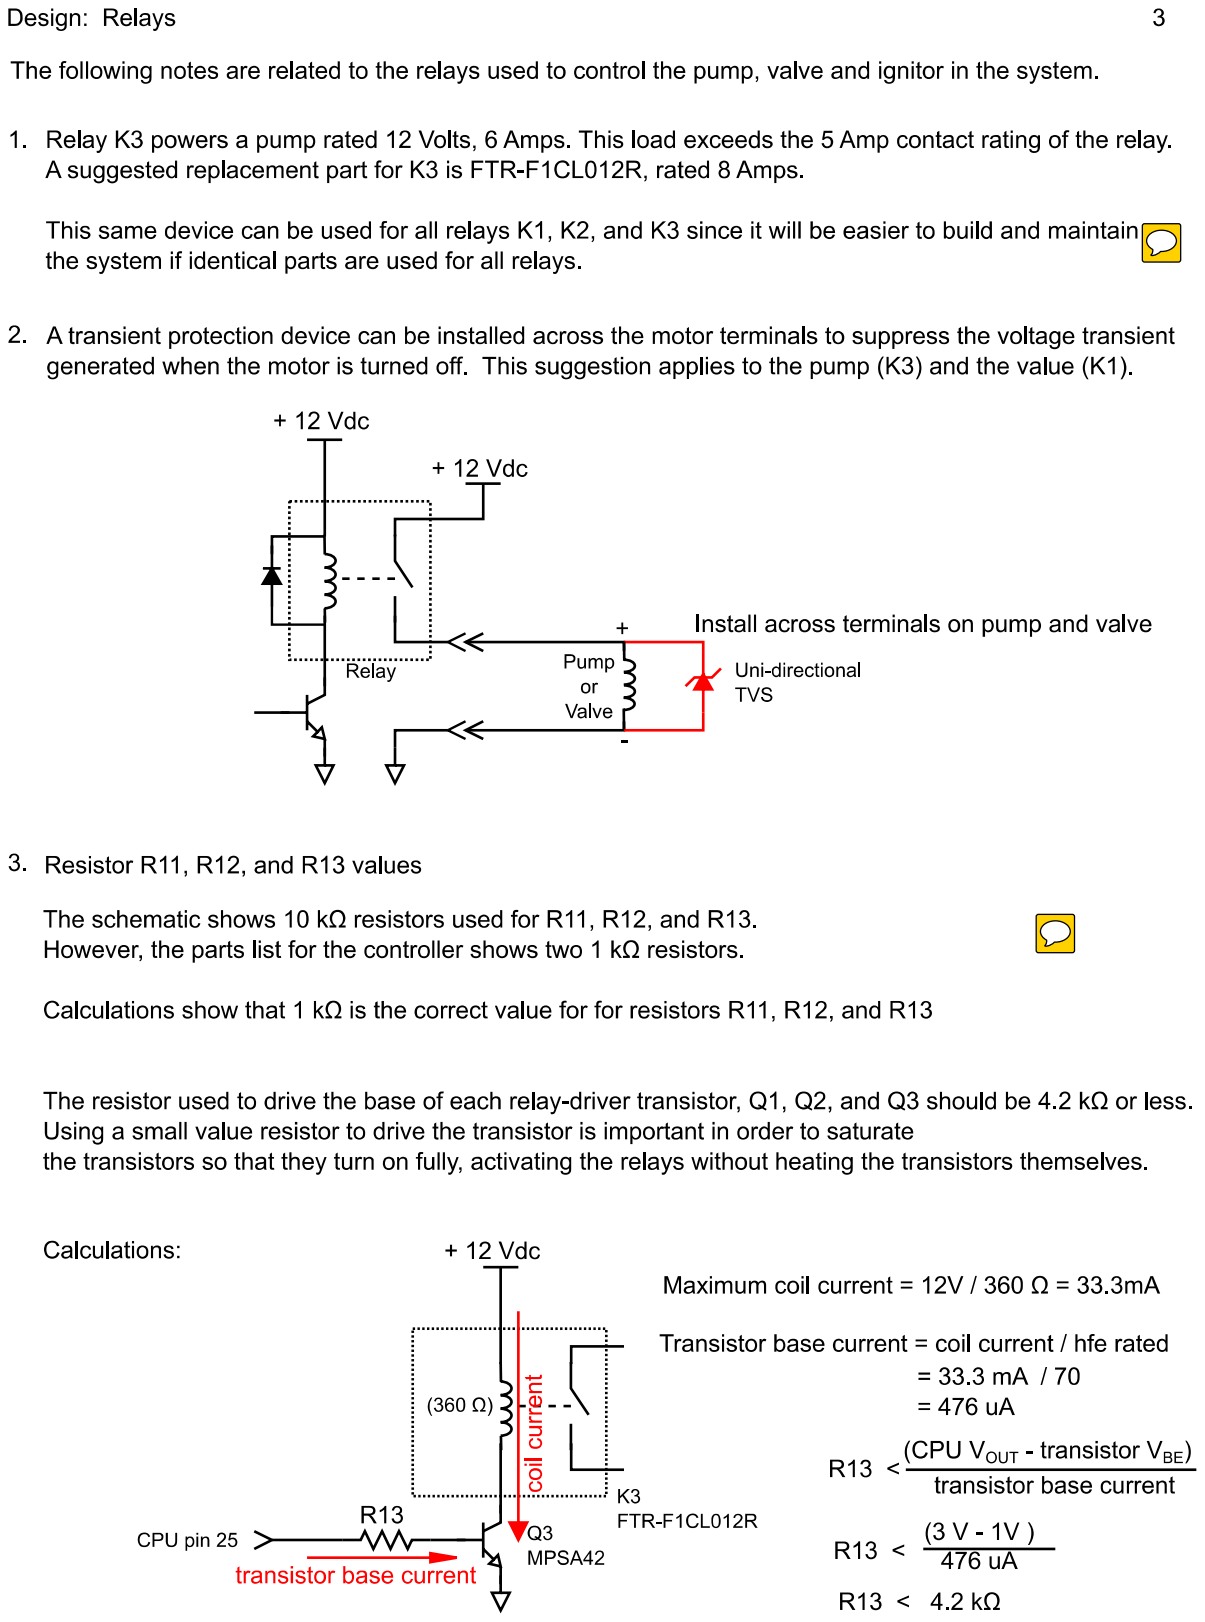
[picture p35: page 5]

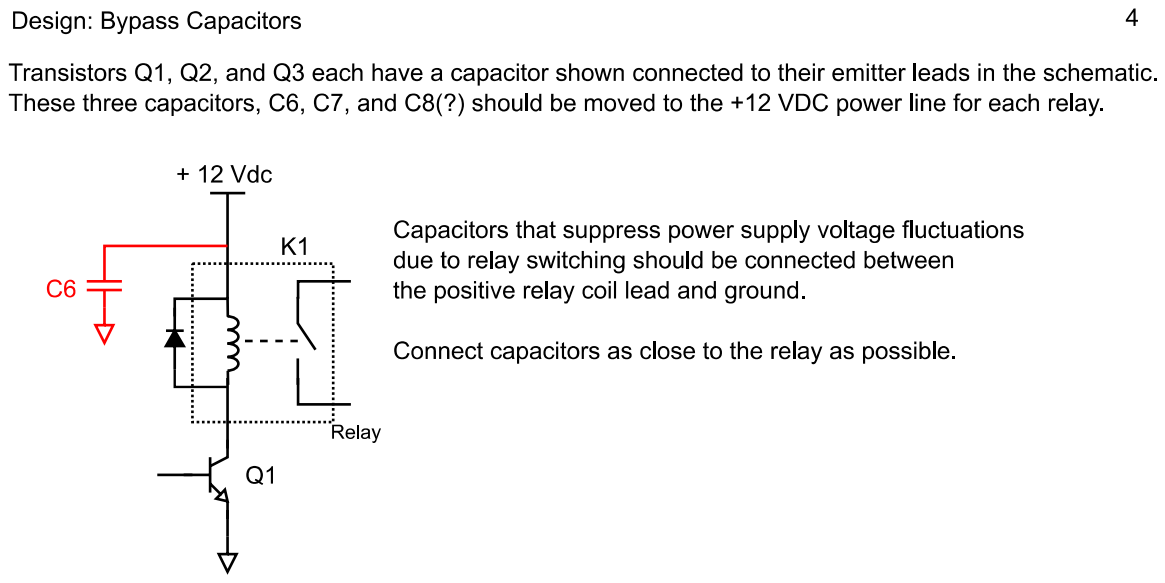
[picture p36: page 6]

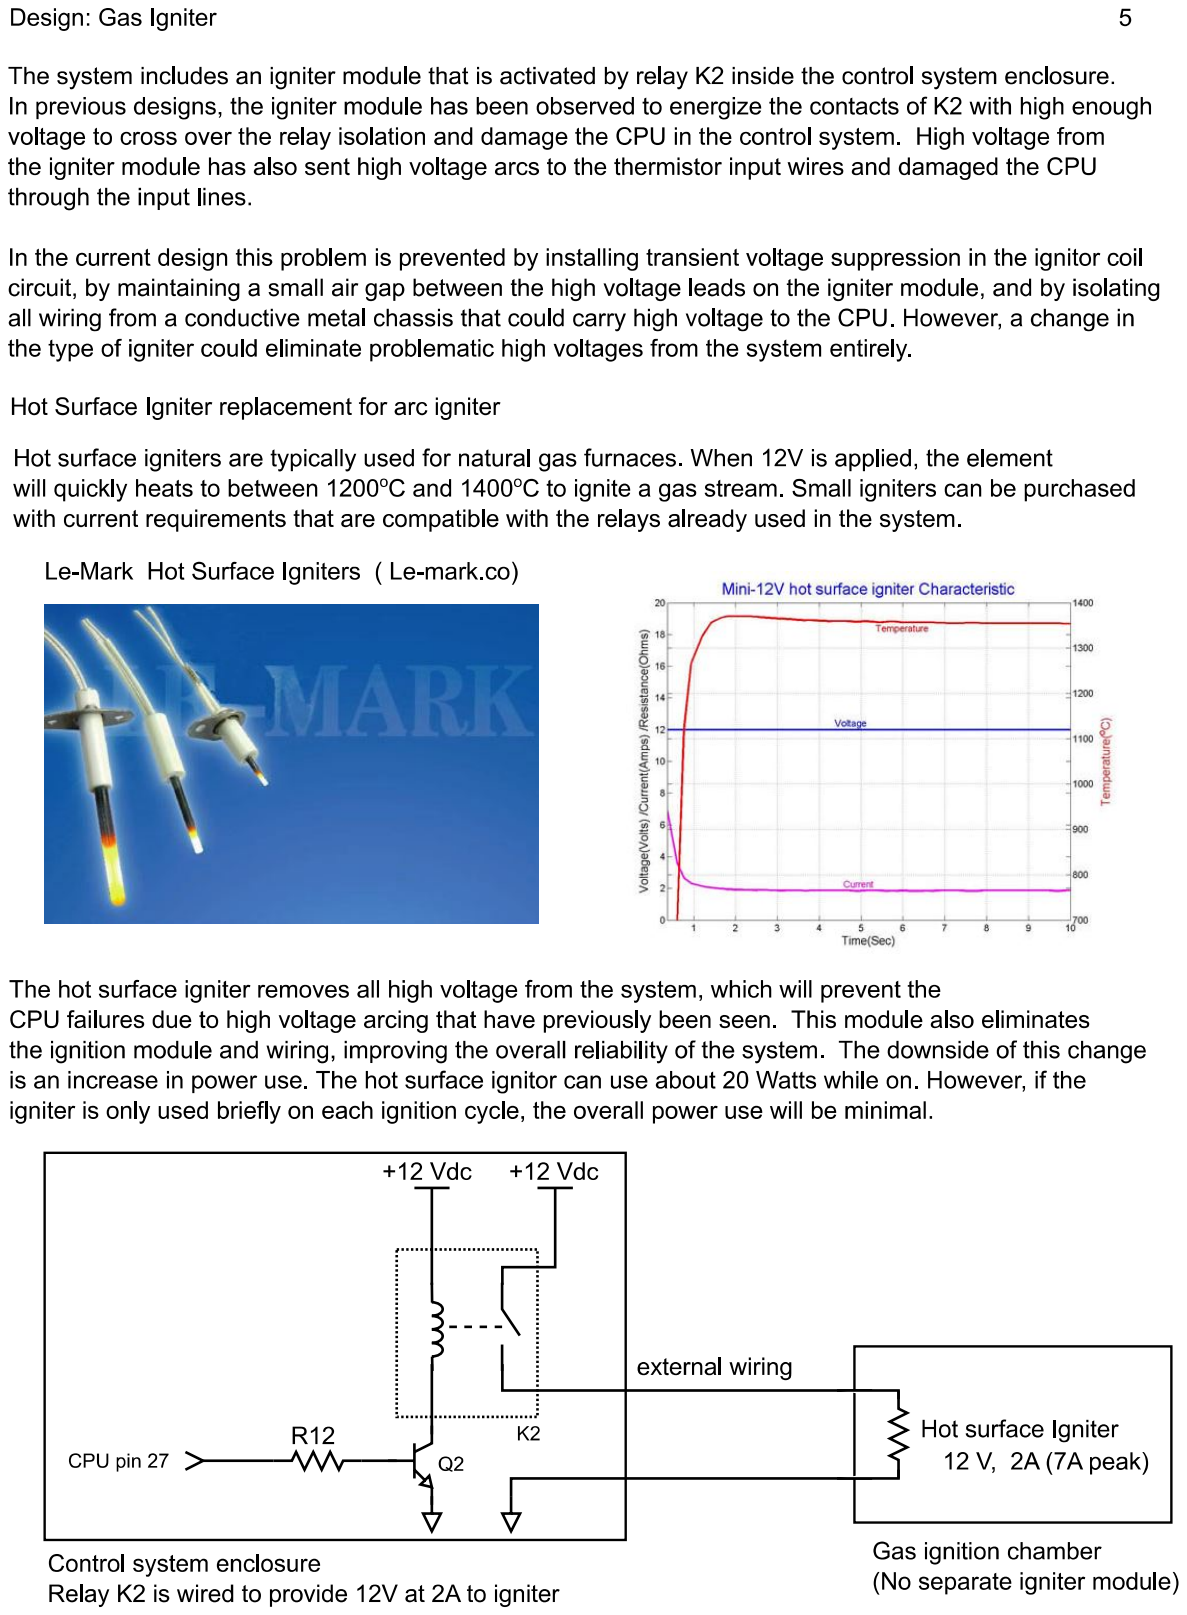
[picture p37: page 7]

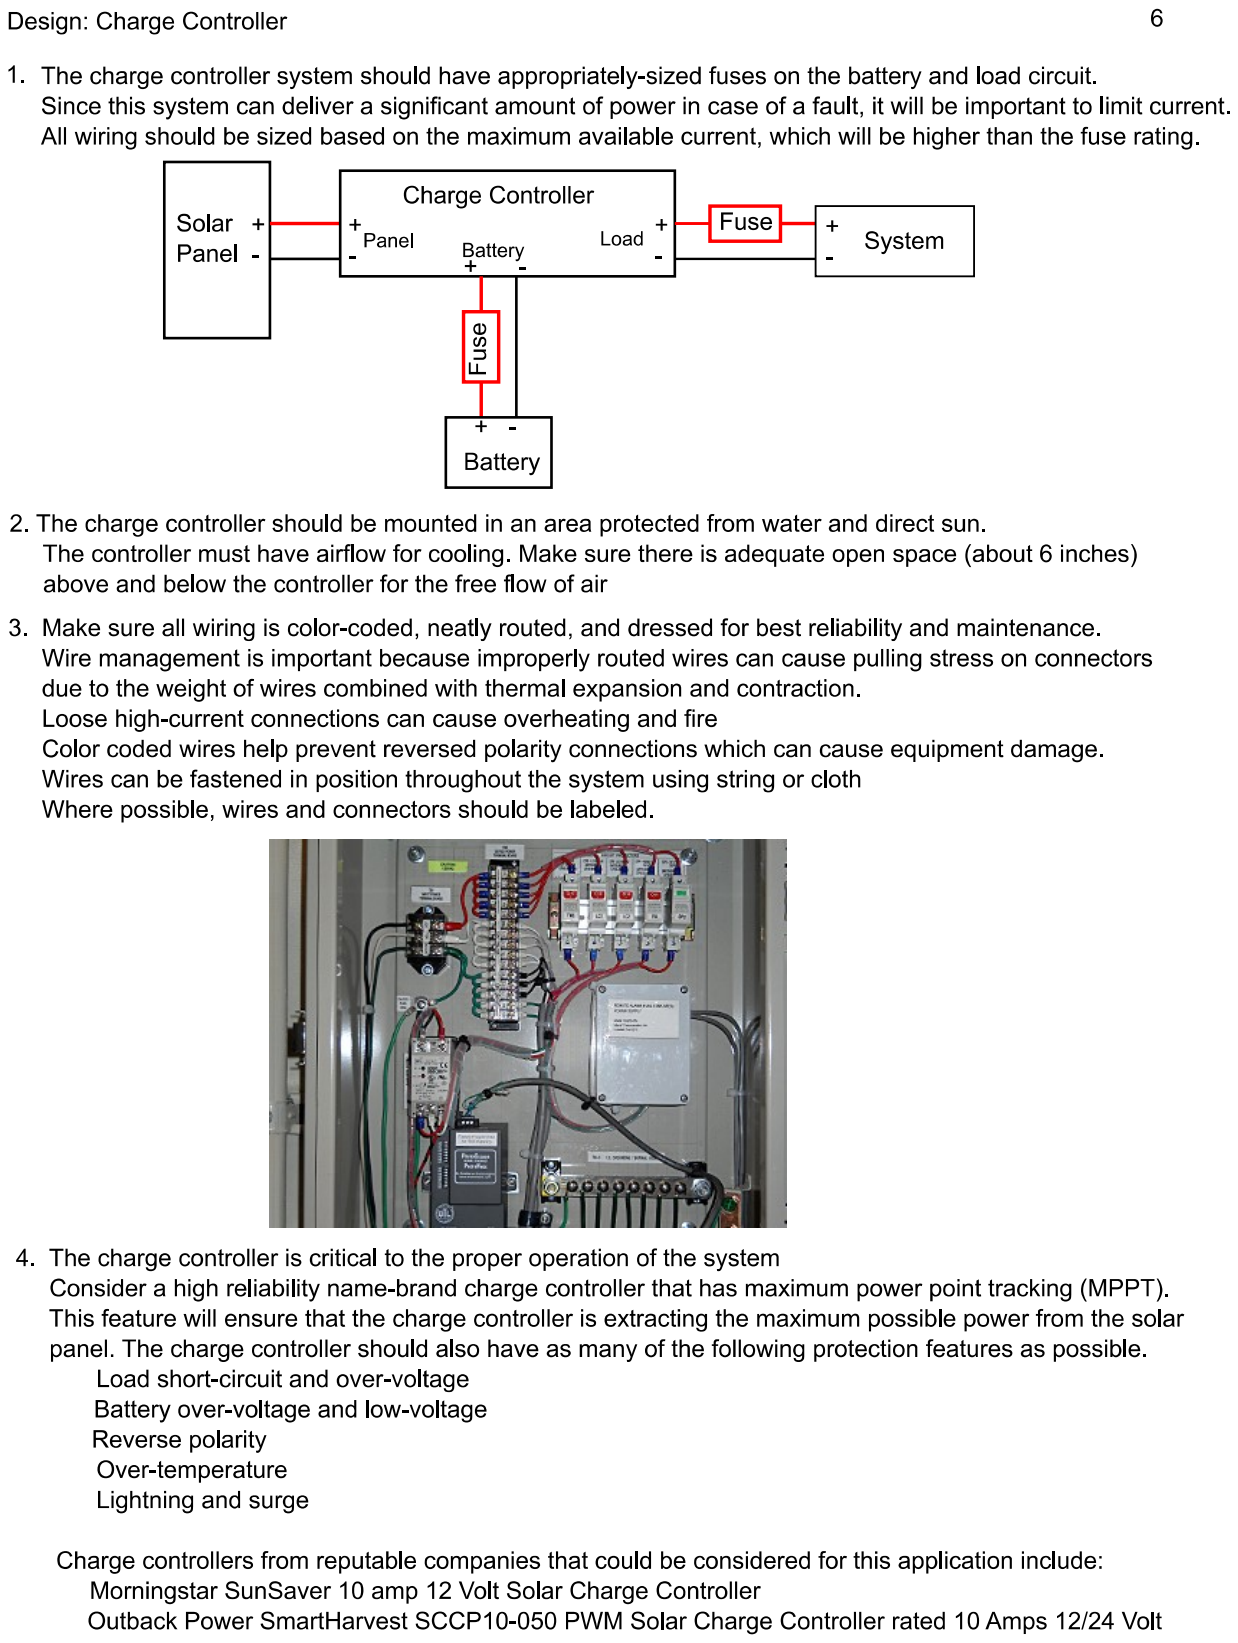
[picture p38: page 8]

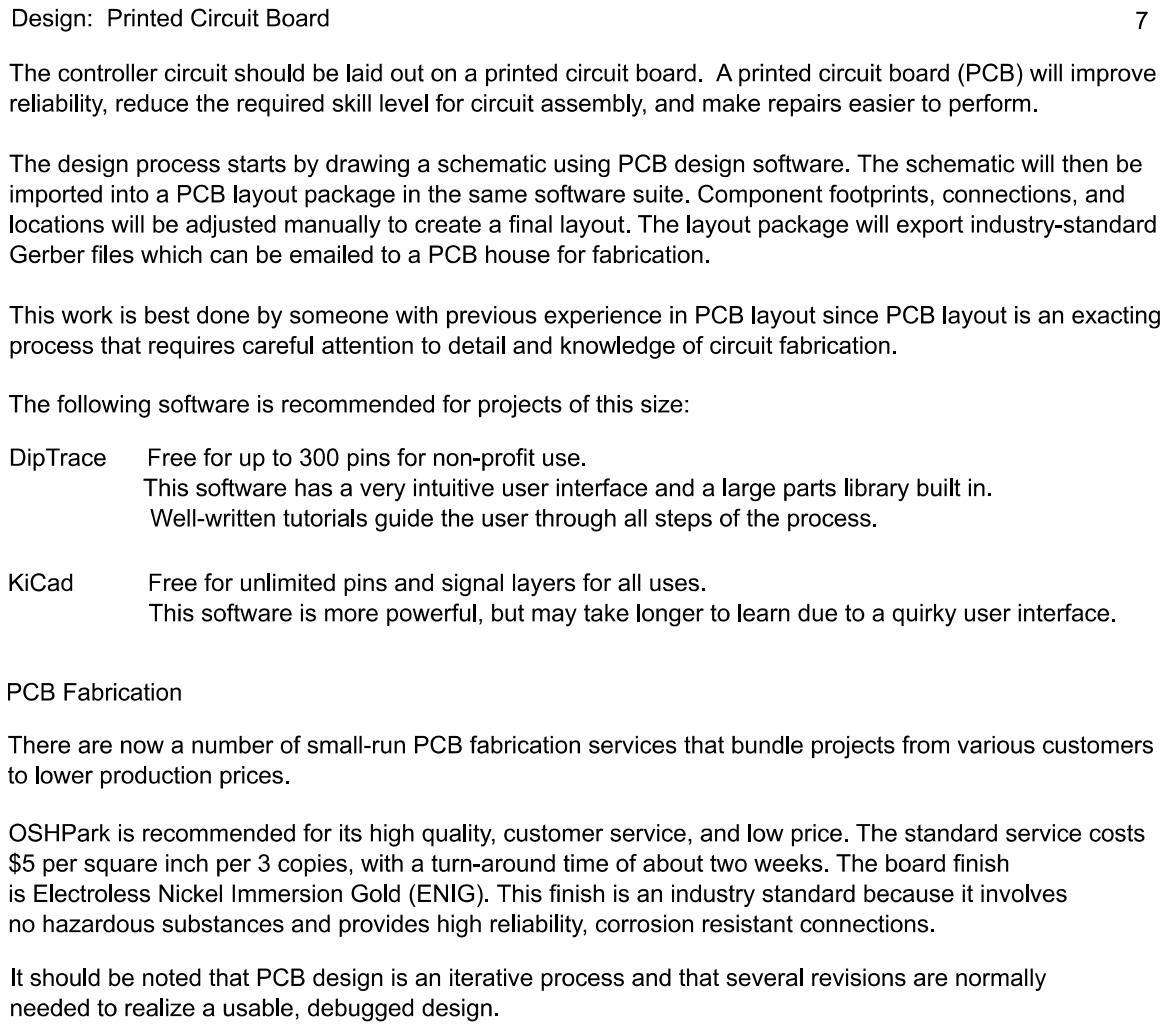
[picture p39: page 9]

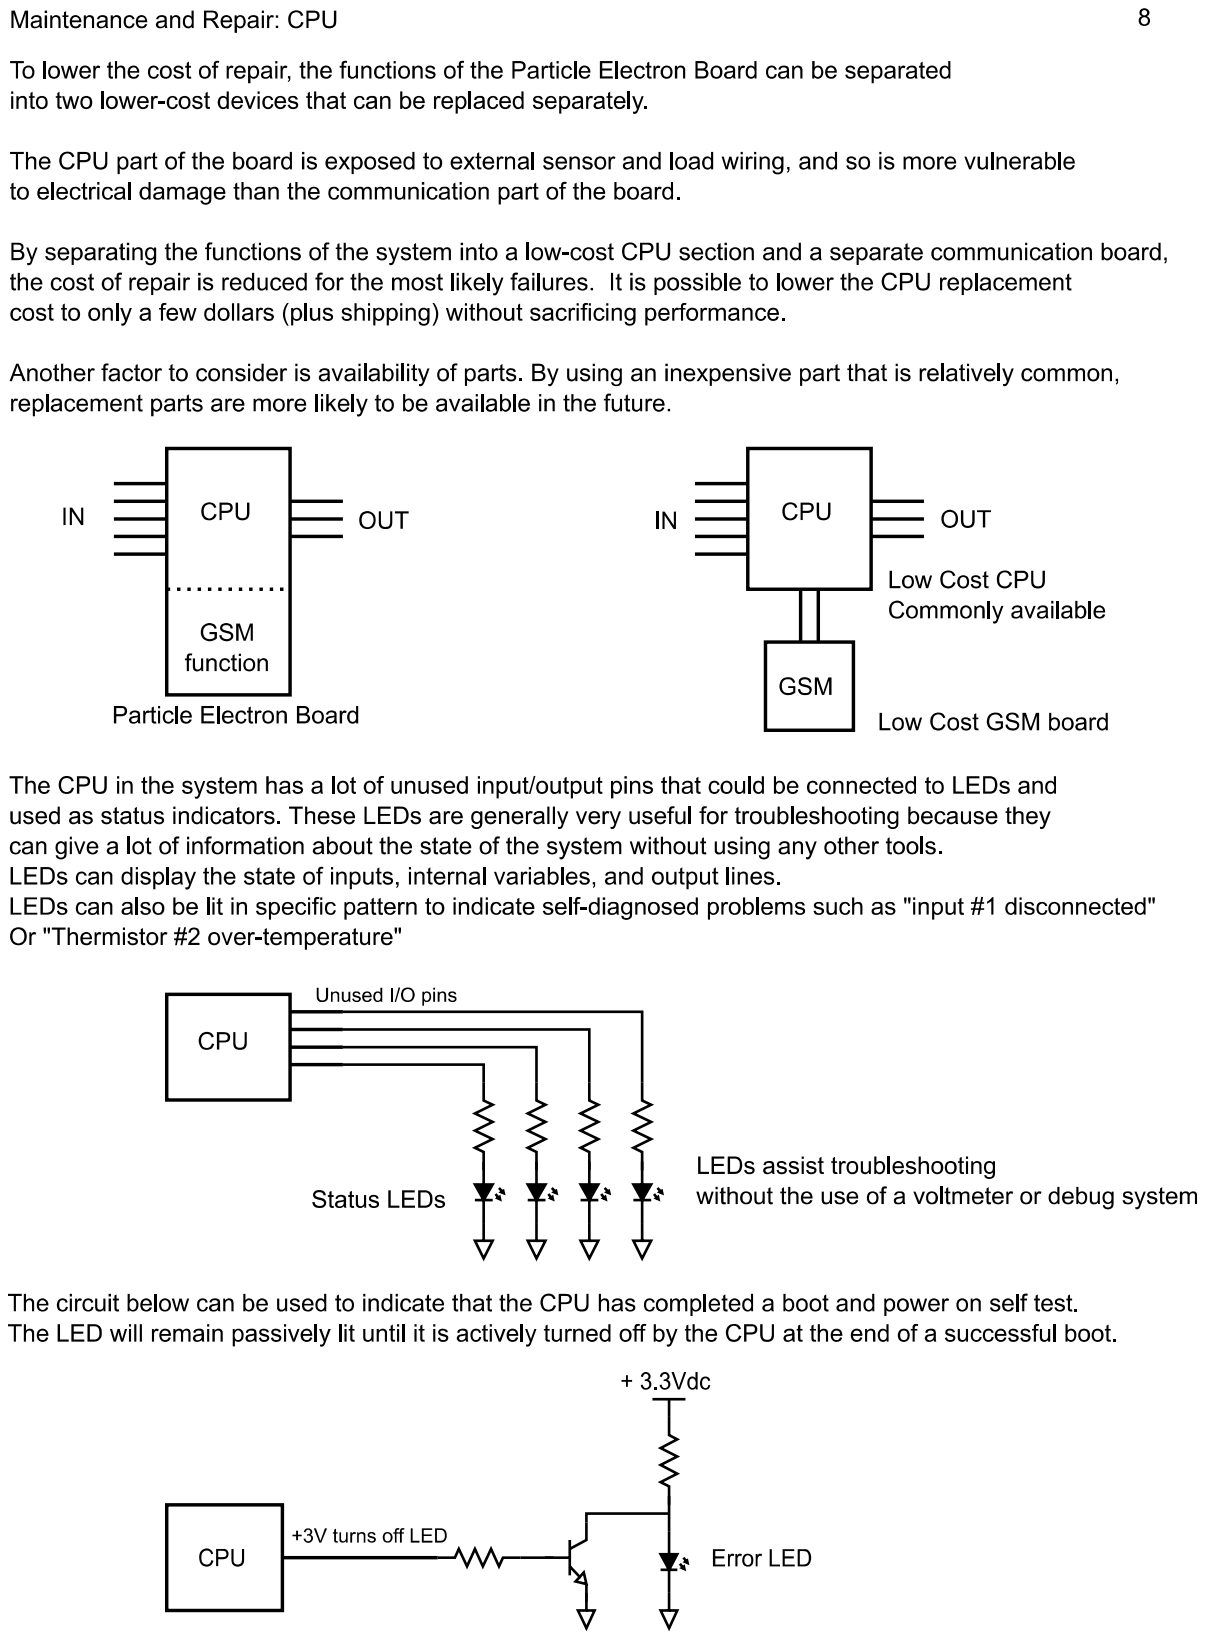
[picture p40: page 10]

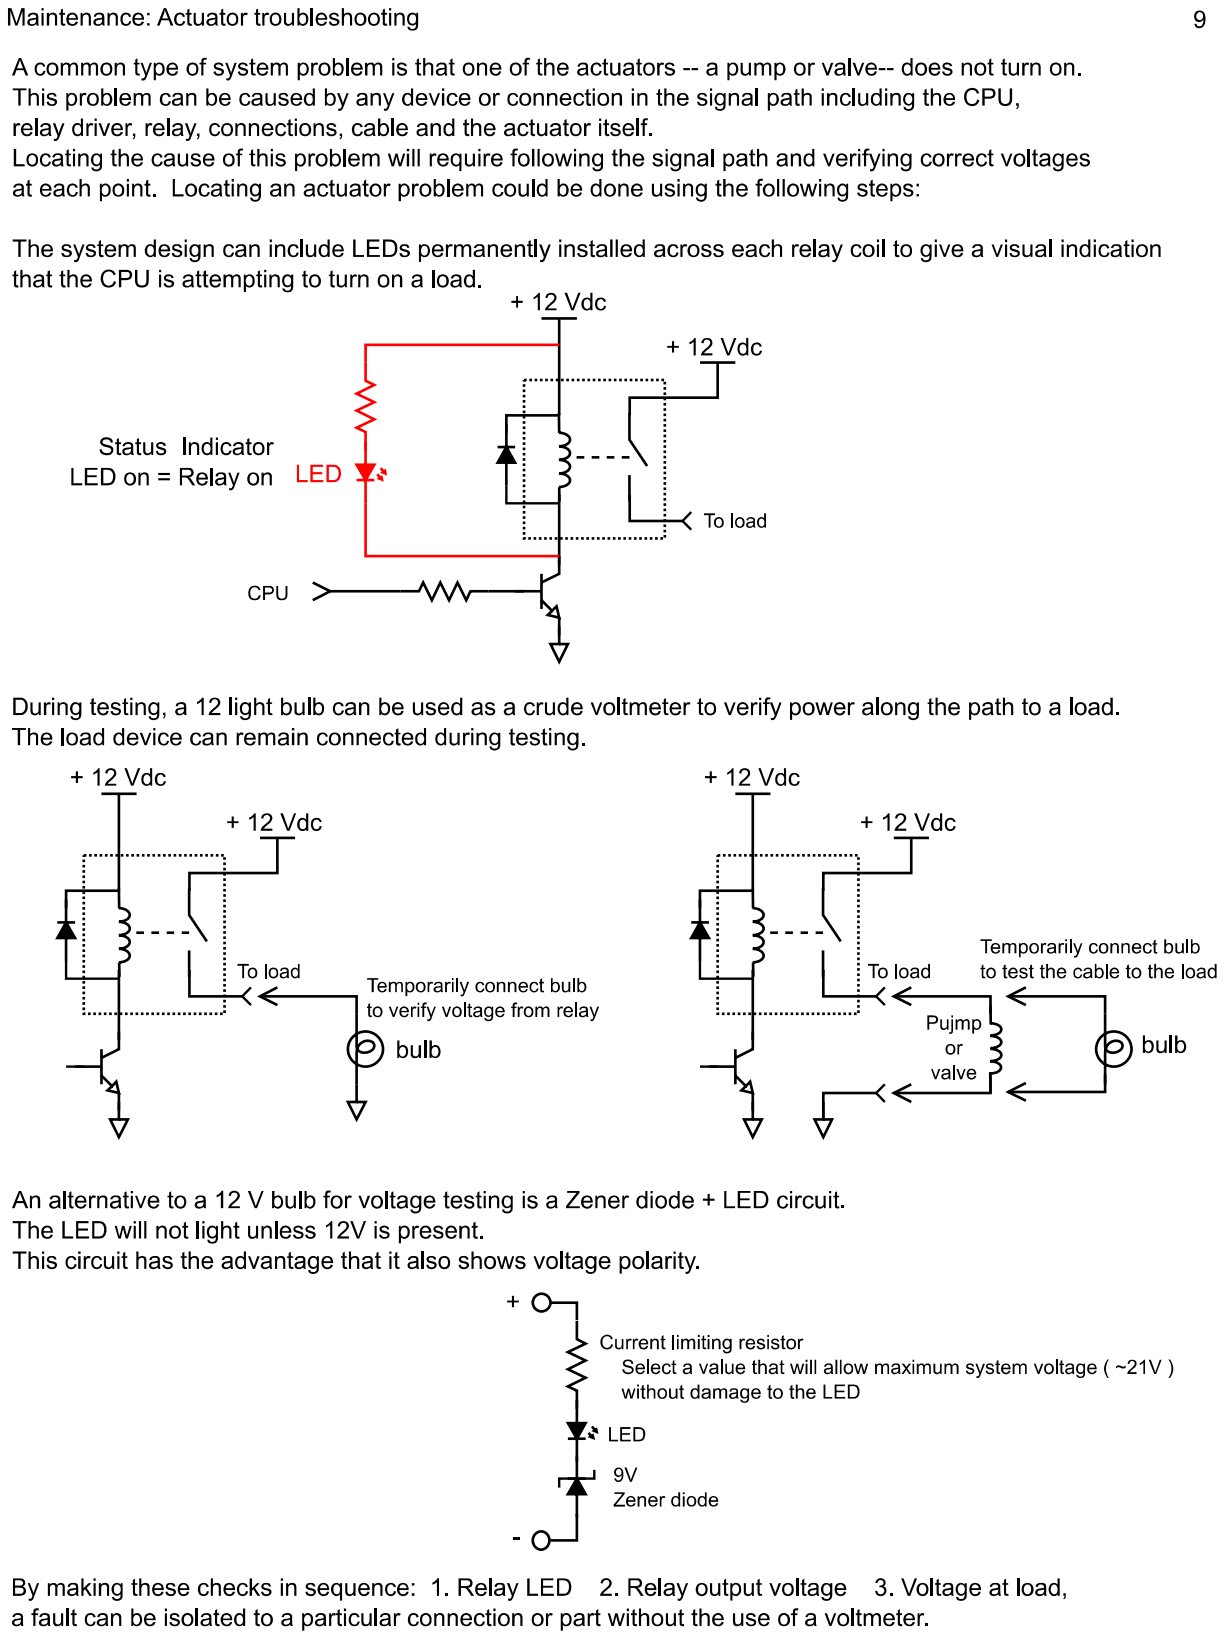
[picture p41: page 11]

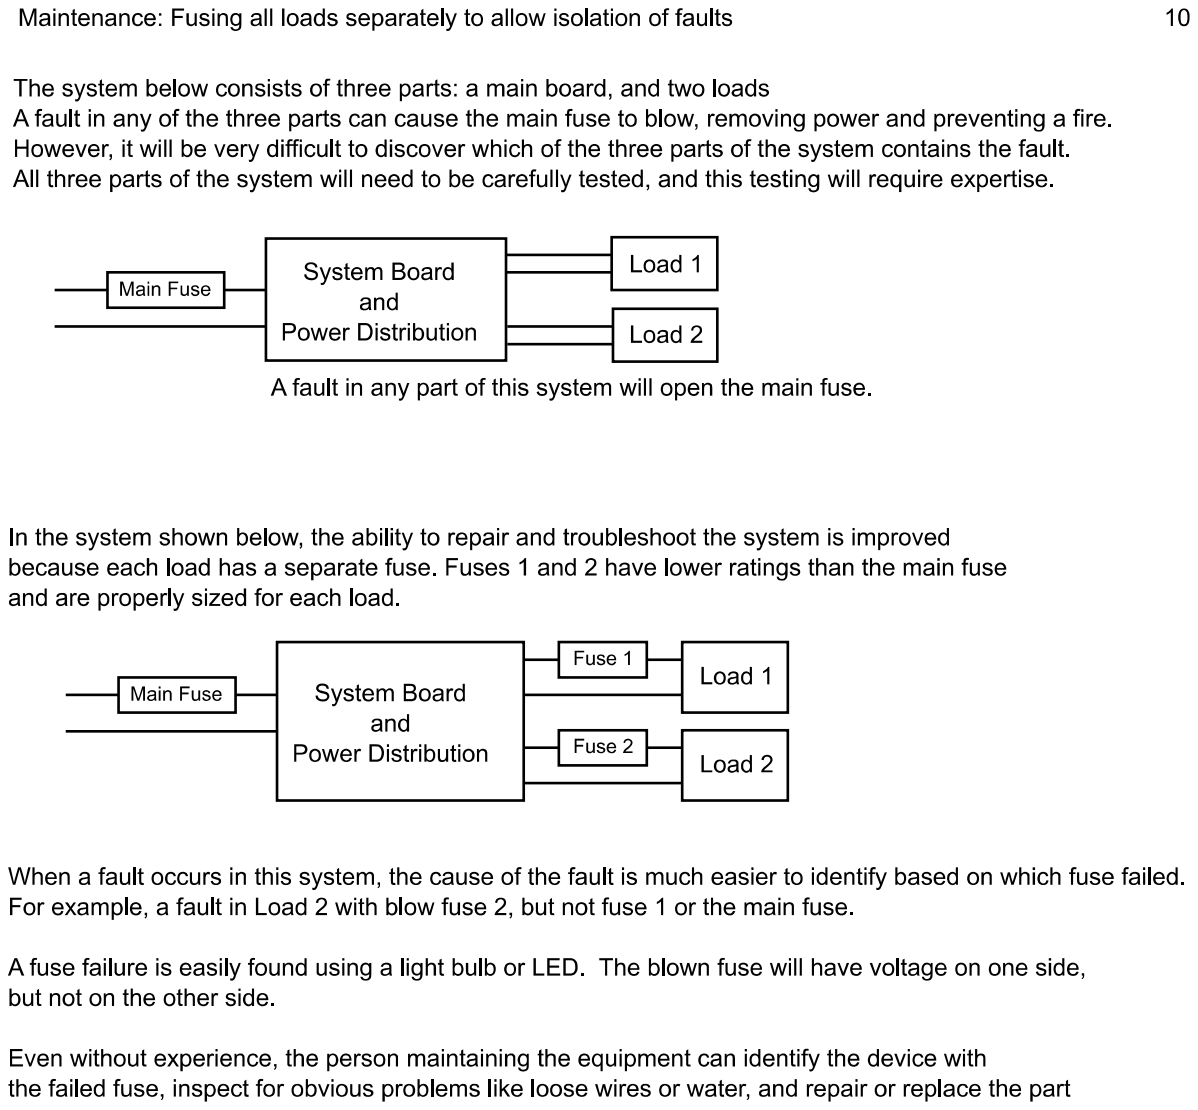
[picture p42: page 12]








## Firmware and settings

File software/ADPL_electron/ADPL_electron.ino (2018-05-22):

/* ADPL_complete.ino
 *
 * LICENSE: Apache v2.0 (see LICENSE file)
 *
 * Copyright (c) 2015--2018 Duke University
 * Mark Palmeri
 * Aaron Forbis Stokes
 * Graham Miller
 * Daniel Hull
 * Cal Nightingale
 * Suyash Kumar
 * Jawad Hoballah
 */

SYSTEM_MODE(SEMI_AUTOMATIC);  // optimize cellular data usage with SEMI_AUTOMATIC mode
//SYSTEM_MODE(MANUAL);     // Use this mode to prevent connecting to the cellular network
SYSTEM_THREAD(ENABLED);  // parallel user and system threads
                         // to allow function w/o cell connectivity

unsigned long SYS_VERSION;

#include "PublishDataCell.h"
PublishDataCell cellPublisher;

#define PUBLISH_DELAY 150000  // 2.5 min b/w variable publish

#include "SD/SdFat.h"
#include "PublishDataSD.h"
#include "pin_mapping.h"
// Software SPI.  Use any digital pins.
// MISO => B1, MOSI => B2, SCK => B0, CS => B4
SdFatSoftSpi<SD_DO_PIN, SD_DI_PIN, SD_CLK_PIN> sd;
File sdFile;
PublishDataSD sdPublisher;
char sdcard_datafile[] = "adpl_data.txt";

#include "TempProbe.h"
TempProbe tempHXCI("HXCI", HXCI);
TempProbe tempHXCO("HXCO", HXCO);
TempProbe tempHTR("HTR", HTR);
TempProbe tempHXHI("HXHI", HXHI);
TempProbe tempHXHO("HXHO", HXHO);
TempProbe tempExhaust("Exhaust", EXH);

#include "Valve.h"
Valve valve(VALVE);

#include "Ignitor.h"
Ignitor ignitor(IGNITOR);
#define INCINERATE_LOW_TEMP 68  // will be 68 in field
#define INCINERATE_HIGH_TEMP 72 // will be 72 in field
#define IGNITOR_TEMP_INCREASE_FLOOR 10 // if this amount of temp increase, then don't fire ignitor
#define EXHAUST_TEMP_THRESHOLD 68     // the exhaust temp dropping below this indicates that the ignitor has gone out

#include "Pump.h"
Pump pump(PUMP);
#define KEEP_PUMP_ON_TIME 10000     // 10s on every 30min
#define KEEP_PUMP_OFF_TIME 1790000   // 30min-10s off time (29 min 50s)

#include "Bucket.h"
#define VOLUME 250.0 //300 mL, varies by location
#define OPTIMAL_FLOW 40.0 //5.0 L/hr was previous setting, varies by location
Bucket bucket(BUCKET, VOLUME, OPTIMAL_FLOW);

#include "error_codes.h"

#include "PinchValve.h"
PinchValve pinchValve(DIR, STEP, SLEEP, UP, DOWN, RESET);
#define PUSH_BUTTON_RESOLUTION 1.0 // mm of movement
#define MAX_POSITION 5.0 // in mm
#define MIN_POSITION 0.0 // in mm
#define BATCH_MOVEMENT 4.0 // mm of movement, added for batch tests

// initialize some time counters
unsigned long currentTime = 0;
unsigned long last_publish_time = 0;
unsigned long prev_exhaust_temp = 0;
int temp_count = 1;
int write_address = 0;

// Determine existence of SD card via the CD pin
bool SDCARD = (bool)digitalRead(SD_CD_PIN);

void setup() {

    Serial.begin(9600);
    pinchValve.position = EEPROM.get(write_address, pinchValve.position);
    Particle.variable("currentTime", currentTime);
    // count bucket tips on one-shot rise
    attachInterrupt(BUCKET, bucket_tipped, RISING);
    // collect the system firmware version to fetch OTA
    SYS_VERSION = System.versionNumber();
    Particle.variable("SYS_VERSION", SYS_VERSION);
    // sense buttons
    attachInterrupt(UP, up_pushed, FALLING);
    attachInterrupt(DOWN, down_pushed, FALLING);
    attachInterrupt(RESET, res_pushed, FALLING);

    // Initialize SdFat or print a detailed error message and halt
    // Use half speed like the native library.
    // Change to SPI_FULL_SPEED for more performance.
    if(SDCARD){
        if (!sd.begin(SD_CS_PIN, SPI_HALF_SPEED)) {
            logError(SD_INIT_FAIL);
        }
        else {
            sdPublisher.inserted = true;
        }
    }
}

void loop() {
    // read the push buttons
    currentTime = millis();

    // check if SD card is still present; if not
    SDCARD = (bool)digitalRead(SD_CD_PIN);
    if (!SDCARD && sdPublisher.inserted){
        sdPublisher.inserted = false;
    }
    if (SDCARD && !sdPublisher.inserted) {
        if (!sd.begin(SD_CS_PIN, SPI_HALF_SPEED)) {
            logError(SD_INIT_FAIL);
        }
        else {
            sdPublisher.inserted = true;
        }
    }

    // rotate through temp probes, only reading 1 / loop since it takes 1 s / read
    temp_count = read_temp(temp_count);
    if ((currentTime - last_publish_time) > PUBLISH_DELAY) {
        bool publishedCell;
        bool publishedSD;

        if (Particle.connected()) { //Returns true if the device is connected to the cellular network
            if (cellPublisher.publish(tempHXCI.temp, tempHXCO.temp, tempHTR.temp, tempHXHI.temp,
                                      tempHXHO.temp, tempExhaust.temp, int(valve.gasOn),
                                      int(bucket.tip_count))) {
                publishedCell = true;
            } else {
                logError(CELL_PUB_FAIL);
                publishedCell = false;
            }

            // if an sd card is present AND the file is opened for reading
            // successfully AND there is data in it, THEN  close the file so
            // as not to interfere with the pushToCell function
            if (SDCARD && sdFile.open(sdcard_datafile, O_READ) && sdFile.peek() != -1) {
                sdFile.close();
                if (sdPublisher.pushToCell(sdFile)) {
                    if (sd.remove(sdcard_datafile)) {
                    } else {
                        logError(SD_FILE_REMOVE_FAIL);
                    }
                } else {
                    logError(SD_DATA_PUSH_FAIL);
                }

            }
        } else if (SDCARD){ //only publish to SD card if there is no cell connection
            if(sdPublisher.publish(tempHXCI.temp, tempHXCO.temp, tempHTR.temp, tempHXHI.temp, tempHXHO.temp,
                                   tempExhaust.temp, int(valve.gasOn), int(bucket.tip_count), sdFile)){
                publishedSD = true;
            } else {
                logError(SD_PUB_FAIL);
                publishedSD = false;
            }
        } else {
            logError(TOTAL_PUB_FAIL);
        }
        if (publishedCell || publishedSD) {
            // reset the bucket tip count after every successful publish
            // (webserver will accumulate count)
            last_publish_time = millis();
            bucket.tip_count = 0;
        }
    }

    // measure temp, determine if light gas
    currentTime = millis();
    if (tempHTR.temp <= INCINERATE_LOW_TEMP && !valve.gasOn) {
        if (ignitor.allow) {
            valve.open();
            ignitor.fire();
        }
        else {
            if (ignitor.resumeReignitionTime < currentTime) {
                ignitor.allow = true;
                ignitor.repeatRefireAttempts = 0;
            }
        }
    }

    if(valve.gasOn) {
        if (tempHTR.temp >= INCINERATE_HIGH_TEMP) {
            valve.close();
        }
        // if exhaust temp < 0, then thermistor probably broken
        // default to firing ignitor every 15 min
        else if(tempExhaust.temp < 0.0) {
            if((currentTime - ignitor.timeLastFired) > ignitor.brokenTempDelay) {
                ignitor.fire();
            }
        }
        else if((currentTime - ignitor.timeLastFired) > ignitor.refireDelay &&
                tempExhaust.temp < EXHAUST_TEMP_THRESHOLD &&
	            (tempExhaust.temp - prev_exhaust_temp) < IGNITOR_TEMP_INCREASE_FLOOR) {
                    if (ignitor.repeatRefireAttempts <= ignitor.repeatRefireLimit) {
                        ignitor.fire();
                        ignitor.repeatRefireAttempts++;
                        tempExhaust.read();
                        prev_exhaust_temp = tempExhaust.temp;
                    }
                    else {
                        valve.close();
                        ignitor.resumeReignitionTime = currentTime + ignitor.resumeReignitionDelay;
                        ignitor.allow = false;
                        logError(IGNITOR_FAIL);
                    }
        }
    }

    currentTime = millis();
    if (!pump.pumping && (currentTime - pump.offTime) > KEEP_PUMP_OFF_TIME) {
        pump.turnOn();
    }
    else if (pump.pumping) {
        if ((currentTime - pump.onTime) > KEEP_PUMP_ON_TIME) {
            pump.turnOff();
        }
    }

    // flag variables changed in attachInterrupt function
    if(pinchValve.movedown) {
        pinchValve.shiftDown(pinchValve.resolution);
        EEPROM.put(write_address, pinchValve.position);
    }
    if(pinchValve.moveup) {
        pinchValve.shiftUp(pinchValve.resolution);
        EEPROM.put(write_address, pinchValve.position);
    }

    // unclog if no tip in a long while
    // open all the way up and come back to optimum
    currentTime = millis();
    if(((currentTime - pinchValve.wait_time) > ((3600 * VOLUME) / OPTIMAL_FLOW)) && !pinchValve.isitup) {  // Gives all times in ms
        pinchValve.moveup = true;
        pinchValve.resolution = BATCH_MOVEMENT; // 3mm , make variable
        pinchValve.wait_time = millis();
    }
    if(bucket.tip) {
        if(pinchValve.isitup) {
            pinchValve.movedown = true;
            pinchValve.resolution = BATCH_MOVEMENT; // 3mm , make variable!
        }
        pinchValve.moveup = false;
        bucket.tip = false;
        pinchValve.wait_time = millis();
    }
}


int read_temp(int temp_count) {
    switch (temp_count) {
        case 1:
            tempHXCI.read();
            temp_count++;
            break;
        case 2:
            tempHXCO.read();
            temp_count++;
            break;
        case 3:
            tempHTR.read();
            temp_count++;
            break;
        case 4:
            tempHXHI.read();
            temp_count++;
            break;
        case 5:
            tempHXHO.read();
            temp_count++;
            break;
        case 6:
            tempExhaust.read();
            temp_count = 1;
            break;
    }
    return temp_count;
}

void bucket_tipped() {
    bucket.tipped();
    bucket.tip = true;
}

void res_pushed() {
    pinchValve.position = 0.0;
    pinchValve.wait_time = millis();
    pinchValve.isitup = false;
}

void up_pushed() {
    pinchValve.moveup = true;
    pinchValve.resolution = PUSH_BUTTON_RESOLUTION;
}

void down_pushed() {
    pinchValve.movedown = true;
    pinchValve.resolution = PUSH_BUTTON_RESOLUTION;
}

void logError(int errorCode) {
    sdPublisher.logError(errorCode);
    if(Particle.connected()){
        Particle.publish("ERROR", (char*)errorCode);
    }
}

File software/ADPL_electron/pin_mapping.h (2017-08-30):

// Define GPIO pins (Particle Electron) by function
#define HXCI A0 // Heat Exchanger Cold Inlet
#define HXCO A1 // Heat Exchanger Cold Output
#define HTR A2  // Heater
#define HXHI A3 // Heat Exchanger Hot Inlet
#define HXHO A4 // Heat Exchanger Hot Outlet / Changed to A5 from A4 pin burnt
#define EXH A5 // Heater Exhaust
#define PUMP D0
#define VALVE D1
#define IGNITOR D2
#define SLEEP D3
#define STEP D6
#define DIR D5
#define UP B5
#define DOWN C3
#define RESET C2
#define BUCKET C4
#define SD_CD_PIN B4
#define SD_CS_PIN B3
#define SD_DI_PIN B2
#define SD_DO_PIN B1
#define SD_CLK_PIN B0

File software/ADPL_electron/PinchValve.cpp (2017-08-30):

/*
 * PinchValve.cpp - pinch valve control system
 */

#include "application.h"
#include "PinchValve.h"

PinchValve::PinchValve(int dir_pin, int step_pin, int sleep_pin, int up_pin, int down_pin, int res_pin) {
    pinMode(dir_pin, OUTPUT);
    pinMode(step_pin, OUTPUT);
    pinMode(sleep_pin, OUTPUT);

    pinMode(up_pin, INPUT_PULLUP);
    pinMode(down_pin, INPUT_PULLUP);
    pinMode(res_pin, INPUT_PULLUP);

    _dir_pin = dir_pin;
    _step_pin = step_pin;
    _sleep_pin = sleep_pin;

    _STEPSPERMM = (_FULLSTEPSPERTURN/_MMPERTURN)*_MICROSTEP;

    digitalWrite(_sleep_pin, LOW);
    bool moveup = false;
    bool movedown = false;
    bool isitup = false;
    double position = 0.0;
    double resolution = 0.0;
    Particle.variable("position", position);
    int clog_counter = 0;
}

void PinchValve::shiftDown(double res) {
    int turn_count = res*(_STEPSPERMM); // 1600 steps/2mm movement
    digitalWrite(_dir_pin, LOW);
    digitalWrite(_sleep_pin, HIGH);
    for (int i = 0; i < turn_count; i++) {
        digitalWrite(_step_pin, HIGH);
        delayMicroseconds(_DELAY);
        digitalWrite(_step_pin, LOW);
        delayMicroseconds(_DELAY);
    };
    movedown = false;
    isitup = false;
    position -= res;
    digitalWrite(_sleep_pin, LOW);
};

void PinchValve::shiftUp(double res) {
    int turn_count = res*(_STEPSPERMM); // 1600 steps/2mm movement
    digitalWrite(_dir_pin, HIGH);
    digitalWrite(_sleep_pin, HIGH);
    for (int i = 0; i < turn_count; i++) {
        digitalWrite(_step_pin, HIGH);
        delayMicroseconds(_DELAY);
        digitalWrite(_step_pin, LOW);
        delayMicroseconds(_DELAY);
    };
    moveup = false;
    isitup = true;
    position += res;
    digitalWrite(_sleep_pin, LOW);
};

void PinchValve::unclog(float unclog_resolution) {
    shiftUp(unclog_resolution);
    shiftDown(unclog_resolution);
    shiftUp(unclog_resolution);
    shiftDown(unclog_resolution);
    clogCounting++;
}

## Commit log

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2015-03-10 replace individual ignitor pin changes with a fireIgnitor() function
2015-03-10 replace delay for 15 ignition interval with millis() checks
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2015-03-10 reworked pump logic; issue #3
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2015-03-11 restrict header initialization to static const vars; issue #15
    [Ignitor.h]
2015-03-11 var type fix; extend temp sample delay; issue #8
2015-03-11 reinitialize sample and mean vars for each read; issue #8
2015-03-11 reinitialize sample and mean vars for each read; shorten delay; issue #8
2015-03-11 TESTING: serial print statements; issue #8
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2015-03-11 TESTING: more inline serial printing for a reduced num of samples; issue #8
2015-03-11 fix println syntax; issue #8
2015-03-11 remove sum of subsequent samples; issue #8
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2015-03-13 set gas valve to OFF when started; test for valve status when too cold (#8)
2015-03-14 convert level sensor to current (mA), issue #13
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2016-02-07 this is a more formal flow chart and diagram of the testing apparatus
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2016-03-01 i realized that i need to redo this but I wanted to push in case I want to access this version.
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2016-03-20 updated photon layout and a picture of the control box layout of power lines
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2016-03-28 the layout for the board. gray are connectors, boxed in are hardwired components
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2016-03-28 the photon board 1 is the version im using. it has all the components
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2016-04-01 correct tempProbe6 & 7 definition and read probes
2016-04-01 correct C++ syntax for Bucket class
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2016-04-18 Implemented GET records by location and GET records by location and pin
2016-04-20 Added test twilio integration that texts back latest probe 10 temp measurement!
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2016-05-01 publish bucket events with temps
    * generalize TEMP_PUBLISH_DELAY -> PUBLISH_DELAY
    * generalize last_temp_publish -> last_publish_time
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2016-05-02 change temp probe num IDs -> short names (closes #40)
2016-05-02 add starting point for BoM (issue #20)
2016-05-02 rm more legacy comments; complete pin mapping (issue #45)
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2016-05-03 fix BUCKET publish with 2 s delay after 4 publish events (closes #48)
2016-05-03 change bucket publish event to be on demand of a detected tip
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2016-05-18 FIX: bucket pin OUTPUT -> INPUT
2016-05-18 add new Durham-2 device (Durham-1 was damaged)
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2016-05-18 remove timestamp from bucket publish since that comes for free on the server side
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2016-05-25 FIX: reset bucket.tipped after publish
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2016-06-10 Implemented Avg Temp dash item, styled Dashboard, closed #54 (except bucket tips, which gets its own new issue for reasons)
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2016-10-15 Add files via upload
    schematic in altium
    [ADPL.SchDoc]
2016-10-15 Add files via upload
    using Altium
    [ADPL.SchDoc]
2016-10-19 Add files via upload
    Whole layout
    [ADPL Wiring Diagram.SchDoc]
2016-10-26 rm outdated hardware schematic
    [ADPL.SchDoc]
2016-10-31 add latest BOM as generated by Designer
    [ADPL Wiring Diagram.xlsx]
2016-11-08 add latest schematic from Aaron
    Updated wiring diagram with power supply protection capacitors, TVS
    diode, upgraded BJTs, and relays. Relays on diagram not exact but Part#
    in description is correct - symbol is for SPDT, but I have DPDT.
    [ADPL Wiring Diagram.SchDoc]
2016-11-12 correct wiring of one-shot
    [ADPL Wiring Diagram.SchDoc]
2016-11-12 cleanup legacy Arduino/Photon files (issue #75)
2016-11-14 X-axis max 1 ms.(null),Same with X-axis max 500 ms.(null) ,O-scope reading of TimerBlox output signal. X-axis max 5s, Y-axis max 4V.(null)
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2016-11-15 read only 1 temp / loop (issues #61, #78)
    * execute 1 temp read / loop since each temp read takes ~1 s
    * loop time reduced from ~5.25 s to ~1.0 s
    [ADPL_electron.ino]
2016-11-15 implement bucket tip count as an interupt (issue #78)
    [ADPL_electron.ino]
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2016-11-16 addition of bypass caps
    [ADPL.SchDoc]
2016-11-23 add 2 new Kenya devices & rm damaged 1 (issues #82, #83)
2016-11-30 Update device-map.js
    Added new Kenya devices. Removed old Kenya and damaged Duke.
2016-11-30 Update controllers.js
    Re-ordered Avg Temp readings. Previously HXHO, HTR, HXHI, HXCI, HXCO. Now HXCI, HXCO, HTR, HXHI, HXHO. (this new arrangement is the order of the flow through the system)
2016-11-30 Delete ADPL Wiring Diagram.SchDoc
    'old version'
    [ADPL Wiring Diagram.SchDoc]
2016-12-01 Add files via upload
    This document is to provide context for overall project, constraints for control system design, and existing hardware descriptions. This, along with the wiring schematic, should provide someone witho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
2016-12-01 Update README.md
    Updated to what is current (level sensor no longer used, igniter duration shorter, added pump)
2016-12-01 Update Ignitor.h
    Decreased igniter on time from 5s to 1s. Initially 5s was used to be extra-sure that the flame would light, that was overkill. Due to igniter issues, decreasing the on time should limit our problems further. The 1s is still sufficient to light flame.
    [Ignitor.h]
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2016-12-01 India control system - Aug 2016
    Cell signal booster to left, circuit enclosure middle, igniter enclosure bottom right
2016-12-01 Version with minor changes from oo22's latest
    Moved one capacitor on power supply line, changed another to a directional capacitor (recommended by someone else). Made it so that relay part numbers are displayed on schematic so that a pdf version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
    [ADPL Controls System Wiring Schematic v2.SchDoc]
2016-12-07 replaced relays and added part number but it is hidden from view to not clutter the schematic
    [ADPL.SchDoc]
2016-12-07 had made this before but it was stuck in my local branch. This is the schematic for just the board
    [PCBBoardlayout.SchDoc]
2016-12-07 fully updated. version that will be made into PCB
    [ADPL.SchDoc, PCBBoardlayout.SchDoc]
2016-12-08 Schematic with some changes from AFS (see notes)
    1) Changed C1 symbol and C2 placement.
    2) Added R6 and Thermistor6. This allows us to add another temperature probe if later desired but costs nothing if it is not used.
    3) Changed labels for resistors to updated sequence.
    4) Changed Relay2 to same relay type at Relay1 (two switches). This makes ordering all parts easier and doesn't change cost, and that extra switch could someday be useful.
    5) Changed Relay3 back to old type. I realized new relay rated only up to 5A, less than what the pump uses. What I suggest for Relay3: Use the old relay type but do not include it on the PCB. On the PCB, include the BJT-diode-capacitor circuit and an e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
    [ADPL_afs.SchDoc]
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2016-12-08 Example data post-processing spreadsheet
    Hover over calculated column headings for explanations. Many of these values are based off daily average values. Primary calculated values are daily gas use and daily liquid flow. The tricky part of 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
    [Example_results.xlsx]
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2016-12-16 Shortened VALVE to V to save data
    [ADPL_electron.ino]
2016-12-18 added new relay and extra power sources
    [PCBBoardlayout.SchDoc]
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2017-01-05 added the changes Aaron made on 12/7 on ADPL_afd to this schematic. Did not include the change number 5.
    [ADPL.SchDoc]
2017-01-05 updated the relay with the old relay
    [ADPL.SchDoc]
2017-01-05 made same changes to PCB layout
    [PCBBoardlayout.SchDoc]
2017-01-12 minor changes to make sure both schematics match
    [ADPL.SchDoc, PCBBoardlayout.SchDoc]
2017-01-12 Delete ADPL_afs.SchDoc
    this was a temporary file. All the changes here have been integrated into the most up to date schematic
    [ADPL_afs.SchDoc]
2017-01-12 Delete ADPL Controls System Wiring Schematic v2.SchDoc
    old file. cleaning up
    [ADPL Controls System Wiring Schematic v2.SchDoc]
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2017-01-18 Switched Kenya North devices
    Old North device (ADPLKenyaN3763) had damaged analog input pins. New device (ADPLKenyaN6833) installed on 1/18/17. Routing web-server to new device.
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2017-01-26 Updated wiring diagram w/ extra protection
    Components as suggested by Greg Mimmack. Bypass capacitors moved to 12V side of relays. Protection diodes between every external input and microcontroller to protect against +/- surges
    [ADPL_improved.SchDoc]
2017-01-27 Rework the bucket tip publishing
    * Integrate bucket tip publishing with temperature and valve status
    publishing.
    * Publish structure ``TEMPS`` is renamed to ``DATA``
    * Reset the bucket tip counter after each successful publish
    * Addresses issue #127, issue #65
    [ADPL_electron.ino]
2017-01-29 do not publish bucket.tip_count if 0 (issue #155)
    [ADPL_electron.ino]
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2017-01-30 added SPST components
    [ADPL.SchDoc, ADPL_improved.SchDoc]
2017-01-30 reorganization of files
    [ADPL.SchDoc, ADPL_improved.SchDoc, PCBBoardlayout.SchDoc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]
2017-01-30 fixed net issue:
    [ADPL_improved.SchDoc]
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2017-02-10 addition of easy driver, fixes #130
    [ADPL_improved.SchDoc]
2017-02-10 fixes #99
    [ADPL_improved.SchDoc]
2017-02-11 replacing relays, cleaning up that part of the circuit
    [ADPL_improved.SchDoc]
2017-02-11 clearing out old files
    [ADPL_improved.SchDoc]
2017-02-11 improved viewing of schematic
    [ADPL_improved.SchDoc]
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2017-02-11 initialization of ADPL project, rename ADPL file to V1, decision on diode D13,D14,D15, compile checks
    [ADPL.SchDoc, ADPLV1.SchDoc, ADPL_Project.PrjPcb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]
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2017-02-15 working toward moving data
    [ADPLV1.SchDoc]
2017-02-17 fixed voltage regulator, replaced SMTs, added info for switches, fixes #180
    [ADPLV1.SchDoc]
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2017-02-17 fixes #187, #171
    [ADPLV1.SchDoc]
2017-02-17 renaming version number
    [ADPLV1.1.SchDoc, ADPLV1.SchDoc]
2017-03-07 New device added in Kenya
    This device replacing Particle that had been damaged by older igniter. New igniter working well, so should be done with Particles getting fried.
2017-03-15 New Kenya-North device
    Damaged device at Kenya-North replaced. Should be final replacement due to old igniter issues.
2017-03-19 Fixes date display and bucket tip refresh on location change
2017-04-03 Manually re-initialize EventSource after a timeout in problematic situations
    [Example_results.xlsx]
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2017-06-06 Pinch Valve Feedback Control [PR #209]
    Pinch valve feedback control to maintain more constant water flow via bucket tips.
    * added pinch valve functionality
    * utilize EEPROM write of last position of the pinch valve so that system reset doesn't cause functionality issues (closes #208)
    * closes #129, closes #142, closes #143, closes #159
    [ADPL_electron.ino, PinchValve.cpp, PinchValve.h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]
2017-06-28 New device in Kenya (#222)
    Damaged Kenya-North. Replaced with new device.
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2017-07-05 New device at Kenya-Central (#224)
    Old Central device damaged, replaced with new. Remove testing device.
2017-07-07 Fixed bracket syntax
2017-07-17 repo clean-up / reorganization (#238)
    * reorganize directory layout
    * rm outdated files
    * rm lots of outdated files (preserved in git history)
    [ADPL.SchDoc, ADPL_improved.SchDoc, PCBBoardlayout.SchDoc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]
2017-08-07 Updating notes for current conditions (#249)
    * Updating notes for current conditions
    * Fix spelling mistake
2017-08-30 SDcard_IgnitorThermistor
    * SD card data and error writing for offline units (closes #210)
    * add local SD library (closes #212)
    * update pin mappings
    * refactored publish() (fixes issues #217, #216, #215, #214)
    * implemented pushToCell function
    * only publishes to SD if no cell connection
    * add publish error codes (error_codes.h)
    * fix pinch valve logic (closes #250)
    * try to more robustly deal with hot plug/remove (closes #252)
    * pinchValve attributes up/down renamed to moveup/movedown to clarify
    that they indicate intention to move, not state of valve
    * isitup attribute added to indicate the actual state of the valve,
    which is not just a binary up/down
    * r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
    [ADPL_electron.ino]
2017-09-08 Revert "make high temp explicitly float (#262)"
    This reverts commit dc29853f40aea4c4be1b39a34fed40f9ece9c2c2.
    Temperature does not get set to 100.0 if the temperature was read as
    negative.
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2017-09-18 res_pushed no longer movesdown (closes #265)
    [ADPL_electron.ino]
2017-09-18 fire ignitor every 15 min when exhaust temp dead
    A broken exhaust thermistor could cause the MCU to fire the ignitor
    too much; instead of that, default to the original fire-every-15 min
    approach when the gas is on but the overall temperature is too low.
    [ADPL_electron.ino, Ignitor.h]
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2018-01-21 Display Bucket Tips as Flow Rate (#278)
    * Converted bucket tips to flow rate. This closes Issue #268
    * Corrected conversion calculation (converts after all bucket tips are fetched). Modified decimal precision based on correct tip conversion.
    * Remove parens
2018-02-21 New device in Kenya-Central
    Old device had damaged pin A5. We now need all 6 A# pins
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2018-05-19 [WIP] add exhaust temp to publish/save str (closes #267) (#288)
    * add exhaust temp to publish/save str (closes #267)
    * tempExhaust.temp is now published by cell
    * tempExhaust.temp is now saved to the SD card
    * note - this commit does not optionally publish/save the exhaust temp;
    if the exhaust temp is bogus, it will still consume published bytes
    * rm no_bucket data string option (closes #290)
    * fix variable input to SD save and char* cast to cell publish
    [ADPL_electron.ino]
2018-08-23 Implement heartbeat-based EventSource connection reset (#299)
    This should address #156 by creating a heartbeat timer that will reset the SSE connection to particle if a certain number of messages are not received every heartbeat interval.
2021-01-26 FIX SECURITY
    CVE-2020-28481
    moderate severity
    Vulnerable versions: < 2.4.0
    Patched version: 2.4.0
    The package socket.io before 2.4.0 are vulnerable to Insecure Defaults
    due to CORS Misconfiguration. All domains are whitelisted by default.
    This security volnerability was auto-identified by the GitHub
    Dependabot.
2022-08-09 Fix prototype pollution Schema.path in automattic/mongoose.
    Mongoose is a MongoDB object modeling tool designed to work in an
    asynchronous environment.\n\nAffected versions of this package are
    vulnerable to Prototype Pollution. The Schema.path() function is
    vulnerable to prototype pollution when setting the schema object. This
    vulnerability allows modification of the Object prototype and could be
    manipulated into a Denial of Service (DoS) attack.
    Closes dependabot #4.
